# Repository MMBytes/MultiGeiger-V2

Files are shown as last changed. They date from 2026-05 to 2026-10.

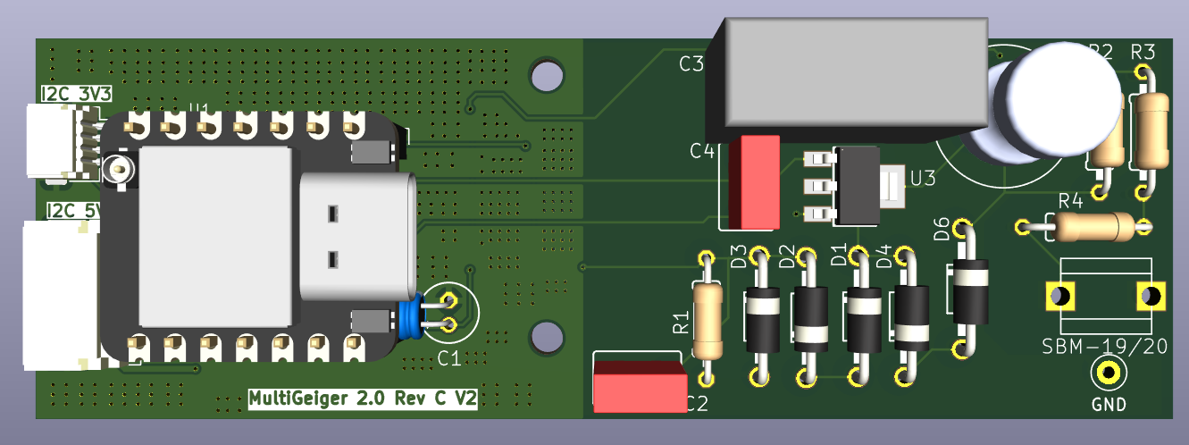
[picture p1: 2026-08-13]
Hardware/Revision_C/Deliverables/Renderings/3D TOP View.png

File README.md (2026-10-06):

# MultiGeiger V2 (ESP-IDF native)

A ground-up C rewrite of the [MultiGeiger](https://github.com/ecocurious2/MultiGeiger) radiation sensor firmware, ported from Arduino / PlatformIO to **native ESP-IDF 6.0**. Runs on **eleven** ESP32 / ESP32-S3 / ESP32-C5 board variants with a wide selection of optional environmental, particulate, noise, and ambient-light sensors. Uploads to **nine** public back-ends and publishes to MQTT (with Home Assistant Discovery) and remote syslog.

See the [releases page](https://github.com/MMBytes/MultiGeiger-V2/releases) for the latest build and per-release notes.

## What it does

- Counts Geiger pulses and computes CPM and µSv/h with a **runtime-selectable tube type** (Si22G / SBM-20 / SBM-19 / Unknown) configured on `/config` — no rebuild required.
- Drives the HV flyback boost converter from on-chip GPIO timing (no Arduino dependency).
- Optional **environmental sensing**: temperature, humidity, pressure, sea-level-adjusted pressure.
- Optional **PM (particulate matter)**: PM1 / PM2.5 / PM4 / PM10 plus number concentrations and typical particle size.
- Optional **noise**: LAeq / LAmin / LAmax dB(A).
- Optional **ambient light**: lux (two sensor families supported).
- Optional **air-quality index**: NOx index from a Sensirion SGP41 (log, `/status` and MQTT/Home Assistant only — no upload target carries it).
- Optional **standalone CSV logging** to a microSD card: one row of every attached sensor's readings per cycle, timestamped from the GNSS clock, for nodes deployed without a network.
- **Battery telemetry** (voltage, state of charge) on boards with an onboard MAX17048 fuel gauge.
- Optional **GNSS position display** — auto-detected PA1010D or MAX-M10S receiver shows fix, satellites, HDOP, lat/lon (OpenStreetMap link), and altitude on `/status`; display-only (NTP is the sole time source).
- Per-cycle upload (default 150 s, configurable 10 s – 1 h) to any subset of **nine** public back-ends.
- **MQTT publish** with 24 Home Assistant Discovery entities, three TLS modes including custom CA.
- **Remote syslog** (UDP 514, RFC 5424) for centralised log aggregation.
- **Hourly FTP/FTPS** upload of the on-device log ring buffer.
- **CPM history graph** on `/status` — 60-minute and 24-hour inline SVG with gridlines and a `HH:MM` time axis; rolling **cpm5 / cpm15** 5- and 15-minute averages fed to GMCMap and ThingSpeak.
- **Web UI** at `http://<device>/` — `/config` (settings), `/status` (live metrics + per-target TX stats + per-sensor presence + CPM graph), `/update` (OTA), `/log` (in-memory log ring). On PSRAM boards, ticking **Serve the web UI over HTTPS** on `/config` (off by default; applies after "Save and restart") moves the UI to `https://<device>/` with a per-device self-signed certificate (`/cert.pem` to import, SHA-256 fingerprint on `/`); port 80 then keeps `/log`, `/api/env` and `/cert.pem` plain and redirects everything else.
- **Crash recovery**: ESP-IDF panic handler writes a coredump to a dedicated flash partition; downloadable post-reboot via `GET /coredump.elf` (no USB required).
- **OLED status display** (SSD1306 128×64, also supports SparkFun SerLCD I²C and NeoPixel tick on supported boards).
- **NTP** with up to three configurable servers and POSIX TZ string.

## Supported hardware

### Boards (eleven build targets)

| Build target | MCU / module | Flash | Notes |
|---|---|---|---|
| `heltec_v2` | Heltec WiFi Kit 32 V2 (ESP32-D0WDQ6) | 8 MB | Onboard SSD1306 OLED. The original target — most production deployments. |
| `heltec_v2_4mb` | Heltec WiFi Kit 32 V2 clone | 4 MB | Same module silicon, smaller flash. Tight on heap during OTA — see V2.4.13 teardown logic in `main.c`. |
| `feathers3_d` | Unexpected Maker FeatherS3 with display (ESP32-S3) | 8 MB | Two STEMMA QT connectors (STEMMA1 on IO8/IO9, STEMMA2 LDO-gated on IO15/IO16). External I²C OLED via STEMMA. PSRAM — WiFi/lwIP/mbedTLS offloaded to PSRAM for sustained heap headroom. |
| `adafruit_qtpy_esp32_pico` | Adafruit QT Py ESP32-PICO | 8 MB | Compact form factor. Optional NeoPixel tick on pulse. PSRAM. |
| `seeed_xiao_esp32s3` | Seeed Studio XIAO ESP32-S3 | 8 MB | Tiny 21×17.5 mm — shares QT Py form factor + Geiger pin map (A0 / A1 / SCK), so one PCB design works for both. Onboard user LED blinks per pulse. PSRAM. |
| `heltec_wifi_lora32_v4_r2` | Heltec WiFi LoRa 32 V4 — base/R2 variant (ESP32-S3R2) | 16 MB | Third-party PCB: the standard Multigeiger V2 mainboard populated with this module instead of the Heltec V2. Onboard SSD1315 OLED on a dedicated, always-on I²C bus separate from the env-sensor bus. 2 MB in-package PSRAM. **LoRaWAN uplink** (V2.6.23+) via an onboard SX1262 (RadioLib 7.2.1, OTAA/Class A) — see the LoRaWAN section below. |
| `sparkfun_thing_plus_esp32s3` | SparkFun Thing Plus ESP32-S3, WRL-24408 (ESP32-S3-MINI-1) | 4 MB | Second-source MCU for the FeatherS3-D-format carrier PCB — same Feather footprint, drop-in alternative to `feathers3_d` on the same board. External I²C OLED via Qwiic, onboard MAX17048 fuel gauge, onboard WS2812 NeoPixel (always-on rail, no power-gate GPIO). 2 MB in-package PSRAM. |
| `sparkfun_thing_plus_esp32c5` | SparkFun Thing Plus ESP32-C5, WRL-30678 (ESP32-C5-WROOM-1) | 8 MB | First single-core/RISC-V target. Its own Thing Plus carrier (not a drop-in for the FeatherS3-D board). External I2C OLED via Qwiic, onboard MAX17048 fuel gauge, onboard WS2812 NeoPixel (always-on rail via pull-up, no power-gate GPIO). 8 MB in-package PSRAM. |
| `adafruit_esp32s3_tft_feather` | Adafruit ESP32-S3 TFT Feather, #5483 (ESP32-S3) | 4 MB | Shares the FeatherS3-D-format carrier PCB. Onboard 240×135 ST7789 color SPI TFT (esp_lcd, 5-page rotation only — no radiation single-page layout) instead of an external I²C OLED; shared TFT/STEMMA-QT power gate on GPIO21. Onboard WS2812 NeoPixel. 2 MB external QSPI PSRAM (feathers3_d-class, not in-package). |
| `adafruit_esp32_feather_v2` | Adafruit ESP32 Feather V2, #5400/#5900 (ESP32-PICO-MINI-02) | 8 MB | Second-source MCU (original ESP32 LX6, not S3) for the Feathers3d_new_pcb shared carrier. External I²C OLED wired to the header SDA/SCL pins, NOT the board's onboard STEMMA QT connector — NEOPIXEL_I2C_POWER only gates that connector's own regulator, and it isn't driven until neopixel_init() runs after sensor/display probing, so a display wired to the connector would never be found. Onboard WS2812 NeoPixel. No fuel gauge, so no battery telemetry (the board's GPIO35 battery divider is not read). 2 MB in-package PSRAM. |
| `adafruit_esp32s3_feather_4mb_2mbpsram` | Adafruit ESP32-S3 Feather, 4MB/2MB PSRAM, STEMMA QT, #5477 (ESP32-S3) | 4 MB | Shares the Feathers3d_new_pcb carrier PCB. No onboard display — external I²C OLED via STEMMA QT, probe-detected. Onboard MAX17048 fuel gauge, onboard WS2812 NeoPixel. Single STEMMA QT I²C bus power-gated on GPIO7 (no always-on bus) — same pattern as `adafruit_esp32s3_tft_feather`'s gate, different GPIO. Onboard red "#13" LED (not the NeoPixel) flashes on each Geiger pulse. 2 MB external QSPI PSRAM (feathers3_d-class, not in-package). |

Every build takes a `-DBOARD=<target>` argument — see [Build from source](#build-from-source). All boards share the same `main/` source tree; differences are isolated in per-board `sdkconfig.defaults.<board>` and HAL pin map. PSRAM boards additionally include `sdkconfig.defaults.psram` (WiFi roaming app + PSRAM offload knobs).

### LoRaWAN uplink (heltec_wifi_lora32_v4_r2 only)

OTAA/Class A uplink over an onboard SX1262 (RadioLib 7.2.1), configured in a dedicated **`/config` LoRaWAN section** (all-region frequency-plan dropdown, DevEUI/JoinEUI/AppKey entry, join status; session keys persist in NVS across reboots). Ports 1 and 2 are byte-identical to the Multigeiger V1.9 Arduino firmware's TTN uplinks — paste `docs/ttn_payload_formatter.js` into TTN Console as a Custom Javascript payload formatter to decode them. Respect the LoRaWAN Fair Use Policy: keep the transmission interval at **5 minutes or longer** when LoRaWAN is enabled.

### Geiger tube

The tube type is a runtime **`/config` dropdown** — no rebuild required to switch tubes:

| Option | cps → µSv/h | Notes |
|---|---|---|
| **Unknown** | — (dose suppressed) | CPM reported; µSv/h field omitted from all uploads |
| **SBM-20** | 1 / 2.47 | Energy-compensated cylindrical tube |
| **SBM-19** | 1 / 9.81888 | Large pancake, lower background |
| **Si22G** | 1 / 12.2792 | **Default** — empirical vs. odlinfo.bfs.de reference |

Calibration factors from the upstream MultiGeiger (`ecocurious2 / t-pi tube.cpp`). The selected tube is shown on the `/status` Radiation card and in the boot config dump. Changing it in `/config` applies live (no reboot). CPM counting, HV timing, and dead-time gating are all tube-agnostic.

### Environmental sensors (auto-detected on I²C)

| Sensor | Address | Provides | Notes |
|---|---|---|---|
| **SHT45** | 0x44 | Temperature, humidity | Sensirion successor to SHT3x. PTFE filter variant supported. |
| **BME280** | 0x76 / 0x77 | Temperature, humidity, pressure | Bosch — original upstream sensor. |
| **BME688** | 0x76 / 0x77 | Temperature, humidity, pressure | Bosch — gas channel currently unused. |
| **BMP390** | 0x76 / 0x77 | Temperature, pressure | Bosch — high-accuracy barometric. |
| **BMP581** | 0x46 / 0x47 | Temperature, pressure | Bosch latest-gen — sub-Pa noise floor. |

The driver mix lets a node combine, e.g., SHT45 (best RH) + BMP581 (best pressure) on the same bus. The firmware picks the right reading per measurand from whichever sensors responded at boot.

### Specialty sensors (auto-detected on I²C)

| Sensor | Address | Provides | Notes |
|---|---|---|---|
| **Sensirion SPS30** | 0x69 | PM1 / PM2.5 / PM4 / PM10 mass, N05–N10 number concentrations, typical particle size | Adds the SPS30_* field group to all upload targets. |
| **hbitter DNMS** | 0x55 | LAeq / LAmin / LAmax dB(A) | Nettigo NAM-style Teensy-based noise module. Adds DNMS_noise_* fields. |
| **ALS-PT19** | (analog) | Ambient light (lux) | Onboard FeatherS3-D photodiode on ADC1_CH3. |
| **VEML7700** | 0x10 | Ambient light (lux) | Vishay I²C, alternative to ALS-PT19. |
| **PA1010D** | 0x10 | GNSS position + time (display-only) | Adafruit 4415 (MediaTek MT3333). Detected by live NMEA sniff — disambiguates from a VEML7700 at the same address. |
| **MAX-M10S** | 0x42 | GNSS position + time (display-only) | SparkFun Qwiic (u-blox DDC). Factory chip serial queried via UBX-SEC-UNIQID and shown on `/status`. |
| **Sensirion SGP41** | 0x59 | NOx index | VOC + NOx gas sensor; only the NOx index is surfaced (log / `/status` / MQTT). Runs its own sampling task — it needs a 1 Hz conditioning cadence. |
| **MAX17048** | 0x36 | Battery voltage, state of charge | Onboard fuel gauge on the FeatherS3-D, SparkFun Thing Plus and Adafruit Feather boards that carry one. |

A microSD socket (SDMMC 4-bit on ESP32-S3 boards, SPI where the chip has no SDMMC host) enables the standalone CSV logger when present; see `main/sd_logger.h` for the file layout.

### Displays

- **SSD1306 OLED** 128×64, I²C 0x3C or 0x3D — auto-probe both addresses (V2.4.19).
- **SparkFun SerLCD** (I²C variant) — alternative line-based display.
- **NeoPixel** tick-per-pulse on supported boards (configurable colour / brightness via `display_mode`).
- Built-in **speaker** click on pulse (configurable, off by default for sealed-tube installs).

## Upload targets

All **nine** targets are fully optional and independently configurable. Each has per-target circuit-breaker logic (V2.3.x) — 3 consecutive all-retry failures suspend that target for 20 cycles to prevent failed TLS handshakes from fragmenting heap.

| Target | Endpoint | Auth | Fields posted |
|---|---|---|---|
| **Madavi** | `api-rrd.madavi.de/data.php` (HTTP / HTTPS) | none | T/H/P; PM and noise are POSTed but the legacy server only graphs T/H/P |
| **sensor.community** | `api.sensor.community/v1/push-sensor-data/` (HTTP / HTTPS) | X-Sensor = chip ID | Radiation (X-PIN 19), T/H/P (11), PM (1), noise (15) — split bodies per pin |
| **Radmon** | `radmon.org/radmon.php?function=submit` (HTTP / HTTPS) | basic auth user/pw | Radiation CPM only |
| **openSenseMap** | `ingress.opensensemap.org/boxes/<BOX_ID>/data?luftdaten=1` (HTTPS) | Box ID in URL + optional raw access token (no `Bearer ` prefix) | Combined Luftdaten body |
| **aqi.eco** | `api.aqi.eco/update/<TOKEN>` (HTTPS) | token in URL | Combined Luftdaten body with `esp8266id` field |
| **GMCMap** | `gmcmap.com/log2.asp` (HTTP only) | Account ID + Geiger counter ID in URL | Radiation CPM + ACPM (5-min rolling average). Skipped when tube disabled. |
| **ThingSpeak** | `api.thingspeak.com/update` (HTTP / HTTPS) | Write API key | field1=CPM, field2=µSv/h, field3=cpm5, field4=cpm15, field5–7=T/H/P. Skipped when tube disabled. |
| **ThingSpeak PM** | `api.thingspeak.com/update` (HTTP / HTTPS) | Separate write API key | field1–4=PM1/PM2.5/PM4/PM10, field5–7=T/H/P, field8=typical particle size. Skipped when no PM sensor. |
| **openSenseMap STAGING** | `upload.staging.opensensemap.org/boxes/<BOX_ID>/data?luftdaten=1` (HTTPS only) | Independent Box ID + access token | Same Luftdaten body as production OSM — lets a node mirror to prod + staging simultaneously. |

Each target shows live per-target stats on `/status` — attempted / succeeded counters, last HTTP status, last attempt time, current breaker state.

Cert verification uses the Mozilla CA bundle baked into flash. Per-target "insecure mode" available for self-hosted instances. TLS 1.2 and TLS 1.3 both supported.

## Observability

### MQTT (V2.4.2–V2.4.6)

Publish-only MQTT 3.1.1 client with three TLS modes:

- **Mode 0** — plain TCP (broker on LAN)
- **Mode 1** — TLS via Mozilla CA bundle (public broker)
- **Mode 2** — TLS via user-supplied custom CA PEM (self-signed broker, e.g. a Pi running Mosquitto on the LAN)

When `mqtt_ha_discovery` is enabled (default), the firmware publishes 24 Home Assistant Discovery entities at boot — radiation, all detected sensors, WiFi RSSI, per-target TX stats, etc. — auto-gated on driver presence. HA picks them up without manual configuration.

Topic layout: `<prefix>/<chip-id>/state` (full state JSON every cycle) plus `<prefix>/<chip-id>/availability` for the LWT.

### Syslog (V2.4.15)

UDP syslog client (port 514, configurable). **RFC 5424** framing with `local0` facility. Every applog line mirrors to syslog when enabled. Before the wall clock is valid (pre-NTP sync), the timestamp is the NILVALUE `-` — a stock rsyslog collector falls back to its own receive time, correctly dating boot-banner and config-dump lines. Once NTP has synced, the timestamp is local RFC 3339 with a numeric UTC offset (e.g. `2026-06-13T20:45:50+10:00`), matching the in-message device time shown on `/status`. The per-cycle log line reports `syslog udp: tx=N drops=M` so device-side UDP packet loss is visible (V2.5.29).

### FTP / FTPS log upload (V2.0.x +)

Configurable interval (1 min – 10 090 min, ~7 days; default hourly) upload of the on-device log ring buffer to an FTP server. TLS supported (FTPS explicit-mode, AUTH TLS, TLS 1.2 and 1.3 both work). Cleared after successful upload; carried over across reboot via NVS.

### CPM history graph (V2.5.6)

Two-tier in-RAM ring: 60 one-minute samples + 24 one-hour samples (~250 bytes, all boards). Sampled from a monotonic pulse counter independent of the destructive per-cycle `tube_read()`, so the TX interval has no effect on graph resolution. Displayed as an **inline SVG** on `/status` with horizontal CPM gridlines and a `HH:MM` time axis. Also drives the **cpm5 / cpm15** rolling averages (means of the last 5 / 15 minute samples), fed to GMCMap as ACPM and to ThingSpeak as field3 / field4.

### Coredump on panic (V2.4.18)

64 KB dedicated coredump partition. The ESP-IDF panic handler writes the panicking task's register state + stack snapshot before reset. Recoverable post-reboot via `GET /coredump.elf` (basic auth gated) — no USB needed once flashed. Decode with `espcoredump.py`.

## Security

V2.3.33 web security audit + V2.4.x follow-ups (see CHANGELOG):

- **Basic auth** on `/config`, `/update`, `/reboot`, `/coredump.elf` (user `admin`, password = configured AP password).
- **Constant-time password comparison** to defeat timing oracles.
- **CSRF protection**: POSTs to `/config` / `/update` / `/reboot` require an `Origin` header matching the device's URL — protects against drive-by browser POSTs. **Note for curl users**: add `-H "Origin: http://device:port"` or you'll get a 403.
- **OTA size clamp**: rejects an image larger than the target OTA slot before writing (2 MB on 8 MB-flash boards, 1.875 MB on 4 MB-flash boards).
- **X-Frame-Options: DENY** on all responses.
- **TX is paused during OTA** (V2.4.24): scheduled cycles skip while an OTA upload is in progress, giving the OTA the full WiFi airtime.

- **HTTPS for the device UI** (V2.8.0, PSRAM boards): optional, per-device self-signed certificate, see "What it does" above.

Deferred for future work: signed OTA images, NVS encryption, rate limiting. The device is designed for a trusted LAN; do not expose it to the internet.

## Installation

### Flashing a prebuilt release (no build environment needed)

Every [release](https://github.com/MMBytes/MultiGeiger-V2/releases) attaches per-board artefacts. Pick the bundle that matches your board — see the release notes for the file naming.

**Browser-based first flash (no tools needed):** The [MultiGeiger-V2 web flasher](https://mmbytes.github.io/MultiGeiger-V2/) supports Chrome / Edge via the WebSerial API — connect the board over USB, select your board, and flash the latest release directly from the browser.

**`esptool` first flash:** Install [`esptool`](https://github.com/espressif/esptool) (`pip install esptool`); replace `COM3` with your actual serial port.

**First flash of a blank / fresh / bricked device — use `geiger_v2_merged_<board>.bin`:**

```
esptool --chip esp32 --port COM3 write-flash 0x0 geiger_v2_merged_heltec_v2.bin
```

Use `--chip esp32s3` for the ESP32-S3 boards and `--chip esp32c5` for the SparkFun Thing Plus ESP32-C5. FeatherS3-D additionally needs `--before no-reset --after no-reset` and the BOOT+RST button dance.

The merged image bundles the bootloader, partition table, OTA slot pointer, and the app at their correct flash offsets — a single-file factory flash. Each release also attaches the separate parts (`bootloader_<board>.bin`, `partition-table_<board>.bin`, `ota_data_initial_<board>.bin`), the matching debug symbols (`elf_<board>.zip`, for decoding a coredump) and a `SHA256SUMS` file.

**Upgrading a device already running this firmware:**

- **OTA (recommended)** — browse to `http://<device-ip>/update`, log in (`admin` / your configured AP password), pick the `geiger_v2_<board>.bin` artefact for your board. No cable, keeps your NVS (WiFi credentials, MQTT broker, etc.) intact.
- **Board revision matters**: the firmware has no runtime board-revision detection. Before flashing an older carrier or mainboard, read the compatibility table in [`Hardware/README.md`](Hardware/README.md).

### First boot

The device comes up as a WPA2-protected WiFi access point named after its chip ID (`esp32-<number>`, e.g. `esp32-1234567`). The AP password is the configured AP password — `ESP32Geiger` on a fresh device. Join it, browse to `http://192.168.4.1/config`, and set WiFi credentials, the AP/admin password and your back-end choices. The AP stays up for about two minutes after boot; after that window, or a manual reboot, the device joins your network in STA mode.

Default credentials (change these on first login — the same password protects the web UI and the setup AP):

| Field | Default |
|---|---|
| Username | `admin` |
| Password | `ESP32Geiger` |

## Build from source

Needed only if you want to modify the firmware.

### Requirements

- [ESP-IDF v6.0.3](https://docs.espressif.com/projects/esp-idf/en/stable/esp32/get-started/index.html) — pure IDF, not arduino-esp32, not PlatformIO. Releases are built with exactly v6.0.3; CMake warns if a different IDF is in use.
- A Windows / Linux / macOS host with the IDF tools installed
- USB cable with data lines

### Commands

With the IDF environment sourced (`export.ps1` on Windows, `export.sh` on Linux/macOS):

```
idf.py -B build_heltec_v2 -DBOARD=heltec_v2 build
idf.py -B build_heltec_v2 -DBOARD=heltec_v2 -p <PORT> flash monitor
idf.py -B build_heltec_v2 -DBOARD=heltec_v2 merge-bin -o geiger_v2_merged_heltec_v2.bin   # single-file factory image
```

`-DBOARD=` selects the chip target, the board macros and the per-board `sdkconfig.defaults.<board>` overlay in one go — do not pass `SDKCONFIG_DEFAULTS` yourself. Substitute `heltec_v2_4mb`, `feathers3_d`, `adafruit_qtpy_esp32_pico`, `seeed_xiao_esp32s3`, `heltec_wifi_lora32_v4_r2`, `sparkfun_thing_plus_esp32s3`, `sparkfun_thing_plus_esp32c5`, `adafruit_esp32s3_tft_feather`, `adafruit_esp32_feather_v2`, or `adafruit_esp32s3_feather_4mb_2mbpsram` for other boards, and use a matching `-B build_<board>` directory: the generated `sdkconfig.<board>` cache is per board, so boards never pollute each other.

Host-side unit tests for the pure helpers need only a C compiler:

```
gcc -I main -Wall -Wextra -Werror -std=c11 -o test/run test/test_main.c && ./test/run
```

(`_test.cmd` wraps the same on Windows.) Static analysis runs in CI with cppcheck 2.22.0, one leg per board.

Optional: `git config core.hooksPath .githooks` enables a pre-commit scan that refuses to commit private-network data (LAN/MAC/hostname shapes) — the same check CI runs on every push.

### Release workflow

`git tag -a V2.X.Y && git push --tags` is the release ceremony. GitHub Actions `release.yml` first runs the cheap gates (host tests, cppcheck on every board, a `## V2.X.Y` section present in `CHANGELOG.md`), then builds all eleven boards (each build also verifies that `VERSION_STR` equals the tag and that the image fits its OTA slot), creates the GitHub Release with the artefacts, `SHA256SUMS` and the CHANGELOG section as body, and finally publishes the web flasher — only if the tag is the newest release, so re-running an old tag never rolls the flasher back.

## Repository layout

```
main/                       firmware C sources
  main.c                    entry point, WiFi state machine, cycle loop
  tube.c                    pulse ISR + HV driver timing
  tube_types.c / .h         tube characteristics table (cps→µSv/h factors per tube type)
  tube_pcnt.c / .h          optional PCNT width-filter for narrow-pulse characterisation
  tube_logic.h              pure inline helpers: clamp_u32, gmc_classify, guard policy
  config.c / config_fields.def
                            NVS-backed config, X-macro schema
  http_server.c             web UI (/, /config, /status, /update, /log, /coredump.elf)
  transmission.c            upload pipeline: Madavi / SC / Radmon / OSM / aqi / GMC / ThingSpeak
  mqtt.c / mqtt_discovery.c MQTT 3.1.1 publish + HA Discovery
  syslog.c                  RFC 5424 UDP syslog client
  log_ftp.c                 FTP/FTPS log upload
  net_arp.c                 gratuitous ARP (mesh-AP blackhole prevention)
  periodic.c                housekeeping (PSA refresh + ARP safety-net)
  coredump.c                /coredump.elf streaming from partition
  ntp.c                     SNTP with configurable POSIX TZ string
  history.c / .h            in-RAM CPM history ring + cpm5/cpm15 rolling averages
  gnss.c / .h               GNSS driver: PA1010D + MAX-M10S auto-detected, display-only
  env_sensor.c              umbrella for T/H/P drivers
  sht45.c bmp581.c bmp390.c bme688.c bme280.c
                            individual T/H/P drivers
  pm_sensor.c sps30.c       particulate matter
  noise_sensor.c dnms.c     noise (DNMS / NAM)
  als.c veml7700.c          ambient light
  sgp41.c                   SGP41 NOx index (+ sensirion_crc.h, sensirion_gas_index_algorithm.c)
  fuel_gauge.c              MAX17048 battery fuel gauge
  sd_card.c sd_logger.c     microSD mount + standalone CSV logger
  lorawan.cpp lorawan_codec.h
                            LoRaWAN uplink (heltec_wifi_lora32_v4_r2 only)
  telemetry.c / .h          sensor-reading registry shared by SD logger and status
  env_api.h                 /api/env JSON contract (served by http_server.c)
  tls_cert.c / tls_logic.h  per-device HTTPS certificate (generation, NVS storage)
  display.c display_tft.c display_serlcd.c neopixel.c led.c
                            display drivers (OLED / ST7789 TFT / SerLCD) + LED pulse-tick
  speaker.c / speaker_logic.h
                            pulse tick (boards with speaker)
  i2c_bus.c                 shared I²C bus handle + mutex
  applog.c                  in-memory log ring buffer
  diag.c / .h               I²C error counter + per-cycle heap split logging
  util.h                    clamped string helpers, URL encoding
  hal.h                     per-board pin map + capability flags
  sysinfo.h                 chip model string, reset-reason string
  main_status.h             request-restart IPC (main loop ← HTTP/TX workers)
partitions.csv              factory + dual-OTA (2 MB each) + coredump (64 KB) on 8 MB flash
partitions_4mb.csv          dual-OTA (1.875 MB each) + coredump for the four 4 MB-flash boards
                            (heltec_v2_4mb, sparkfun_thing_plus_esp32s3,
                            adafruit_esp32s3_tft_feather, adafruit_esp32s3_feather_4mb_2mbpsram)
sdkconfig.defaults.<board>  per-board IDF configuration
sdkconfig.defaults.psram    shared WiFi-roaming app + PSRAM-offload knobs (PSRAM boards)
CHANGELOG.md                per-release WHAT/WHY notes
docs/                       web flasher (index.html + manifests/ + vendored esp-web-tools),
                            TTN payload formatter
.github/workflows/          build.yml, release.yml, repo-checks.yml + the reusable
                            _host-test / _cppcheck / _build-boards gates
.github/scripts/            board-list consistency check, private-data scan,
                            CHANGELOG section extractor

Hardware/                   PCB design files — see Hardware/README.md for the
                            revision → board → minimum-firmware map
  Revision_A/               MultiGeiger V1.10 mainboard for the Heltec WiFi LoRa 32 V4 (Eagle)
  Revision_B/               FeatherS3-D-format carrier PCB (KiCad 8)
    geiger.kicad_pro / .kicad_pcb / .kicad_sch
                            KiCad 8 project sources
    0_Custom_Library.pretty / geiger.pretty
                            custom symbol + footprint libraries
    3d-Files/               3D STEP models for non-trivial parts
    Deliverables/
      Gerber Files/         fab-ready Gerbers
      Pick And Place Files/ assembly CSVs
      BOM/                  bill of materials
      Schematic/            schematic PDF
      Renderings/           3D rendered previews
      Supporting Files/     STEP export
  Revision_C/               shared-footprint PCB: QT Py ESP32-PICO or XIAO ESP32-S3
    (same sub-structure as Revision_B)
```

## PCB design files

Three PCB revisions are included in the `Hardware/` directory. [`Hardware/README.md`](Hardware/README.md) maps each revision to the modules it carries and the **minimum firmware** it needs — read it before flashing an older board.

### Revision A — MultiGeiger V1.10 mainboard

[`Hardware/Revision_A/`](Hardware/Revision_A/) is the Eagle project for the V1.10 iteration of the upstream MultiGeiger mainboard, re-laid for the Heltec WiFi LoRa 32 V4 (R2) module (`heltec_wifi_lora32_v4_r2` firmware, V2.7.1 or later), with Gerbers, pick-and-place CSV, BOM, schematic PDF and renderings.

- **Browse the schematic**: [`Hardware/Revision_A/Deliverables/Schematic/geiger-v2.pdf`](Hardware/Revision_A/Deliverables/Schematic/geiger-v2.pdf)

### Revision B — FeatherS3-D-format carrier

[`Hardware/Revision_B/`](Hardware/Revision_B/) is the full KiCad 8 project for the Feather-format carrier PCB (FeatherS3-D, SparkFun Thing Plus ESP32-S3 and the three Adafruit Feather targets share it), plus fabrication-ready Gerbers, pick-and-place CSVs, schematic PDF, BOM, and 3D STEP exports. Si22G tube; full BOM uses metal-film resistors and polypropylene HV capacitors throughout.

- **Browse the schematic**: [`Hardware/Revision_B/Deliverables/Schematic/geiger.pdf`](Hardware/Revision_B/Deliverables/Schematic/geiger.pdf)
- **3D renderings**: [`Hardware/Revision_B/Deliverables/Renderings/`](Hardware/Revision_B/Deliverables/Renderings/)
- **Re-fabricate at JLCPCB or similar**: upload the Gerbers + PnP CSV from `Deliverables/` directly, or open the `.kicad_pro` to regenerate

### Revision C — shared QT Py / XIAO footprint

[`Hardware/Revision_C/`](Hardware/Revision_C/) is a shared-footprint PCB that accepts either the Adafruit QT Py ESP32-PICO or the Seeed XIAO ESP32-S3 in the same U1 socket — both use the same Geiger pin map (HV_FET / GMC / interrupt on A0 / A1 / SCK), so one board runs both `adafruit_qtpy_esp32_pico` and `seeed_xiao_esp32s3` firmware builds. Same HV circuit as Revision B; no piezo (sealed-tube form factor). On-board Qwiic / STEMMA QT connector with on-board pull-ups.

- **Browse the schematic**: [`Hardware/Revision_C/Deliverables/Schematic/geiger.pdf`](Hardware/Revision_C/Deliverables/Schematic/geiger.pdf)
- **3D renderings**: [`Hardware/Revision_C/Deliverables/Renderings/`](Hardware/Revision_C/Deliverables/Renderings/)
- **Re-fabricate**: upload Gerbers + PnP CSV from `Revision_C/Deliverables/`

**License** for all three revisions: same GPL-3.0-or-later as the firmware.

## Documentation

- **Per-release notes**: [`CHANGELOG.md`](CHANGELOG.md) — full WHAT/WHY for every release since V2.3.23, headlines for older. GitHub release pages have the rest.
- **In-firmware**: `/status` shows live state including which drivers responded at boot, per-target TX stats, FTP / MQTT / syslog status, CPM history graph, and GNSS position if a receiver is detected.

## Attribution

This firmware is an **independent rewrite** of [MultiGeiger](https://github.com/ecocurious2/MultiGeiger) by the ecocurious2 project. Hardware design, sensor-community protocol compatibility, the Si22G calibration constant, and the upload-target conventions come from upstream; the C source in this repository shares no commits with it.

The MQTT / HA Discovery, MQTT TLS modes, openSenseMap support, aqi.eco support, GMCMap support, ThingSpeak support, syslog (RFC 5424), coredump-to-flash, multi-board build (FeatherS3 / QT Py / XIAO), runtime-selectable tube type, PCNT width filter, dead-time guard, CPM history graph and rolling averages, GNSS display, and most of the additional sensor drivers (SHT45, BMP581, BMP390, BME688, SPS30, DNMS, ALS-PT19, VEML7700, PA1010D, MAX-M10S) are net-new in V2.

## License

**GPL-3.0-or-later** — same as upstream MultiGeiger. See [LICENSE](LICENSE).

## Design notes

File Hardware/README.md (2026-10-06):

# Hardware

PCB designs that the MultiGeiger V2 firmware runs on. Three revisions are
tracked. Each is a complete design with fabrication outputs under its
`Deliverables/` folder: Gerbers (plus an order-ready zip), pick-and-place
CSV, BOM, schematic PDF and 3D renderings.

## Revision → board → firmware

| Directory | Board | Module it carries | Firmware target(s) | Minimum firmware | Tool |
|---|---|---|---|---|---|
| `Revision_A/` | MultiGeiger mainboard **V1.10** | Heltec WiFi LoRa 32 V4, base/R2 variant | `heltec_wifi_lora32_v4_r2` | **V2.7.1** | Eagle (`geiger-v2.sch` / `.brd`) |
| `Revision_B/` | FeatherS3-D-format carrier, **V2 layout** | Unexpected Maker FeatherS3-D, SparkFun Thing Plus ESP32-S3, Adafruit ESP32-S3 TFT Feather, Adafruit ESP32 Feather V2, Adafruit ESP32-S3 Feather #5477 | `feathers3_d`, `sparkfun_thing_plus_esp32s3`, `adafruit_esp32s3_tft_feather`, `adafruit_esp32_feather_v2`, `adafruit_esp32s3_feather_4mb_2mbpsram` | **V2.6.34** | KiCad 8 |
| `Revision_C/` | Shared-footprint carrier, **V2 layout** | Adafruit QT Py ESP32-PICO **or** Seeed XIAO ESP32-S3 in the same U1 socket | `adafruit_qtpy_esp32_pico`, `seeed_xiao_esp32s3` | **V2.6.34** | KiCad 8 |

Not in this directory:

- The Heltec WiFi Kit 32 V2 targets (`heltec_v2`, `heltec_v2_4mb`) run on the
  upstream [ecocurious2 MultiGeiger](https://github.com/ecocurious2/MultiGeiger)
  mainboard (V1.4, Eagle files in that repository's `docs/hardware/`).
- The SparkFun Thing Plus ESP32-C5 target has its own carrier; that design is
  not published here.

## Firmware compatibility — read before flashing

There is no runtime board-revision detection: **the firmware version is the
cutover line.** The pin maps live in `main/hal.h`, whose header comment is
the authoritative statement of this rule.

- **Rev B V2 and Rev C V2 layouts (the files tracked here)** need firmware
  **≥ V2.6.34**. That release moved the Geiger count and HV-FET signals to
  different socket pads to remove HV-to-counter crosstalk.
- **The original (pre-V2) Rev B / Rev C layouts** must stay on firmware
  **≤ V2.6.33**. Flashing a newer build onto an original carrier drives the
  HV FET PWM into the tube pickup and reads "counts" off the FET gate trace.
  Those layouts are superseded and not tracked.
- **V1.10 mainboard (Revision A)** needs firmware **≥ V2.7.1**. V2.6.34 was
  written against a pre-fabrication pad assignment that was never
  manufactured, so for this target V2.6.34 matches no physical board.
- **V1.9 mainboard** (an earlier third-party respin for the same module, not
  tracked) stays on **≤ V2.6.33**.

The browser flasher always installs the latest release, so it is only
suitable for boards in the first and third groups.

## Provenance

- **Revision A** is the V1.10 iteration of the upstream MultiGeiger mainboard
  lineage (ecocurious2 V1.4 → a third-party V1.9 respin for the Heltec WiFi
  LoRa 32 V4 module → this V1.10 rework: HV_CAP_FULL moved from GPIO2 to
  GPIO3 and GMC_COUNT to GPIO6 — the V2.6.34 design had those two the other
  way round and was never built — piezo on GPIO4/5). Kept in Eagle like its
  ancestors.
- **Revision B** and **Revision C** are this project's own KiCad 8 designs.
  They keep the upstream HV topology (flyback boost, zener-regulated rail,
  Si22G tube) and add module sockets, a Qwiic / STEMMA QT connector and
  (Rev C) a sealed, speaker-less form factor. The "V2 layout" of each is the
  current file; the first layout was replaced after the crosstalk
  investigation described in `main/hal.h`.

BOM part numbers are maintained at the source — the Revision A BOM is
generated, the Revision B / C part numbers live in a schematic field pushed
to the footprints — so edit there, not in the exported CSVs.

## Licence

All three designs: **GPL-3.0-or-later**, the same licence as the firmware
and as the upstream MultiGeiger project they descend from. See the
repository [LICENSE](../LICENSE). Upstream attribution: ecocurious2 /
MultiGeiger.

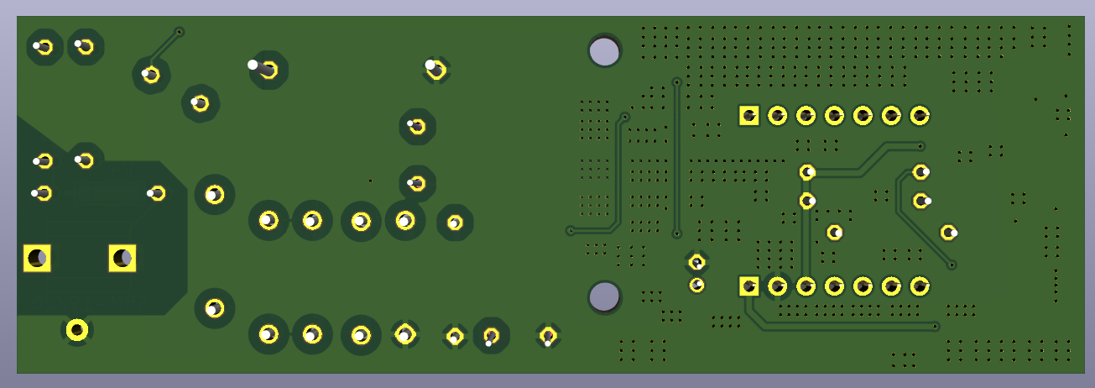
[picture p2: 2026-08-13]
Hardware/Revision_C/Deliverables/Renderings/3D BOTTOM View.png

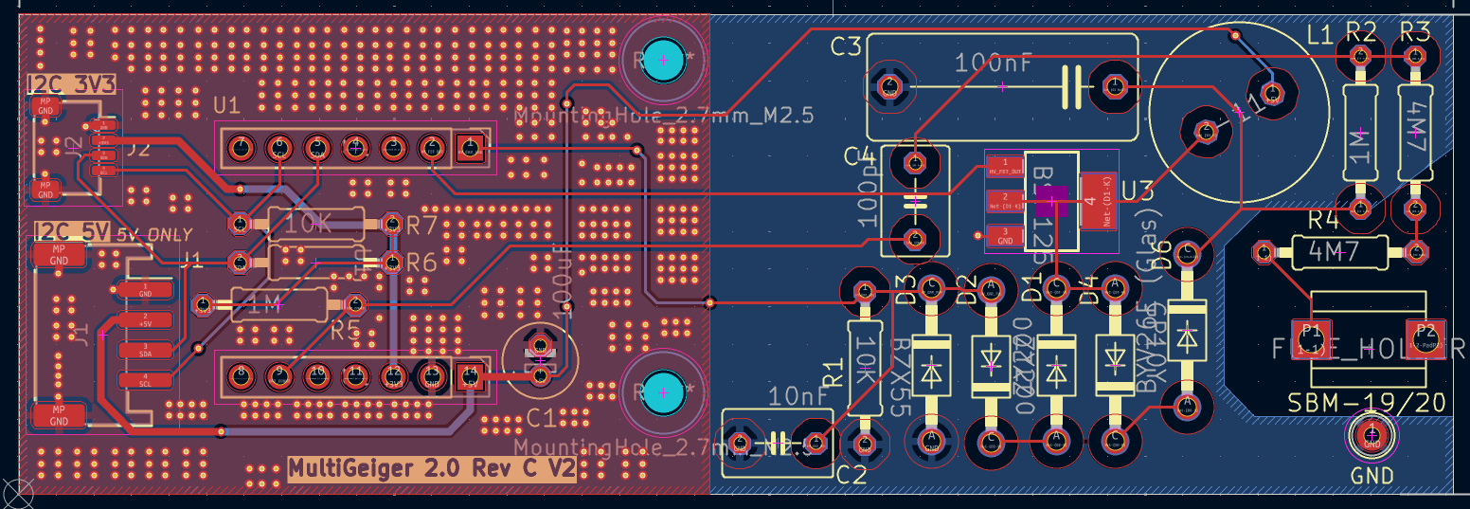
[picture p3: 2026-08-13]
Hardware/Revision_C/Deliverables/Renderings/PCB_VIEW.png

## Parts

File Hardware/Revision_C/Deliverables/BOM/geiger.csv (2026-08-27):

Reference | Qty | Value | Package | Part Number
C1 | 1 | 100uF/16V | Through Hole,D6.3xL9mm,P=2.5mm on 2.03mm land | 16SEPC100MW
C2 | 1 | 10nF/100V | Through Hole,P=5mm | MKP2D021001B00KSSD
C3 | 1 | 100nF/630V | Through Hole,P=15mm | R76PI31005050J
C4 | 1 | 100pF/1000V | Through Hole,P=5mm | FKP2O101001D00JSSD
D1,D2 | 2 | ZY200 | DO-41 | ZY200
D3 | 1 | BZX79-B3V3 (board value: BZX55) | DO-35 body in DO-41 land | BZX79-B3V3,133
D4 | 1 | BYV26E (Glas) | DO-41 | BYV26E
D6 | 1 | GP10Y | DO-41 | GP10Y
J1 | 1 | I2C 5V | Connector_JST:JST_PH_S4B-PH-SM4-TB_1x04-1MP_P2.00mm_Horizontal | PH-4P
J2 | 1 | I2C 3V3 | Connector_JST:JST_SH_SM04B-SRSS-TB_1x04-1MP_P1.00mm_Horizontal | SM04B-SRSS-TB(LF)(SN)
J3 | 1 | GND wire loop (tube cathode return) | Test point loop,D1.8mm,Drill1.0mm
L1 | 1 | 150mH | Through Hole,P=5mm | 11P-154J-50
R1 | 1 | 10k (pulse - keep UXB) | Axial 0207,P=10.16mm | UXB02070F1002AR100
R6,R7 | 2 | 10k I2C pull-ups (any 2k2-10k) | Axial 0207,P=10.16mm | UXB02070F1002AR100
R2,R5 | 2 | 1M | Axial 0207,P=10.16mm | RNV14FAL1M00
R3,R4 | 2 | 4M7 (Si22G; 2M7 for SBM-19/20) | Axial 0207,P=10.16mm | RNV14FAL4M70
SBM-19/20 | 2 | Tube holder clip (1 on PCB + 1 flying to J3) | Fuse clip 6.3x32,THT,P=7.62mm | 8040.0003
U1 | 1 | XIAO ESP32-S3 / Adafruit 5395 socket | 2x THT female header,P=2.54mm
U3 | 1 | BSP125H6327 | SOT223 | BSP125H6327

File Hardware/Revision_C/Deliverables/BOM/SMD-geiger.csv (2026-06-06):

Designator | Qty | Value | Package | Part Number
J1 | 1 | I2C 5V | Connector_JST:JST_PH_S4B-PH-SM4-TB_1x04-1MP_P2.00mm_Horizontal | C50137
J2 | 1 | I2C 3V3 | Connector_JST:JST_SH_SM04B-SRSS-TB_1x04-1MP_P1.00mm_Horizontal | C160404
U3 | 1 | BSP125H6327 | SOT223 | C123756

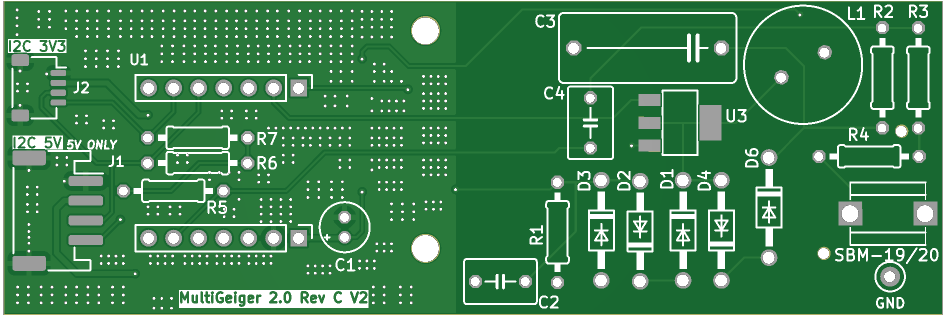
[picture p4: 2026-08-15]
Hardware/Revision_C/Deliverables/Renderings/3D_TOP_VIEW_NO_PARTS.png

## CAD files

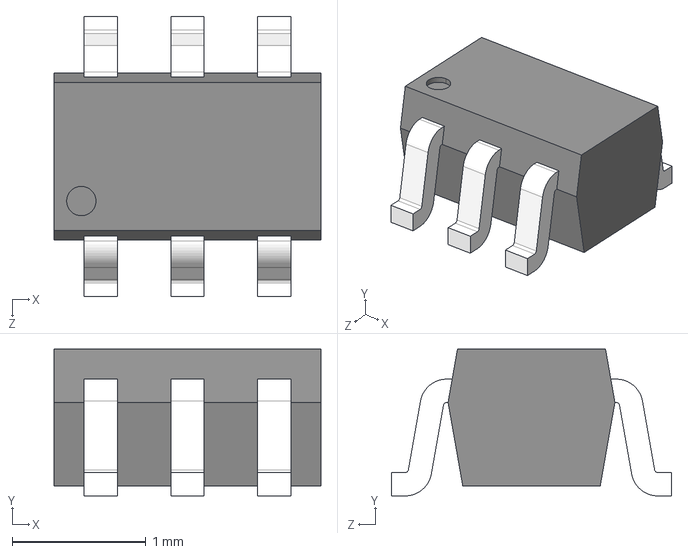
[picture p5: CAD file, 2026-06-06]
Hardware/Revision_C/3d-Files/BSS138PS/BSS138PS.step
2.00 x 1.10 x 2.10 mm

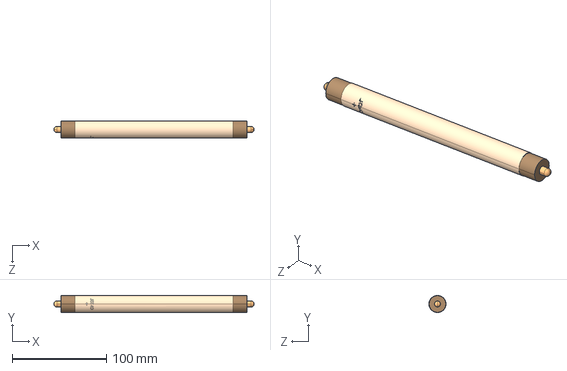
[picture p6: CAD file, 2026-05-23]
Hardware/Revision_C/3d-Files/User Library-SI-22G/User Library-SI-22G.STEP
212.6 x 18.2 x 18.2 mm

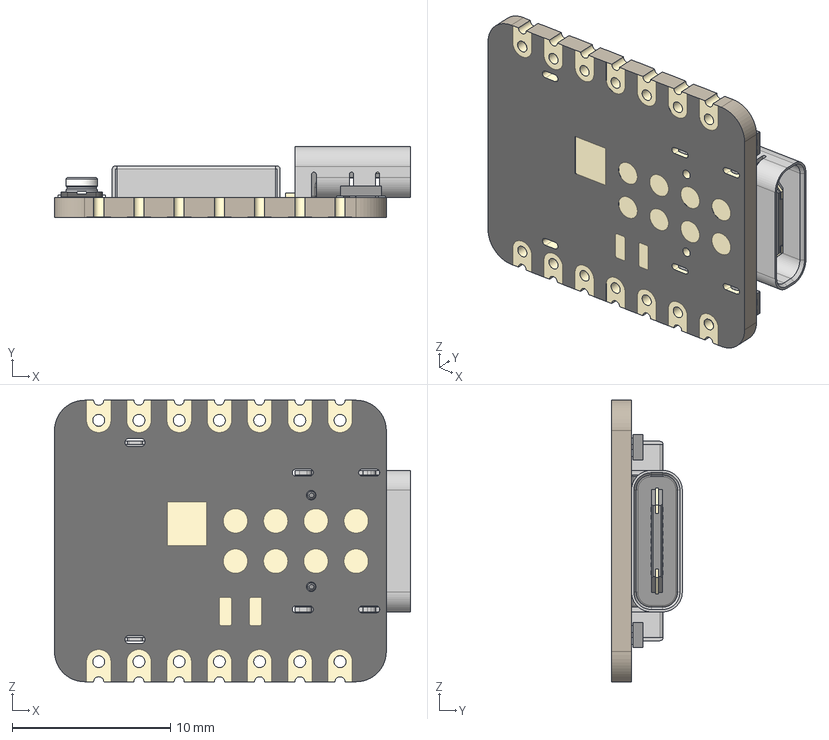
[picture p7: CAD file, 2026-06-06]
Hardware/Revision_C/3d-Files/XIAO-ESP32S3 v2.step
22.5 x 4.46 x 17.8 mm
BOSS-EXTRUDE14_8_
BOSS-EXTRUDE7_4_
BOSS-EXTRUDE7_3_
BOSS-EXTRUDE14_4_
BOSS-EXTRUDE14_2_
BOSS-EXTRUDE14_11_
BOSS-EXTRUDE7_7_
BOSS-EXTRUDE14_9_
BOSS-EXTRUDE14_3_
BOSS-EXTRUDE14_7_
MIRROR2
BOSS-EXTRUDE14_5_
BOSS-EXTRUDE14_12_
BOSS-EXTRUDE7_8_
BOSS-EXTRUDE7_1_
BOSS-EXTRUDE14_10_
BOSS-EXTRUDE7_9_
BOSS-EXTRUDE14_6_
BOSS-EXTRUDE14_1_
BOSS-EXTRUDE7_6_
BOSS-EXTRUDE7_2_
CUT-EXTRUDE5
BOSS-EXTRUDE7_5_
Shield
Pins x 2
U.FL-R-SMT-1_10_ v1

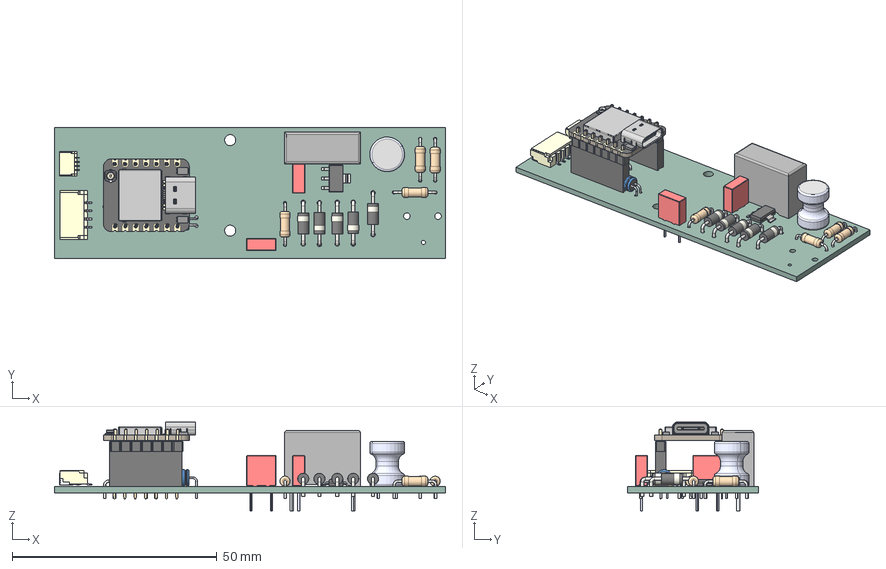
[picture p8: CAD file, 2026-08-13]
Hardware/Revision_C/Deliverables/Supporting Files/geiger.step
95.5 x 31.9 x 21.7 mm
bobina_100uH
R_Axial_DIN0207_L63mm_D25mm_P1016mm_Horizontal x 7
MKP2C021001B00JA00 x 2
D_DO-41_SOD81_P10.16mm_Horizontal x 5
SOT-223
BOSS-EXTRUDE14_8_
BOSS-EXTRUDE7_4_
BOSS-EXTRUDE7_3_
BOSS-EXTRUDE14_4_
BOSS-EXTRUDE14_2_
BOSS-EXTRUDE14_11_
BOSS-EXTRUDE7_7_
BOSS-EXTRUDE14_9_
BOSS-EXTRUDE14_3_
BOSS-EXTRUDE14_7_
MIRROR2
BOSS-EXTRUDE14_5_
BOSS-EXTRUDE14_12_
BOSS-EXTRUDE7_8_
BOSS-EXTRUDE7_1_
BOSS-EXTRUDE14_10_
BOSS-EXTRUDE7_9_
BOSS-EXTRUDE14_6_
BOSS-EXTRUDE14_1_
BOSS-EXTRUDE7_6_
BOSS-EXTRUDE7_2_
CUT-EXTRUDE5
BOSS-EXTRUDE7_5_
Shield
Pins x 2
U.FL-R-SMT-1_10_ v1
PinHeader_1x07_P254mm_Vertical x 2
PinSocket_1x07_P2.54mm_Vertical x 2
SM04B-SRSS-TB(LF)(SN) x 2
El Cap L/A
CFR_RB2_18X13.5X7.5_L18.5H13.6T7.7S15LL6F0.85
gei2028_PCB

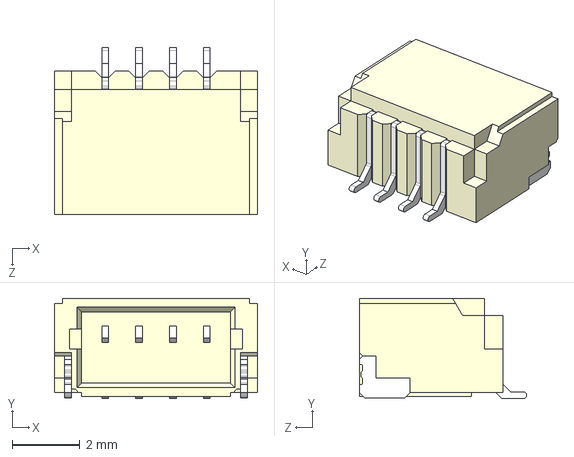
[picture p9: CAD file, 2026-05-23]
Hardware/Revision_C/3d-Files/SM04B-SRSS-TB--3DModel-STEP-269445.STEP
6.00 x 2.96 x 4.95 mm

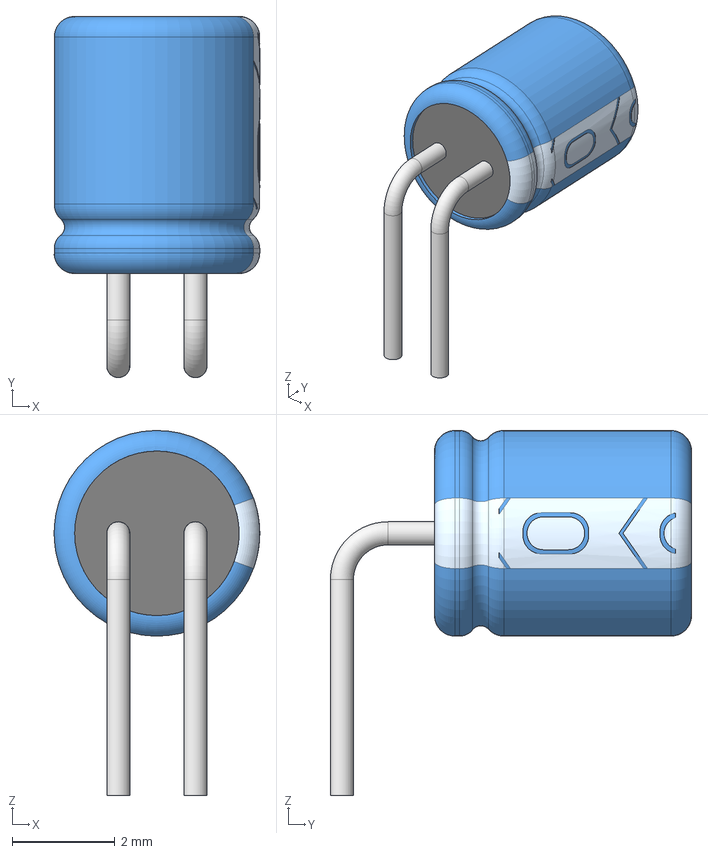
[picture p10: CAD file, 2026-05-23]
Hardware/Revision_C/3d-Files/ElCapLA-1.5-4x5.step
4.00 x 7.03 x 7.10 mm

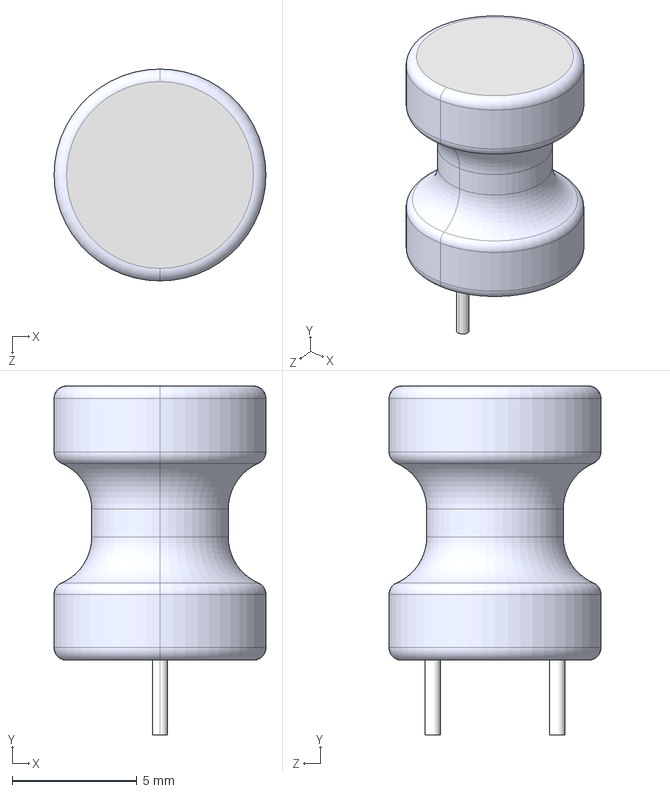
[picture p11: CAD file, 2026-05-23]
Hardware/Revision_C/3d-Files/bobina_100uH.STEP
8.50 x 14.0 x 8.50 mm

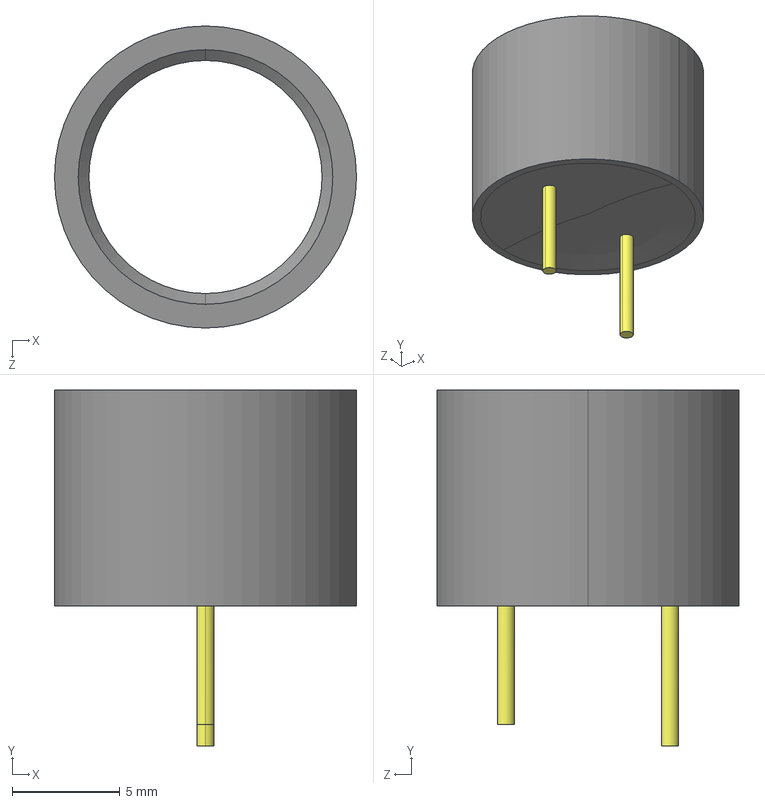
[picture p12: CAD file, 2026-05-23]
Hardware/Revision_C/3d-Files/CPT-1495CI-300--3DModel-STEP-1.STEP
14.0 x 16.5 x 14.0 mm

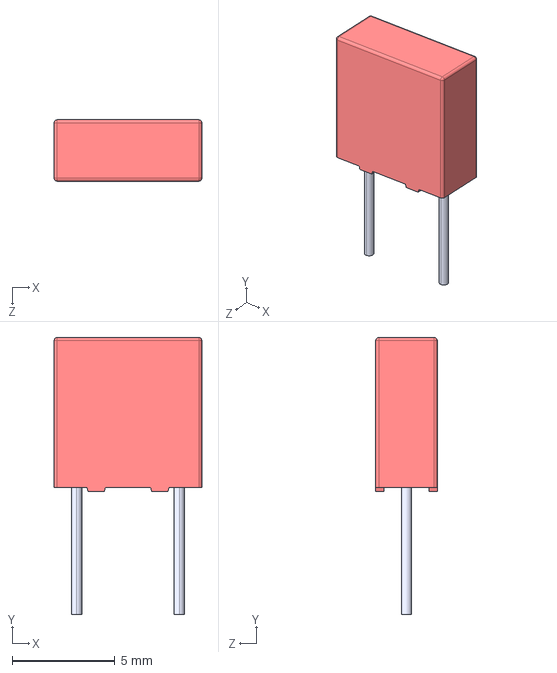
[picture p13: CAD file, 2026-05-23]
Hardware/Revision_C/3d-Files/MKP2D021001B00KSSD.STEP
7.20 x 13.5 x 3.00 mm

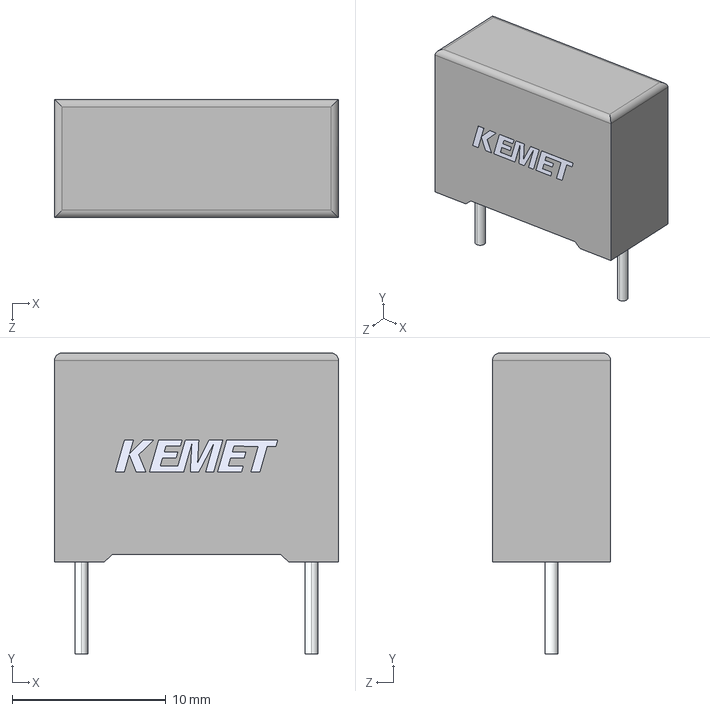
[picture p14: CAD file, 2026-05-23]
Hardware/Revision_C/3d-Files/R75PI3100AA30J.step
18.5 x 19.6 x 7.71 mm

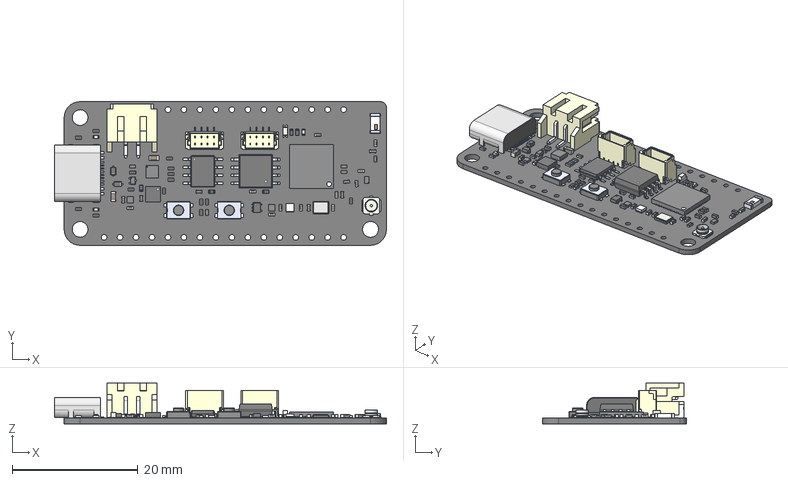
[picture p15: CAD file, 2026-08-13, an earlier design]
Hardware/Revision_B/3d-Files/FeatherS3D.STEP
52.8 x 22.9 x 6.50 mm
R_0402_1005Metric x 20
2450AT18B100E--3DModel-STEP-269445
D_SOD-523 x 2
LED_0402_1005Metric x 3
C_0402_1005Metric x 20
SOT-723
KMR221GLFS--3DModel-STEP-56544 v3 x 2
HIRO-USB-C Fixed Position
LED_0805_2012Metric_Castellated
ESP32_S2--3DModel-STEP-1
L_0402_1005Metric x 3
SSOP-8_3.9x5.05mm_P1.27mm
C_0603_1608Metric x 2
U.FL_Hirose_U.FL-R-SMT-1_Vertical
SOIC-8_5.3x5.3mm_P1.27mm
MAX17048G-T10
BGS12WN6E6327XTSA1
TDFN-6-1EP_2.5x2.5mm_P0.65mm_EP1.3x2mm
NCP170AMX170TCG x 2
JST_SH_4pin_Vert x 2
JST_PH_2pion_Horiz
Crystal_SMD_3225-4Pin_3.2x2.5mm_HandSoldering
SOT-553
FeatherS3D_P1_PCB

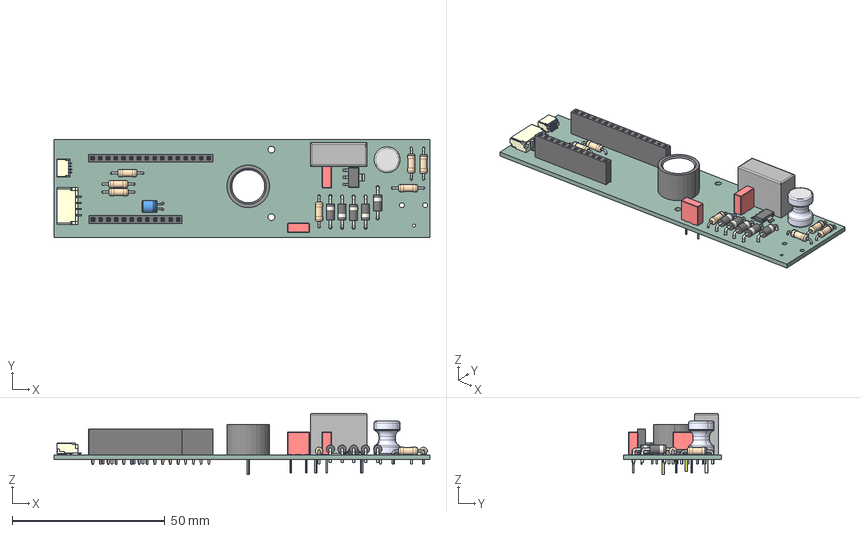
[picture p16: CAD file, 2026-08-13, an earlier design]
Hardware/Revision_B/Deliverables/Supporting Files/geiger.step
123.1 x 31.9 x 20.1 mm
bobina_100uH
R_Axial_DIN0207_L63mm_D25mm_P1016mm_Horizontal x 7
PinSocket_1x12_P2.54mm_Vertical
PinSocket_1x16_P2.54mm_Vertical
MKP2C021001B00JA00 x 2
D_DO-41_SOD81_P10.16mm_Horizontal x 5
SOT-223
SM04B-SRSS-TB(LF)(SN) x 2
CUI_DEVICES_CPT-1495CI-300
El Cap L/A
CFR_RB2_18X13.5X7.5_L18.5H13.6T7.7S15LL6F0.85
geiger_PCB

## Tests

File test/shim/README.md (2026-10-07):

# Host-test shim headers

Minimal stand-ins for the ESP-IDF / FreeRTOS headers that firmware `.c` files
in `main/` include, so those files can be compiled into the host test binary
(`test/test_main.c`) unchanged. Added in V2.8.8 (codebase review 2.1 B).

Only what the compiled units actually use is declared. A shim provides
declarations, types and inert behaviour — never firmware logic — so a test
exercises the real `main/*.c` code, not a copy of it.

| Header | Provides | Used by |
|---|---|---|
| `freertos/FreeRTOS.h` | `TickType_t`, `BaseType_t`, `pdTRUE`/`pdFALSE`, `portMAX_DELAY` | `history.c` |
| `freertos/semphr.h` | `SemaphoreHandle_t`, mutex create/take/give (single-threaded no-ops; create can be made to fail) | `history.c` |
| `esp_log.h` | `ESP_LOGx` macros that format-check their arguments but print nothing | `history.c` |
| `esp_err.h` | `esp_err_t`, common `ESP_*` codes, `esp_err_to_name()` | `config.h`, `transmission.h` (planned) |
| `driver/i2c_master.h` | opaque I2C bus / device handle types | `pm_sensor.h` via `transmission.h` (planned) |

Include order matters: the build passes `-I test/shim -I main`. A quoted
`#include "x.h"` is resolved from the including file's own directory first, so
for a firmware file in `main/` its `main/` headers (e.g. `tube.h`, `hal.h`) are
always the real ones. `test/test_main.c` lives in `test/`, though, so for it
`test/shim` is searched BEFORE `main/`: **never give a shim the file name of a
header in `main/`**, or the tests would silently compile against the stand-in.
`hal.h` needs a board, so the host build defines `-DBOARD_HELTEC_V2=1`; it only
selects pin and capability macros, none of which the tested code depends on.

Known limits:
- `esp_err.h` and `driver/i2c_master.h` are not used yet; they are there for
  the planned payload / config tests. `esp_err_to_name()` returns only
  `"ESP_OK"` or `"ESP_ERR"`, so no test should compare its text.
- `esp_log.h` uses the GNU `##__VA_ARGS__` form, as ESP-IDF's own header and
  zero-argument calls such as `ESP_LOGE(TAG, "text")` in firmware code need.
  The host build therefore cannot add `-Wpedantic`.

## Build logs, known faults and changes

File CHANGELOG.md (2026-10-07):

# MultiGeiger-V2 — Changelog

Per-release WHAT/WHY notes. Extracted from `main/version.h` in **V2.4.1** so the release archaeology doesn't bloat every build's parse cycle.

- **V2.4.1 down to V2.3.23**: full notes preserved from the pre-V2.4.1 `version.h` header.
- **V2.3.22 down to V2.1.11**: one-line headlines only — full bodies live in the GitHub release for each tag at <https://github.com/MMBytes/MultiGeiger-V2/releases>.

For build / flash / release workflow see `README.md` and the `_build.cmd` / `_merge.cmd` / `_flash.cmd` helpers at the repo root.

---

## V2.8.8 — Host tests: history maths, HTML escaping, sanitizer and 32-bit runs

A test-only release: the firmware behaves exactly as V2.8.7. The host tests
(the `test/` suite CI runs before every build and release) now cover the CPM
history code and the HTML-escaping contract, and run four ways instead of two.

1. **CPM history (`history.c`) is now tested** — the code behind the
   `/status` graph, the 5- and 15-minute averages sent to GMCMap and
   ThingSpeak, and the live CPM on the display. This code has changed in five
   earlier releases, two of them bug fixes. The tests compile the unchanged
   firmware file and check: the first sample after boot, the 60 s sampling,
   the 5/15-minute averages, the hourly roll-up, the ring of the last 60
   minutes, a falling filtered total reading as 0 instead of 65534, a
   count-source switch, the 49.7-day millisecond-counter wrap, and the live
   display window (10 s minimum, 60 s span at the fastest sampling rate, long
   main-task pauses, restarts, and a very high count rate that needs 64-bit
   arithmetic).
2. **HTML escaping contract.** Every escape buffer that holds a text setting
   is sized with `ESC_WORST()`. New tests check that a value made only of
   quotes fits that size exactly, that one byte less drops only the last
   character, and, over 20,000 random inputs, that escaping never writes past
   the buffer, always terminates the string, never leaves a raw `<`, `>`, `"`
   or half an `&…;` entity, and never cuts a value short when the buffer is
   sized correctly. `ESC_WORST()` moves from `http_server.c` to `util.h`, next
   to `html_esc()`, unchanged. An audit found every one of the 33 text
   settings escaped before it reaches a web page.
3. **Two more CI runs of the same tests:** with AddressSanitizer and
   UndefinedBehaviorSanitizer (out-of-bounds access, invalid shifts, signed
   overflow, converting a NaN or out-of-range number to an integer, and
   similar bugs that valgrind cannot see), and built as 32-bit
   code like the ESP32 chips themselves (the normal CI computer is 64-bit,
   where `long` is twice as wide). Each was checked to fail on a bug planted
   for it.
4. **Clearer test failures and a test filter.** A failing check now names
   the source line and the expression that failed. `_test.cmd history_` (or
   `test/run history_`) runs only the tests whose name contains the given
   text, and a filter that matches no test fails instead of passing.
5. The 32-bit run immediately exposed three tests whose expected value
   wrapped where `long` is 32 bits; they now compare correctly.

---

## V2.8.7 — Boot detail lines also logged without syslog

The `boot: …` lines (Firmware, Build, SoC, Display, Flash, PSRAM, Sensors,
TLS) were logged only when the node started its syslog connection, so a node
with syslog switched off never logged them at all, not even into the log
shown on its `/log` page. They are now logged on every node, whether or not
it sends syslog.

1. **Syslog on:** unchanged. The lines are logged when the syslog connection
   starts, ahead of `syslog: started`, and sent to the server.
2. **Syslog off:** the lines are logged once, when the node first gets an
   address on the network.
3. **No network, or a syslog host name that cannot be resolved:** the lines
   are logged 3 minutes after boot, so they are in `/log` and on the serial
   console even for a node in setup mode. If syslog starts later, the lines
   are sent to the server at that point as well, so `/log` then holds them
   twice. (A syslog server that is merely down counts as syslog on: the
   lines are logged when the connection starts, as in item 1.)
4. Without syslog, the lines are written back to back; the 10 ms gap between
   them is only needed while they are being sent over the network.

---

## V2.8.6 — HV charge pulses end on time during flash writes; more boot detail in syslog

The HV charge pulse is switched off by a timer interrupt 1.5 ms after it
starts. Until now that interrupt could not run while the flash was being
erased or written (OTA updates, settings saves), so a pulse that began just
before an erase stayed on for the whole erase — tens to hundreds of
milliseconds. It now runs through flash operations on every board, and two
new log lines measure the HV pulses across an OTA update to confirm it.
The boot lines sent to syslog also gain the build, chip, flash, PSRAM and
sensor details that were previously visible only on the serial console.
Counting, dose calculation and uploads are unchanged.

1. **The HV timer interrupt keeps running during flash writes**
   (`CONFIG_GPTIMER_ISR_CACHE_SAFE`, all boards). Its code and data were
   already in internal RAM; the one remaining flash-resident call, the FET
   pin write, is now an inline register write. No measurable RAM cost.
   Flash "auto-suspend", the other way to keep interrupts running during
   an erase, was not used: it is not supported by the flash chips on the
   FeatherS3-D and Heltec V4 boards, and enabling it there stops the node
   from booting.
2. **`HVON-OTA: window=pre long=N max_us=M`** when an authenticated upload
   starts: the HV pulses since the last cycle, so that the next line covers
   the upload and nothing else.
3. **`HVON-OTA: window=ota ok=K long=N max_us=M dur_ms=D`** when the upload
   ends, whether it succeeded or failed: the HV pulses during receive,
   flash erase and write, verify and commit, and how long that took.
   `ok=1` means the new firmware was committed, `ok=0` that the upload
   failed or was refused. With item 1 in place, `long=0` is expected.
   V2.8.5's per-cycle `HVON:` line could not show this, because the node
   restarts before the next cycle is logged.
4. Both lines use their own `HVON-OTA:` prefix, so scripts that read one
   `HVON:` line per cycle are not affected. After a failed update, the next
   cycle's `HVON:` line covers only the time since the update ended. Nodes
   with the tube disabled write neither line.
5. **More hardware and build detail in the boot lines sent to syslog.**
   Most of this was until now shown only on the serial console or kept in
   the device's RAM log. The existing `boot: Firmware …` line is unchanged;
   each addition is its own line:
   - `Build:` the first 9 digits of the firmware's ELF SHA-256, the same
     prefix a crash report prints (it separates two builds with the same
     version number and matches a coredump to its ELF), the build time,
     the bootloader's IDF version (OTA updates never replace the
     bootloader), and whether secure boot and flash encryption are on.
   - `SoC:` chip package version, radio features, CPU and crystal clock,
     and what is inside the chip package: flash/PSRAM flags on the
     ESP32, the flash and PSRAM capacity codes on the ESP32-S3 and C5.
   - `Flash:` the exact flash part (JEDEC ID and IDF driver), physical and
     configured size (`?` if the size cannot be decoded), and the flash
     mode and clock set in the build configuration.
   - `PSRAM:` size, mode and clock, or `none`.
   - `Sensors:` what the boot probe found: tube on/off and the
     environment, PM, noise, VOC, light, GNSS and fuel-gauge sensors, each
     by name or `none`. A fitted fuel gauge with "Battery attached" off
     shows as `MAX17048 (no battery set)`.
   The lines are sent about 10 ms apart, as the settings summary already
   is, so a slow network cannot drop them.

---

## V2.8.5 — Safer MQTT TLS, OTA and settings handling; HV on-time telemetry

A maintenance release from a whole-codebase review. It fixes a set of small
but real bugs and race windows, refuses one insecure MQTT setting that used to
degrade silently, and adds a per-cycle log line that measures the HV
charge-pulse on-time. Counting, dose calculation and upload contents are
unchanged except where an item below says otherwise.

1. **MQTT TLS Mode B (custom CA) with no CA certificate no longer connects.**
   This combination used to fall back, without saying so, to a TLS connection
   that does not verify the broker — handing the MQTT username and password
   to whoever answers on the broker's address. The node now logs an error and
   does not start MQTT; the status page shows "not started — TLS Mode B is
   selected but no CA certificate is configured — not connecting"; and /config refuses to save
   the combination (previous TLS settings kept, field listed as not saved).
   Mode D remains the explicit way to connect without verification.
   **If a node uses Mode B, check that its CA field is filled before
   updating** — a node that relied on the fallback stops publishing until a
   CA is pasted or Mode D is chosen.
2. **A failed OTA now says what it left switched off.** Before writing, the
   upload stops MQTT, the FTP log upload and, where present, the pulse tick
   and the PCNT width filter, and none of them restart if the upload fails. The error text now
   says so: they stay off until a successful retry or a reboot. The "keep
   services suspended" flag is also set before MQTT is stopped, so the main
   loop can no longer restart MQTT (and its ~50 KB TLS session) part-way
   through the upload — the out-of-memory case this teardown exists to
   prevent on 4 MB Heltec boards.
3. **Numeric /config fields reject text.** A value that is not entirely a
   number ("abc", "12abc", empty) used to be stored as its leading number or
   as 0 — an invalid tube type became "Unknown" and zeroed the uploaded dose,
   an invalid OLED brightness switched the panel off. Such values are now
   reported as not saved, previous value kept, like out-of-range ones.
4. **GMCMap IDs and ThingSpeak write keys are URL-encoded** (radiation and PM
   channels), as Radmon credentials have been since V2.5.20. A value
   containing `&`, `+`, `%` or a space no longer breaks the request.
   Alphanumeric keys and IDs are sent exactly as before.
5. **Status and config pages.** The MQTT broker name and topic prefix are
   HTML-escaped on the status page (a `<` or `"` in either broke the page).
   /config is sent with `Cache-Control: no-store`, so browsers do not cache
   the page that carries the stored passwords.
6. **Sensor timing.** The BME280 soft-reset wait and the DNMS command-to-read
   gaps were meant to be 2–5 ms but were 0 ms at the firmware's 100 Hz
   scheduler tick. They are now precise busy-waits, the same fix V2.3.31
   applied to the other drivers. This removes one cause of intermittent
   BME280 calibration and DNMS read failures.
7. **PM number-concentration display.** Values from 9950 to 9999 showed as
   "10.0k" — five characters in a four-character cell, pushing the row off
   the OLED. They now show "10k".
8. **Scheduler and race fixes**, with no visible change in normal operation:
   the upload-cycle timer is safe across the 32-bit tick-counter wrap (after
   ~497 days of uptime it would have fired back to back for one interval);
   the upload worker marks itself busy before taking a job off its queue,
   closing a window in which the daily crypto refresh or OTA preparation
   could see it as idle; neither crypto reset runs during an OTA upload; the
   PCNT width filter is marked inactive before it is torn down for an OTA;
   and syslog and the SD logger no longer share one timestamp buffer.
9. **New log line `HVON: long=N max_us=M`**, after each `DIAG` line when the
   tube is enabled. It counts the HV charge pulses in the cycle whose FET
   on-time exceeded 2 ms and gives the longest on-time. Nominal is about
   1.5 ms. The turn-off is a timer interrupt that cannot run while flash is
   being erased, so longer pulses are expected around OTA updates and
   settings saves. Measurement only — HV control is unchanged — to decide
   whether HV should be paused during an OTA. The `DIAG` line itself is
   unchanged, so existing log parsers keep working.
10. Code comments corrected: the task watchdog currently watches no task (an
    earlier comment said otherwise), and the MQTT publish call can block for
    up to the network timeout.

---

## V2.8.4 — Live display CPM runs only while it can be shown

V2.8.3's once-a-second display code ran on every node using the radiation
layout — including nodes with the display switched off and boards with no
panel at all, where it sampled the tube counter every second for a value
nobody could see. It now does nothing unless a display was found at boot,
the radiation layout is active and the display is switched on. Nothing
changes while the display is on, and uploaded values are unaffected as
before.

1. **No panel, the rotation layout, or a SerLCD** (which has no radiation
   screen even when that layout is forced): the 1 Hz display code does not
   run at all.
2. **Display switched off, or the tube disabled:** no counter sampling. The
   display code still runs once a second only to keep the panel blank (or,
   with the tube disabled, to draw the zero placeholder as before).
3. **Switching the display back on** from the web page starts a fresh 60 s
   window: on the OLED, live values appear about 10 s later, rather than
   first showing an average over the whole time the display was off. (The
   TFT's backlight still only turns on after a reboot, as before.)
4. The live window's sample ring (~590 bytes of RAM) is still reserved on
   every board; only the work is gated.

---

## V2.8.3 — Radiation display updates every second

The single-page radiation display (the small OLED on the Heltec boards, or a
TFT with the layout forced to radiation) used to be redrawn only once per
upload cycle — every 150 s by default the CPM and dose jumped to a new value and
then sat still. It now redraws about once a second with a live CPM.
**Uploaded values do not change**: every upload target, MQTT, the status page
and the rolling 5/15-minute averages are computed exactly as before.

1. **The displayed CPM is a 60-second sliding window, updated every second.**
   It is computed from the tube's since-boot pulse total — the same counter
   the 5/15-minute averages already sample — with its own sample ring, so it
   cannot move the per-cycle upload count or the averages. It is therefore
   *not* the uploaded number: the upload covers the whole cycle (default
   150 s), the display the last 60 s, so the two normally differ by a few
   CPM. nSv/h on the display is derived from the same 60 s value. The
   rotation layouts (Radiation page on the big panels) are unchanged.
2. **Boot:** the running screen appears about 10 s after boot, once its
   window holds 10 s of data (the splash stays for at least 7 s) — instead
   of after the first upload cycle. The HV indicator shows `H` from the
   start instead of `.` until the first cycle.
3. **Pauses, by design.** The redraw runs on the main task, so the display
   can hold its last frame for a few seconds while that task is busy (sensor
   reads at the start of each cycle, the daily FTPS log upload). The uploads
   themselves run on their own task and do not pause it. After a long pause
   the CPM is taken over the whole gap, so it stays correct.
4. **No flicker.** The OLED is cleared once and its fixed-width fields are
   then overwritten in place; clearing it every second blinked visibly.
5. **The status line (W/s/m/r/H) is now drawn only by the display redraw.**
   Upload state changes used to draw it straight from the upload task, which
   could interleave with the main task's drawing and garble glyphs once the
   display redraws every second. Changes now appear within about a second
   (up to ~10 s while the display holds its last frame, see items 2 and 7).
   The OLED brightness command is likewise sent as one I²C transaction, so a
   brightness change saved from the web page cannot be split by a redraw.
6. **A failing display bus cannot stall the node.** If an OLED write fails,
   the rest of that frame is skipped and redraws pause for about 30 s
   (one `OLED write failed` warning, one `OLED writes recovered` line) —
   otherwise a stuck bus would block the main task for ~28 s per frame,
   every second.
7. Only with the PCNT width filter *and* HV blanking both enabled: once per
   cycle the phantom subtraction lowers the count total in one step. The
   display notices each subtraction, restarts its window and holds the
   previous value for ~10 s — otherwise it would read low (or 0 on a slow
   node) for up to a minute every cycle. Stock configurations (both off)
   are unaffected.

---

## V2.8.2 — TCP keepalive on web sessions; two status/log corrections

Follow-ups from a memory review of the HTTPS change on the six deployed
nodes (V2.7.7 baseline vs V2.8.1, 39 h) and a stress test on two 2 MB-PSRAM
boards. The review's headline first, because it is what the release is
about: **HTTPS costs ~13.5 KB of internal RAM standing and 28.5 KB per open
session (mbedTLS buffers, in PSRAM), and every session gives it all back on
close** — dozens of sessions over 39 h left two 8 MB nodes exactly on their
baseline. Under stress (60 back-to-back handshakes, 5/10/20-way bursts, six
silent half-open connections, two concurrent 950 KB `/log` downloads over
TLS) neither test node rebooted or leaked a byte; the limit is the single
web task's ~1.1 s of software ECDSA per handshake, not memory.

**In short:**

1. **Sessions whose peer vanished are now closed by TCP keepalive.** Two
   nodes were each holding two idle HTTPS sessions for 26 hours — a browser
   on a VPN that dropped without a FIN. The node only learns a peer is gone
   when it tries to send, and an idle session never sends, so such a ghost
   lived until the LRU purge happened to need its slot (bounded at
   `max_open_sockets` × 28.5 KB ≈ 143 KB, so never dangerous — just untidy
   and it consumed the browser's burst capacity). Every accepted socket now
   carries `SO_KEEPALIVE` (idle 120 s, interval 15 s, 4 probes): an
   unreachable peer is reaped after 180 s; a live idle browser answers the
   probes in its kernel and is never touched. The 180 s deliberately sits
   above the OTA's 150 s weak-WiFi budget — a stalled upload is a silent
   socket too. Both the :443 and the :80 instance get it.
2. **The status page now reports the PSRAM the chip actually found.** The
   Memory line was a literal "8 MB PSRAM" on every PSRAM board and so lied on
   the six 2 MB boards (only FeatherS3-D, XIAO S3 and SparkFun C5 truly have
   8 MB).
3. **The `TLS handshake on fd N did not complete` marker names the second
   code you will meet.** A client that connects to :443 and never speaks
   (a port scan, or the stress test's half-open connections) logs
   `esp_tls_create_server_session failed, 0xffff7ff7` — that is −0x8009,
   `ESP_ERR_ESP_TLS_SERVER_HANDSHAKE_TIMEOUT`, the node's own 9 s handshake
   budget doing its job — and the marker beside it still blamed a browser.
   It now says which is which. The callback itself still cannot tell them
   apart (unchanged); only the text is corrected.
4. **Known and left as is:** a `/log` download over TLS (~27 s for a 1 MB
   ring) stalls every other HTTPS request until it finishes — the single
   web task processes handlers serially, by design (see the V2.4.22
   static-buffer note in `http_server_start`). Read `/log` from :80 in
   scripts, as before.
5. No change to counting, uploads or the web API. Binaries grow by ~2 KB on
   the PSRAM boards (the keepalive setsockopt path in esp_http_server is now
   linked, plus the PSRAM-size call) and ~300 B on the Heltec V2 variants.

---

## V2.8.1 — the TLS state reaches syslog

**In short:**

1. **A third `boot:` banner line, `TLS: …`, now reaches the syslog server.**
   In V2.8.0 none of the certificate work was visible server-side: the load
   or generation and both "listening" lines are logged before the syslog
   client exists (it needs a LAN address, which arrives after the AP window),
   and the reconcile verdict is logged in the same main-loop tick as the
   syslog start, a few lines before the socket opens. On the node itself the
   first HTTPS boot takes its log ring with it when it reboots to load the
   re-issued certificate. The new line summarises the whole boot from saved
   state once the socket is live, for example:
   `boot: TLS: HTTPS :443 + :80 plain/redirect — loaded from NVS; SHA-256
   AA:BB:CC:DD:EE:FF:00:11; names the current address, 798 days left`
   or, on a first enable, `… generated in N ms (valid 20260913..20281121, AP
   addr only); SHA-256 …; re-issued in N ms (…, STA addr); new SHA-256 …
   after reboot`. Nodes with HTTPS off report `HTTP :80 (HTTPS off in
   config) — nothing provisioned`; boards without HTTPS report `HTTP :80 —
   n/a`. This also captures the key-generation time V2.8.0 could not.
2. **The `esp-tls-mbedtls: read error :-0x0050` lines now come with an
   explanation.** On every HTTPS node, each browser page load logged two to
   five of them at ERROR level. They are not a fault. A browser opens several
   connections to a new host at once; each TLS handshake costs about a second
   of software ECDSA on the node's single web-server task (the ESP32-S3 has no
   elliptic-curve accelerator), so the spare connections wait their turn,
   complete the handshake, and are then closed by the browser before it sends
   a request. The first read on each of those finds the peer gone. Nothing
   is lost and the page always loads, and it happens whether or not the
   certificate is trusted — it is the browser's speculative pre-connection,
   not a certificate retry. The esp-tls line stays at ERROR — the same tag
   reports genuine TLS failures — but every such session now also logs
   `TLS session on fd N closed before any request (a browser's abandoned
   parallel connection — harmless)` at INFO. A `read error` WITHOUT that
   companion line is a real mid-request reset worth looking at. A handshake
   that never completes (about once per cold page load the browser hangs up
   mid-handshake, `mbedtls_ssl_handshake returned -0x7280`) logs `TLS
   handshake on fd N did not complete — see the esp-tls line above`; that
   line is a marker, not a verdict — the mbedTLS code next to it says
   whether it was a browser (`-0x7280`), a port scan or a real fault.
3. **Tried and rejected: mbedTLS's fixed-point ECC optimisation.** Measured
   on the bench node with a single-connection client, TLS setup took the same
   1.1 s with and without `CONFIG_MBEDTLS_ECP_FIXED_POINT_OPTIM`, so the
   23 KB of flash it costs buys nothing here; left off.
4. **Status page:** the certificate line moved from the Device card to the
   bottom of the Network card, next to the address it certifies, and the
   fingerprint now wraps inside the card instead of running past its edge.
5. No change to counting, uploads or the web API. Binaries grow by a few
   hundred bytes.

---

## V2.8.0 — HTTPS for the node web UI (opt-in, PSRAM boards)

**In short:**

1. **The web UI can now be served over TLS on port 443** on every PSRAM board
   (all boards except the two Heltec V2 variants). It is **off by default**:
   nothing changes after this update until you tick *Serve the web UI over
   HTTPS* on `/config` and use *Save and restart*. Nodes that never leave
   their own access point, or that run LoRaWAN only, are best left off.
2. **What enabling does.** On the next boot the node generates its own ECDSA
   P-256 key and a self-signed CA certificate (only after the radio is up, so
   the key has real entropy), starts serving on 443, and — once it has its
   LAN address and the time — re-issues the certificate to include that
   address and **reboots once more**. After that the certificate is kept in
   NVS and survives reboots and OTAs; it is renewed automatically within its
   last 30 days (800-day life) — on a node that has a valid clock; one that
   never reaches NTP keeps a fixed window ending 2028-03-11 and will show an
   expired-certificate warning after that. Give the node a DHCP reservation:
   an address change means one more re-issue and reboot.
3. **The browser warns once per device.** Compare the SHA-256 fingerprint on
   `/` with the one in the warning, then either accept it or import
   `/cert.pem` into your OS or browser trust store to end the warning. ⚠️ A
   certificate imported into an OS **Root** store is a certificate
   authority for that browser: whoever holds this device's private key
   (plaintext in NVS, present in `/coredump.elf`) could then sign
   certificates for any site that browser trusts. Prefer per-site or
   per-browser trust where your platform offers it, and never post a
   coredump from an HTTPS-enabled node to a public forum.
4. **Port 80 stays up for machines.** `/log`, `/api/env` and `/cert.pem` are
   still served plain, so scripts and peer nodes keep working unchanged.
   Every other `http://<device>/…` request, any method, answers `301` to
   the same path on `https://`.
5. **Why.** `/config`, `/update` and the other protected routes use HTTP Basic
   auth, which sends `admin:<AP password>` base64-encoded in the clear on every
   request; the AP password is also the WPA2 key of the provisioning AP. After
   your first HTTPS login, **change the AP password** if the node was ever
   used over plain HTTP from that browser: browsers cache Basic credentials and
   send them to port 80 before they see the redirect.
6. **OTA over TLS.** `/update` works over HTTPS and rides through WiFi gaps of
   up to 15 × 10 s per chunk. Scripted uploads with curl must add `-H "Expect:"`
   (the server does not implement `100 Continue`; without it curl stalls).
7. **Also in this release:** two concurrent `/log` readers can no longer
   corrupt each other's output (the second gets `503` with `Retry-After: 2`,
   also protects the FTPS uploader); `/` gains an `httpd stack headroom`
   line on every board; HEAD requests to the redirector get no body; the CSRF
   check on protected POSTs now binds the Origin scheme as well as the host
   (scripts on HTTPS nodes send `-H "Origin: https://<device>"`).
8. **Build:** the HTTPS server, the mbedTLS X.509 writer and
   `CONFIG_LWIP_MAX_SOCKETS=20` are enabled in `sdkconfig.defaults.psram`
   only. New `HAL_HAS_HTTPS` gate in `hal.h`; new config field `https_enable`
   (NVS `https_en`); new modules `tls_cert.c/.h` and header-only
   `tls_logic.h` (host-tested). Heltec V2 builds change only by shared code:
   the `/log` snapshot guard, the new config field, the `httpd stack headroom`
   line, and the boot-order move (the web server, FTPS and MQTT bring-up now
   run after `esp_wifi_start()` on every board).

| Board | V2.8.0 `geiger_v2.bin` | App slot free | vs V2.7.7 |
|---|---|---|---|
| heltec_v2 | 1 322 512 B | 37 % | +800 B |
| heltec_v2_4mb | 1 322 528 B | 33 % | +800 B |
| feathers3_d | 1 378 688 B | 34 % | +23 664 B |
| adafruit_qtpy_esp32_pico | 1 367 536 B | 35 % | +23 456 B |
| seeed_xiao_esp32s3 | 1 360 448 B | 35 % | +23 696 B |
| heltec_wifi_lora32_v4_r2 | 1 449 600 B | 31 % | +23 472 B |
| sparkfun_thing_plus_esp32s3 | 1 451 472 B | 26 % | +23 552 B |
| sparkfun_thing_plus_esp32c5 | 1 656 208 B | 21 % | +27 008 B |
| adafruit_esp32s3_tft_feather | 1 412 512 B | 28 % | +23 584 B |
| adafruit_esp32_feather_v2 | 1 432 960 B | 32 % | +24 528 B |
| adafruit_esp32s3_feather_4mb_2mbpsram | 1 383 728 B | 30 % | +23 696 B |

---

## V2.7.7 — toolchain: ESP-IDF v6.0.3

**In short:**

1. **ESP-IDF v6.0.3** (from v6.0.2). No firmware code changes. Rebuilt on
   the new toolchain, which fixes a Content-Length truncation in the
   on-device HTTP server (a header above 32 bits was cast down, which allowed
   request smuggling on a keep-alive connection; it is now rejected), several
   lwIP fixes (DHCP client and server hardening, DNS multi-record overflow,
   TCP out-of-sequence handling), WiFi fixes for the PSRAM boards, and an
   SD-card re-initialisation fix.
2. **Three defaults the new IDF moved are now pinned** so every board builds
   the same way locally and in CI: the HTTP server's esp_events are off
   (nothing in the firmware listens for them, and each one cost a malloc per
   request); the interrupt watchdog is 800 ms on PSRAM boards (the new IDF
   default for S3/C5, matching the ESP32 boards); cross-signed CA-bundle
   verification stays **off on the Heltec V2** to protect its heap, and is on
   elsewhere as the new default.
3. **Binary sizes** grew by roughly 2–7 KB per board; deployed behaviour is
   unchanged. `/` may report a slightly different "Min free heap" after the
   update: the IDF corrected how that minimum is calculated. It is not a
   regression.

| Board | V2.7.7 `geiger_v2.bin` | App slot free |
|---|---|---|
| heltec_v2 | 1 321 712 B | 37 % |
| heltec_v2_4mb | 1 321 728 B | 33 % |
| feathers3_d | 1 355 024 B | 35 % |
| adafruit_qtpy_esp32_pico | 1 344 080 B | 36 % |
| seeed_xiao_esp32s3 | 1 336 752 B | 36 % |
| heltec_wifi_lora32_v4_r2 | 1 426 128 B | 32 % |
| sparkfun_thing_plus_esp32s3 | 1 427 920 B | 27 % |
| sparkfun_thing_plus_esp32c5 | 1 629 200 B | 22 % |
| adafruit_esp32s3_tft_feather | 1 388 928 B | 29 % |
| adafruit_esp32_feather_v2 | 1 408 432 B | 33 % |
| adafruit_esp32s3_feather_4mb_2mbpsram | 1 360 032 B | 31 % |

---

## V2.7.6 — finer count-path telemetry, and an honest dead-time constant

**In short:**

1. **The `DIAG` log line has changed** — the edge-spacing histogram now has ten
   buckets instead of eight, splitting the old 190–500 µs bucket at 250 µs and
   380 µs. **Log parsers need updating.** Buckets above 500 µs are untouched.
2. **The dead-time constant is now documented honestly.** `GMC_DEAD_TIME_US`
   (190 µs) was described in the code as the Si22G's dead time. It is not — it
   is the SBM-20's figure, inherited from upstream. The Si22G count path
   actually recovers in 261–266 µs. **The value is unchanged and counting is
   unaffected.**
3. **The dead-time guard now states what it costs** — on `/config` and in its
   field documentation. At its default window and typical background rates,
   chance coincidence alone discards roughly 4.5 genuine counts per 1000, and
   the population it was built to remove could not be found on either board
   tested. **Default unchanged; it stays off.**
4. **Two compile-time assertions** so that a future change to the gate value or
   the bucket count fails the build rather than silently mislabelling telemetry.
5. **Nothing about counting, dose, uploads or your saved settings changes.**

The detail, for anyone who wants it:

A Geiger-Müller tube is blind for a short interval after each pulse while the
gas de-ionises, and the firmware has always rejected edges arriving inside
190 µs of the last count. That 190 µs was never measured for the tube this
project defaults to. It came from the SBM-20 — the original default tube — and
stayed put when the default changed to the Si22G.

Measuring it needed a radioactive source rather than patience: genuine close
pairs scale as the square of the count rate while spurious edges scale linearly,
so raising the rate roughly thirty-fold separates two populations that are
hopelessly mixed at background. Logging every edge's spacing individually across
a window straddling the gate then gives the tube's recovery directly, instead of
inferring it. Two boards on different carrier designs, sharing one tube, agreed
to within 5 µs: **detection efficiency is zero below about 253 µs, rises over a
ramp only 25–29 µs wide, and reaches full sensitivity by 280 µs.** A field node
fitted with a Schmitt buffer on its count input, running at ordinary background
levels on a third carrier, independently shows its closest pair in 23 hours at
280 µs — which is what that curve predicts.

So the gate sits about 25 % below the tube's real floor — and that is correct.
The gate is a lower bound, not an estimate: it has to clear electrical ringing
while staying under the recovery floor of *every* tube the firmware supports,
and 190 µs is close to the SBM-20's own figure. Raising it to suit one tube
would start discarding genuine counts from another at high rates. It also would
have bought almost nothing: the afterpulse population measured at 280–360 µs,
above any gate value that could sensibly be proposed.

That measurement is also what motivated the new buckets. Everything interesting
in this histogram happens between 190 µs and 500 µs — the recovery ramp, the
occasional spurious edge that clears the gate, and the afterpulse peak — and all
of it was previously collapsed into a single 310 µs-wide bin, which is why the
question needed a special-purpose firmware build to answer at all. Split at 250
and 380 µs, each band now holds one population — on a board whose count input is
otherwise quiet. Where a board produces many spurious narrow edges the bands
blur, because the histogram measures the gap to the previous *edge* rather than
to the previous *count*, so a genuine pulse arriving shortly after a spurious one
lands lower than it belongs. On a clean board, the question that previously
needed a custom firmware build is now answerable from ordinary logs.

Two smaller corrections ride along. The count input is falling-edge triggered,
not rising, as one comment claimed. And the sub-190 µs population is not
afterpulsing but the count node's own RC recovery ramp re-crossing the input
threshold — which the surrounding comment block already explained correctly a
few paragraphs further down, contradicting itself.

Finally, the dead-time guard. It is an optional, off-by-default filter meant to
collapse re-trigger bursts. It turns out to be far blunter than its description
suggested, for a structural reason: the guard tests the gap to the previous
*edge*, while the counting gate tests the gap to the previous *count*. On a
board with a large spurious-edge population those are very different questions,
and 96 % of what the guard removed was genuine counts whose only fault was
arriving shortly after a spurious edge. Its own target population, meanwhile,
was not detectable on any board tested. Nothing about its behaviour or default
changes here — but the numbers are now written where someone deciding whether to
switch it on will see them.

---

## V2.7.5 — the pulse tick goes quiet for a firmware update

**In short:**

1. **The pulse tick is now silenced when an OTA update starts**, alongside the
   MQTT / FTPS / PCNT teardown that already runs there. Ticking during an
   upload sounded wrong; now there is simply nothing to hear.
2. **The matching per-pulse LED / NeoPixel flash pauses with it** on boards
   that have a piezo fitted, because one piece of code drives both. On boards
   without a piezo the blink is unaffected and continues through the update.
3. Counting is unaffected — the tube keeps counting throughout, and your saved
   settings on `/config` are not changed.

The detail, for anyone who wants it:

The click is not generated in software. A counted pulse hands the LEDC hardware
a 5 kHz tone, and the *only* thing that takes it away again is a 1 ms timer
callback counting down four milliseconds. Writing the new firmware image blocks
that timer for far longer than 4 ms at a stretch, so a click caught by a flash
write holds its tone until the timer next gets a turn — a 4 ms tick stretched
into a ragged beep, repeatedly, for the length of the upload.

Rather than fix the timing, the update path now stops the tick and forces the
output low before the first byte is written, in the same place the firmware
already drains the upload worker, stops MQTT and pauses the FTPS schedule. It is
the same "quiesce the noisy subsystems before flashing" step, applied to the one
subsystem that is audible.

The same code drives the audible click and the per-pulse LED / NeoPixel flash,
so on a board with a piezo the blink stops too. If you are used to watching that
LED to tell the counter is alive, it will look idle for the length of the
update. It is not — the tube keeps counting the whole time. Note that this is
about the *indicator*, not the data: a successful update reboots the device, and
a reboot has always cleared the CPM history and the measurement cycle in
progress. That is unchanged here.

Like the rest of that teardown it is one-way: the device reboots into the new
firmware on success, and after a *failed* update the tick stays off until a
manual reboot — exactly as MQTT and the FTPS schedule already do. Your saved
`/config` settings are untouched either way; this stops the output for the rest
of the boot, it does not change what you configured.

No effect on boards with no piezo fitted — there the pulse LED is driven
elsewhere and keeps blinking — and no effect on the boot melody.

---

## V2.7.4 — the pulse tick stops manufacturing its own phantom counts

**In short:**

1. **Piezo/LED tick delayed by 1 ms** so it no longer disturbs the count input. Cuts phantom edges ~3×. Tick sounds the same; published counts unaffected.
2. **PCNT width-comb telemetry now logged on every tube-enabled node**, not only when a filter is switched on. New `PCNT:` line for log parsers.
3. **PCNT width filter now applies on Save** — no restart. The filter *width* still needs one.
4. **/config wording corrected** for the three count-path settings, with guidance on how to tell whether you need them. **No defaults changed.**

The detail, for anyone who wants it:

Every counted pulse schedules a piezo tick, and the 1 kHz audio timer dispatched
it 0–1000 µs later. For roughly a fifth of counts (190/1000) that put the tick's
switching transient inside the count node's own RC recovery, where the input sits
marginally below its switching point and a small disturbance is enough to
manufacture a spurious edge. Self-inflicted: each count scheduled its own
interference.

Holding the tick one whole audio period moves its start to 1000–2000 µs — clear
of the 190 µs dead-time gate by more than 5×, and about five time constants into
a 190.4 µs recovery, where the margin is no longer marginal.

Measured on the bench board over a **7.1 h** treated arm against an 8.5 h
control: the affected edge population fell from **0.844 % to 0.253 %** of raw
edges. Every hourly bin of the treated arm sits below every hourly bin of the
control — 8 treated bins against 9 control bins, no overlap — so it does not rest on the
two arms being drift-matched, which matters because this node's baseline is
known to wander by up to 2.8× on its own.

The count rate read **92.2 against 90.7 CPM**, a 1.7 % difference against the
**1.4 %** this run could resolve, so it is *not* dismissible as counting noise.
It is also not the fix. The two arms ran at different times of day; the treated
arm falls by a comparable ~2 % from morning to afternoon within itself; and the
change can only affect edges the 190 µs dead-time gate already rejects, which
bounds its possible effect on the published count at ~0.014 % — a hundred times
smaller than the difference observed. The residual is the ordinary diurnal
background cycle, aliased into a sequential comparison.

**No published measurement was ever wrong because of this.** On the default count
path the rejection holds *by construction*: the disturbance can only happen while
the input is recovering — 50–190 µs after a counted pulse on the boards
characterised so far — and that window sits entirely inside the 190 µs dead-time
gate the path already applies, and no configuration alters that path's gate.

On a node running the PCNT width filter instead, the protection is the configured
tooth rather than the gate, and *that* is empirical — the width filter is not a
second layer but a replacement, and the recovery-ramp phantom's width has been
measured sliding with temperature on one carrier. The soak settles it by
measurement rather than by argument: the escape-accounting identity held exactly
in **every cycle of both arms**, meaning no rejected edge was ever wide enough to
reach the width-filtered count, and no sub-microsecond edge was ever counted. See
`config_fields.def` for the width-versus-temperature caveat in full.

This is margin, not a correctness fix. The tick stays audible; after the one
held period, 99.85 % of ticks fire at the first opportunity at ambient rates, for
a mean added delay of 1.5 µs beyond the hold.

The decision logic lives in a new pure header, `main/speaker_logic.h`, following
`tube_logic.h` and `env_api.h`, with 9 host tests. One of them exists because a
prototype seeded its countdown inside the poll rather than at request time, so
the poll that counted down to zero re-seeded it and the tick never fired at all —
a bug invisible downstream, since a silent tick and a working defer produce the
same phantom count.

### The PCNT width comb now runs on every tube-enabled node

The comb — four hardware counters tapping the count pin in parallel with the ISR,
each with a different glitch-filter width — used to come up only if you enabled
the PCNT width filter or HV blanking. That made the only source of pulse-*width*
telemetry reachable solely by switching on a mitigation it exists to justify: a
node on clean defaults could not see its own phantom widths, so the diagnostic
that answers *"do I need the width filter?"* sat behind the width filter.

It is now gated on the tube alone. **This changes no published number.** The
count substitution is still strictly `pcnt_filter`-gated, as are the rolling
averages and the HV-blank subtraction. With the filters off, the only new output
is telemetry.

⚠️ **Log-parser note:** the per-cycle `PCNT:` line now appears on every
tube-enabled node, plus a `comb up` line at boot and a `comb stopped` line on the
OTA teardown path. Same class of change as V2.6.31, which first made that line
appear in blanking-only mode.

Cost was measured rather than assumed — a field board, fresh boot in both arms,
same binary: internal free heap 162227 B with the comb up against 162191 B with
it down. That is a 36-byte delta in the *wrong* direction, i.e. comfortably below
the ~520-byte cycle-to-cycle noise, and the largest free block was byte-identical
at 77824 B, so the comb does not fragment the contiguous-allocation pool that the
OTA teardown and the heap guard both care about.

**The PCNT width filter is now live-applied** — tick it and it takes effect on
Save, no restart. Its reboot-required marker is gone from /config, and so is the
V2.6.31 asymmetry where the same tick applied live on an HV-blanking node but
needed a restart elsewhere. The filter *width* still requires a restart, because
the glitch filter is latched when the counters are created. One corner case
remains: if the comb is down — after a failed OTA, or a boot-time counter
allocation failure — there is nothing to elect, so the tick is inert until the
next restart.

### /config now tells you how to decide, not just what the setting does

The three count-path settings carried explanations that had drifted from what is
now measured. All three defaults are unchanged and remain off.

| Setting | What the page now says |
|---|---|
| PCNT width filter | It **replaces** the always-on 190 µs dead-time gate on the published count rather than adding to it — the gate rejects an edge for arriving too soon, the filter for being too narrow. Watch `removed` on the `FILTER:` line to see whether it is removing anything the gate had not. |
| Dead-time guard | It **cannot reach anything under 190 µs**: its window floor is 200 µs, and edges inside the gate are already rejected before the guard sees them. If you are chasing the 50–190 µs band, this is not the control. |
| HV blanking | Scoped to the carrier revisions that actually have the coupling defect. **Check `hv_coincident` against `hv_pulses` before enabling** — once blanking is on, blanked edges skip the coincidence tally and that counter falls to the same chance-level floor a clean board reads, so an affected node becomes indistinguishable from a clean one. |

That last one is a trap worth stating plainly: enabling the treatment destroys
the diagnostic that would have justified it. Diagnose first.

Two corrections while in there. The archive-step argument for keeping HV blanking
opt-in was overstated — a compile-time default only applies when the NVS key is
missing, and every saved config writes all of them, so changing a default cannot
step an existing node's archive. The reasons that do hold are that it is a no-op
on boards without the defect and that the firmware cannot detect the carrier
revision. And the phantom share should be quoted as a fraction of raw edges,
which reproduces across measurement windows; the blanked-to-pulses ratio does
not, having read anywhere from 0.78 to 0.9998 on one node.

---

## V2.7.3 — `/api/env`, a machine-readable environment endpoint

New on every board: `GET /api/env` returns this node's temperature, humidity
and pressure as JSON, so another node can consume them as a control input.
No new config, no behaviour change elsewhere, and the endpoint is inert until
something asks for it.

```json
{"id":"esp32-1234567","t":21.19,"h":63.55,"p":101325.79,
 "t_ok":true,"h_ok":true,"p_ok":true,
 "age_ms":917,"ts":1787293045}
```

Units are °C, %RH and **Pascals** — the raw sensor units, the same ones the
MQTT `env_p` field and the LoRaWAN port-2 payload already carry. Only the HTML
status page converts to hPa, because that page is for people.

Unauthenticated, matching `/` and `/log`: it is a strict subset of what the
status page already serves publicly, and everything that changes state stays
behind basic auth.

The design is shaped entirely around one failure mode. The status page is
hand-rendered HTML, so a consumer that scraped it and lost its place would
return a plausible float rather than an error — silent wrongness, which is the
one intolerable outcome for a value something else acts on. Three properties
follow from that:

| Property | Why |
|---|---|
| `age_ms` is a **monotonic** difference, not a wall-clock one | Correct across NTP steps and before the clock is ever set |
| A never-sampled node reports `age_ms` as `4294967295` with every `*_ok` false | A freshly booted node's zero-initialised readings would otherwise look like a zero-age, perfectly valid sample |
| An invalid or non-finite reading is `null`, never `0.0` | A consumer that forgets the `*_ok` flag gets a parse error instead of a believable zero |

Both directions of the format live in one new header, `main/env_api.h` —
`env_api_format()` and `env_api_parse()` side by side — so a producer and a
consumer cannot drift apart. It is pure and header-only, following
`tube_logic.h` and `lorawan_codec.h`, which means the host test suite asserts
`parse(format(x)) == x` directly, along with truncated, malformed, reordered
and missing-key payloads. 26 new host tests.

`max_uri_handlers` rises 12 → 13.

Also in this release, groundwork with no firmware behaviour change:

- `safe_strcpy()` no longer calls `strncpy` — GCC 16 flags the
  `strncpy(dst, src, n-1)` idiom as `-Wstringop-truncation` under `-Werror`.
  The replacement is byte-for-byte equivalent including strncpy's tail
  zero-fill, and a new host test pins that property.
- `.gitattributes` now pins `*.cmd` to CRLF; `_test.cmd` was rewritten after
  checking out with LF endings, which cmd.exe misparses when invoked from
  PowerShell.
- The `/log` line in `http_server.h`'s endpoint list wrongly claimed basic
  auth — false since V2.3.33 — and now says so. The list also silently
  omitted four routes (`/favicon.ico`, `/coredump.elf`, `/coredump_erase`,
  `/lorawan_reset`); it is complete now.

## V2.7.2 — Sub-b1 reject profiler, compiled out by default

No behaviour change in a default build. This release lands the
instrumentation used to characterise the Rev B/C carrier's narrow-edge
reject population, with the facility switched off.

The population is now accounted for: a Schmitt buffer on the count node
took it from 8.34 % of edges to 0 in 4803, with the count rate unchanged
(0.35 σ). The profiler is kept rather than deleted because the question can
recur on a different carrier, and because its header comment holds the
derivation the measurements were read against.

**To use it**, build with `TUBE_REJLOG_ENABLE=1`. `tube.c` then keeps a
128-entry ring of rejected edges and `do_tx_cycle()` emits one `REJ:` line
per record:

| Field | Meaning |
|---|---|
| `edt` | µs to the previous edge — position on the count-node recovery ramp |
| `dt` | µs to the last **counted** pulse — `edt != dt` flags a multi-edge burst |
| `tph` | µs since the last recharge-tick ISR entry, 0..~100 µs — uniform acquits the 10 kHz timer, clustered convicts it |
| `hvg` | µs since the last HV FET turn-off |

The existing `DIAG` histogram bins every reject below 190 µs into one
bucket, and that bucket is where this population lives, so the number that
identifies the mechanism is the one the histogram destroys.

At `0` the ring, the drain, the per-record log lines and the timestamp store
in the 10 kHz `recharge_tick` ISR all compile out; the record type and the
accessor prototype stay outside the guard so callers need no conditional
code.

`tube.h` records the RC derivation: the count node's time constant is
(R5 + R2‖(R3+R4))·C4 = 190.4 µs, **not** R5·C4, and the switching point sits
near mid-rail rather than at the datasheet V_IL. Those two corrections
predict a recross at 148.5 µs against 148.08 µs measured, with no fitted
parameters. 190.4 µs and `GMC_DEAD_TIME_US = 190` are unrelated quantities
that happen to collide.

---

## V2.7.1 — BREAKING (`heltec_wifi_lora32_v4_r2` only): V1.10 mainboard as fabricated swaps the count and cap-full pins

The V1.10 mainboard was still in layout when V2.6.34 shipped. The board as
actually fabricated swaps module pads `14_` and `17_` against the layout
that release was written against, so on `heltec_wifi_lora32_v4_r2` the two
Geiger inputs trade pins:

| Signal | ≤ V2.6.33 (V1.9) | V2.6.34 | **V2.7.1 (V1.10 as built)** |
|---|---|---|---|
| `HV_CAP_FULL` | GPIO2 — J3 pin 13 | GPIO6 — J3 pin 17 | **GPIO3 — J3 pin 14** |
| `GMC_COUNT` | GPIO3 — J3 pin 14 | GPIO3 — J3 pin 14 | **GPIO6 — J3 pin 17** |

The swap came out of the PCB review, not out of a firmware preference: it
aligns the module's pad order with JP1's pin order, which widened the west
escape between the piezo-N aggressor and the cap-full input from 1.65 mm
to 3.72 mm and squared both of the layout's remaining 45° crossings to
90°. Those are the clearance rules the V1.10 change request exists to
enforce, so the copper won and the firmware follows.

JP1's pin roles are unchanged (pin 3 `GMZ_COUNT`, pin 4 `HV_CAP_FUL`), so
no tube or cable wiring changes with this.

**Which firmware belongs on which board, for this target:**

- **V1.9 mainboards: stay on ≤ V2.6.33**, as before.
- **V1.10 mainboards: require ≥ V2.7.1.**
- **V2.6.34 matches no physical board on this target at all** — the layout
  it encoded was never manufactured.

The eight socket-carrier boards are untouched: their V2.6.34 cutover to the
Rev B V2 / Rev C V2 carriers stands exactly as released, and `heltec_v2`
remains on its original wiring.

Firmware-side changes are limited to the two `#define`s in `main/hal.h`,
the pin commentary around them, the two cross-references elsewhere in the
same board branch that named the old pin owner, and this note. No logic
changed.

### Version numbering

The jump to V2.7.x is deliberate, and retroactive in spirit: V2.6.34 was
itself a breaking hardware cutover and should have been V2.7.0. Numbering
this one V2.6.35 would have buried a second no-runtime-detect pin change in
a patch-level bump. There is no V2.7.0 release — the number is left unused
as the marker for where the cutover actually began.

---

## V2.6.34 — BREAKING: pin maps cut over to the Rev B/C V2 carriers and the V1.10 mainboard; per-board ELF debug symbols

### Hardware pin cutover (breaking)

Nine of the eleven board targets change their Geiger wiring in place —
there are no new build targets and no runtime hardware detect. The
firmware version is the cutover line:

- **Original hardware (first-run carriers, V1.9 mainboards): stay on
  ≤ V2.6.33.** Flashing ≥ V2.6.34 there drives the HV FET PWM into the
  tube's pulse pickup and reads "counts" off the FET gate trace.
- **Updated hardware (Rev B V2 / Rev C V2 carriers, V1.10 mainboards):
  require ≥ V2.6.34.**

On the eight socket-carrier boards the update swaps the `GMZ_COUNT` and
`HV_FET_OUT` socket pads: the sensitive count input moves to the far-edge
pad (A5/SCK position), physically clear of the HV aggressor pair
(cap-full comparator + FET gate PWM) which now routes together on A0/A1
next to the HV corner. Why: the carrier-layout crosstalk from the HV
switching node into the adjacent count trace convicted in the
phantom-count investigation — fixed in copper, mirrored here as an exact
`PIN_GMC_COUNT_INPUT` ↔ `PIN_HV_FET_OUTPUT` value swap per board
(`hal.h` carries per-board ≤V2.6.33 wiring notes). `heltec_v2` (both
flash variants) is unchanged — the German V1.x mainboard hosting it was
not updated for that module.

`heltec_wifi_lora32_v4_r2` instead follows the V1.10 mainboard rework of
the V1.9 board: the cap-full comparator moves GPIO2 → GPIO6 (freeing
GPIO2 for its Heltec-side `FEM_EN` LoRa role — the old double-booking is
gone, the pad is left unwired), and the piezo becomes usable for the
first time on this module (`HAL_HAS_SPEAKER=1`, P leg rerouted
GPIO26 → GPIO4 away from the in-package PSRAM chip-select collision that
had forced the speaker off, N leg unchanged on GPIO5).

The GPIO2 ownership change also simplifies the `/config` LoRaWAN
section: the "Drive FEM enable (GPIO2)" checkbox is removed — the GC1109
front end is required for LoRa RX, so the firmware now always enables it
when LoRaWAN is on (a config option whose only non-default value is
"broken RX" is not a choice; the old stored setting is ignored, and
per-key NVS storage makes the removal migration-free). The 28 dBm
high-power option remains opt-in — a regulatory/EIRP decision — but
drops its hardware-rework warning, since the V1.10 board also removed
the DIP switch that used to share GPIO46. The boot config dump gains the
LoRaWAN group it had been missing since V2.6.23 (EUIs in clear, AppKey
masked, on the LoRaWAN board only).

One board-specific trap now documented in `hal.h`: on the SparkFun Thing
Plus ESP32-C5, the count input's new pin (IO6) also carries the board's
default-open "ST" power-status solder jumper. A closed ST jumper pins
the count node — symptom: CPM ≈ 0 with perfectly healthy HV telemetry.
ST must stay factory-open.

The OTA upload page (`/update`) now states the required hardware
revision for the nine affected boards next to the board name — with no
runtime detect, that human checkpoint is the only guard against flashing
a swapped-pin build onto original hardware.

### Per-board ELF debug symbols in release assets

Every GitHub release now attaches `elf_<board>.zip` (containing
`geiger_v2_<board>.elf`) alongside the five firmware images per board —
66 assets total for the 11-board matrix, up from 55.

Why: analysing a device coredump (`espcoredump` / `addr2line`) requires
the **exact** ELF that produced the running binary — the released `.bin`
images are no help for symbolication. Until now the only route for a
release build was rebuild-from-tag and byte-compare, which stays
byte-identical only while the same ESP-IDF toolchain version is still
installed locally; field nodes routinely crash on releases that are
months old, so "old tag, newer toolchain" is the normal case, not the
edge case. Shipping the ELF with each release removes that dependency
from this release forward (older tags still need the rebuild route).

CI-only part of this release — no firmware behaviour differs from it.
`_build-boards.yml` verifies the ELF exists and stages it zipped, with a
board-suffixed member name so extracting several boards' archives into
one directory cannot collide. `release.yml`'s independent asset-count
guard moves from 5 to 6 files per board and both release-upload paths
(fresh create and re-run `--clobber`) include the zips. The Pages web
flasher is untouched — it copies only the merged flash images.

---

## V2.6.33 — SHT45 heater: fire-and-forget + 3 s blackout, serve cached reading

Syslog review of the deployed field node showed 270 occurrences of
`sht45: measure_high write: ESP_ERR_INVALID_RESPONSE` across four humid
mornings (1–4 Aug 2026), each exactly one per
`SHT45 heater activated` log line (fires at RH > 80 %) — a perfect 1:1
correlation, and zero occurrences outside heater windows.

Root cause (`main/sht45.c`, `sht45_heat_periodic()`): the code sends
`CMD_HEATER_200MW = 0x39` — per SHT4x datasheet table 8 a **200 mW / 1 s**
pulse — but held the driver mutex for only 120 ms, sized for the 0.1 s
variant (0x32) that the adjacent comment wrongly described. The SHT45
NACKs every command for the full heater duration, so the mutex came free
~880 ms early and sgp41.c's 1 Hz RH/T compensation read landed
mid-pulse, failing with `ESP_ERR_INVALID_RESPONSE` once per activation.

Fix — fire-and-forget with a blackout deadline, rather than blocking for
the pulse (which would have stalled callers ~1 s and disturbed
sgp41_task's `vTaskDelayUntil` cadence; Sensirion's Gas Index Algorithm
is only validated for steady 1 s sampling):

- `sht45_heat_periodic()` sends the heater command and returns
  immediately, recording a **3 s blackout deadline**
  (`HEATER_BLACKOUT_MS`): 1 s deaf pulse + ~2 s die cool-down. The old
  post-pulse discard-read is dropped — the SHT4x has no result-readout
  obligation; the next measure command replaces the unread result.
- `sht45_read()` checks the deadline (wrap-safe) and, inside the window,
  serves the **cached pre-heat reading** (V2.6.19 telemetry cache) with
  ESP_OK instead of touching the bus. The cache is fresh in practice:
  the heater's humidity gate is normally the same cycle's successful
  SHT45 reading, taken ≤ ~1 s earlier. Rare interleavings can leave the
  cache cold (a concurrent read failing between gate and pulse, or a
  fallback chip's humidity satisfying the gate on fused boards when the
  SHT45 read failed) — those return ESP_ERR_INVALID_STATE and callers
  degrade exactly as on a pre-fix read failure, for ≤ 3 s. Otherwise
  callers see no failure, no blocking, and no warm-biased post-heat
  sample.

The 1 s pulse is deliberately kept (rather than switching to 0x32 to
match the old 120 ms wait) — it is the behaviour the fleet has actually
been running, and the stronger recondition suits the outdoor
PTFE-membrane variant (SHT45-AD1F-R2, Adafruit 6174) at sustained high
humidity. Stale "100 ms" claims corrected in `sht45.c`/`sht45.h`
comments. Heater duty cycle stays 0.17 % (1 s per 10 min), far below
the datasheet's 10 % limit. No behaviour change while the heater is
inactive (RH ≤ 80 %).

---

## V2.6.32 — TFT Feather first hardware: fix mirrored glyphs, radiation page, 4× Env text

First contact between the V2.6.11 ST7789 TFT backend and real glass —
the backend for the Adafruit ESP32-S3 TFT Feather (#5483) was written
against the datasheet only; hardware arrived 3 Aug 2026. Bring-up
verdict: panel orientation (`swap_xy`/`mirror`/40-53 px RAM gap), init
order, and PSRAM framebuffer are all correct, but the first session on
real hardware surfaced one rendering bug and two design gaps, all fixed
here.

**Mirrored glyphs (bug)**: every glyph rendered horizontally mirrored in
its own 16×16 cell (string order and line positions intact;
mirror-symmetric characters like M/i/n/x looked fine, everything else
read backwards — "2"→"S", "6"→"ð", "3"→"Є"). Root cause
(`main/display_tft.c` glyph loop): the shared `FONT8` table is
dhepper/font8x8 layout, where **bit 0 (LSB) of each row byte is the
leftmost pixel** — the convention the OLED backend's `transpose_char()`
(display.c) honors with `1u << col`. The TFT glyph loop tested
`0x80 >> col` (MSB-first), reversing every row byte's pixel order.
One-line fix: test `1u << col`. display.h's FONT8 doc comment claimed
the same wrong "bit 7 = leftmost" convention — corrected.

**Radiation support (design gap)**: a tube-only board (no env/PM
sensors) showed no radiation reading anywhere — the V2.6.11 backend
shipped without any radiation layout on the assumption that "every
deployment of this board pairs it with at least one sensor", and its
rotation collapsed to Uploads + System.

- New **Radiation page in the rotation**, shown first, gated on the new
  snapshot fields `rad_valid`/`rad_nsvph`/`rad_cpm` (written by main.c
  once per TX cycle; `rad_valid` mirrors `tube_enabled`). Layout mirrors
  the OLED single-page screen scaled to this panel: uptime + nSv/h
  header at 2×, big centred CPM at 4× (32 px glyphs), "CPM" unit label.
  Uptime is read live at render time (Uploads/System pattern); the page
  appears once cycle #1 lands (~150 s after boot).
- **mode=RADIATION now honored**: resolves to the OLED-style single-page
  layout (no rotation task; main.c renders via `display_running()` once
  per TX cycle — previously a stub that silently fell back to rotation).
  AUTO still resolves to rotation (big-panel rule). The `/config` Auto
  caption now mentions TFT explicitly.

**4× Env page (too-small text)**: temp/hum/pressure (+ dB when a noise
reading is valid that cycle) now render at 32 px — double the previous
size — via a generalized integer-scale glyph renderer
(`draw_glyph_scaled()`; the 2× path is a wrapper). 4× lines fit
7 characters, so the hPa/dB lines drop their value–unit space
(`1013hPa`).

## V2.6.31 — Width-aware blanking subtraction: fix the warm-weather double-subtract

Field analysis of a deployed FeatherS3-D field node (10,099 syslog cycles,
11 Jul – 1 Aug 2026) established that the Rev B/C phantom pulse's **width is
temperature-dependent**: ≥4 µs when the tube is cool, shrinking below the
4 µs PCNT filter tooth above ~15 °C tube temperature (the "1–4 µs thermal
population" of the V2.6.29 investigation *is* the phantom). That broke the
V2.6.29 subtract mode's core assumption — that every blanked phantom also
sits inside the width-filtered PCNT count. On warm afternoons the width
filter had already dropped the phantoms, and subtracting the full
`hv_blanked` tally on top **double-subtracted** them: measured ~1.5 CPM
under-read at 17–18 °C, projected ~5–6 CPM (−8%) at summer tube temperatures.

**The fix** (`pcnt_blank_wide()` in `main/tube_logic.h`, host-tested): derive
the wide-phantom share from the width filter's own removal tally —

    removed = (counts_raw + hv_blanked) − pcnt_counts   (clamped ≥ 0)
    wide    = hv_blanked − removed                      (clamped to [0, hv_blanked])

— and subtract only `wide` from the filtered count (`do_tx_cycle`), with a
matching monotonic wide total feeding the cpm5/cpm15 rolling averages
(`history.c`, once-per-cycle lump cadence). Cool cycles are unchanged
(removed=0 → wide=hv_blanked, the V2.6.29 subtraction); warm cycles no longer
double-subtract (removed≈hv_blanked → wide≈0). Replaying the formula over the
full 10,099-cycle field dataset: pre-blanking cycles identical except a single
boot charge-train cycle, and the post-V2.6.29 era flattens to ~66 CPM across
every temperature band. The
V2.6.29 operator caveat ("don't combine blanking with the width filter on
narrow-phantom boards — double-subtracts") is retired: on such boards the
subtraction now collapses to ~0 (statistically — a cycle mixing pileup with
narrow phantoms can still mis-attribute a bounded count or two; the clamps
hold either way).

Two observability changes:

- **FILTER log line** now reports both tallies —
  `(removed N, hv_blanked B, W wide subtracted)` replaces
  `(removed N, hv_blanked B subtracted)` (log parsers take note). `B − W` is
  the narrow-phantom share, a free per-cycle phantom-width-vs-temperature
  telemetry channel.
- **Blanking-only nodes keep the PCNT comb**: enabling `hv_blank` without
  `pcnt_filter` now also brings up the width comb at boot as a passive
  diagnostic (counts stay ISR-based — the comb is parallel hardware and never
  touches the count path; only the `pcnt_filter` substitution ever does; a
  live Save starts blanking immediately, the comb from the next restart).

Deployment note: on nodes running pcnt+blank (the trial field node), warm-hour CPM steps
**up** by the previously double-subtracted share — the mirror of the V2.6.29
step down, dated here for archive continuity.

---

## V2.6.30 — Display hardware identity on /status and in the syslog boot banner

The attached display panel was previously only visible in the boot log
(`display backend: ...` from `display.c`), which scrolls away on serial and
never reaches the syslog server — leaving no way to answer "which display is
on that node" for a sealed deployed unit. New `display_backend_str()`
(`main/display.c`) captures the probe verdict at the detection site —
`SerLCD 20x4 @0x72`, `SSD1309 128x64 @0x3C` (chip name per board, address
as probed so a closed SA0 jumper shows as `@0x3D`), `ST7789 TFT 240x135` on
the TFT Feather, or `none` — and surfaces it in two places:

- **`/status`**: new **Display hardware** line directly under **Display
  layout**, so a fleet sweep over HTTP answers the inventory question
  without serial access.
- **Syslog boot banner**: a second `boot:` line (`Display: <panel>`) right
  after the V2.5.22 firmware/reset/partition banner in `syslog_init()`, so
  the panel identity lands on the syslog server on every boot when syslog
  is enabled. Ordering is safe by construction: `display_setup()` runs
  before WiFi (and therefore before `syslog_init()`), so the probe verdict
  is always final by banner time.

No behavioral change to display driving, probing, or layout resolution —
this is observability only.

---

## V2.6.29 — HV blanking window: firmware suppression of the Rev B/C phantom count

New opt-in config setting (under the Dead-time guard on `/config`): **HV
blanking window** — a short deaf window on the count input after each HV
charge pulse. It is the firmware-side mitigation for the Rev B/C PCB coupling
defect established by the July 2026 bench investigation: every HV recharge
pulse couples exactly one phantom NEGEDGE into `GMZ_COUNT`, deterministically
~10 µs (9–16 observed; 3–10 during a boot train) after FET turn-off — the
first ring-down trough of the L1 flyback (80 kHz SRF). On the deployed
FeatherS3-D field node the artifact is visible as `hv_coincident` ==
`hv_pulses` on every single cycle, ~6–9% of counted pulses.

**Keyed on the cause, not the symptom.** The recharge state machine stamps
FET turn-off (`S_PULSE_L` in `recharge_tick`, `main/tube.c`) and the count
ISR drops any would-be count landing within the window (default 30 µs, range
5–1000) of that stamp. Two deliberate choices:

- **Turn-off stamp, not the CAP_FULL edge.** Field data shows one phantom per
  *pulse*, and on a multi-pulse top-up only the last pulse trips CAP_FULL —
  gating there would miss the earlier pulses' phantoms and every boot-train
  pulse. The turn-off stamp covers all of them (CAP_FULL rises at the same
  instant anyway, so the measured 10 µs delay applies unchanged).
- **Time-domain, not width-domain.** The C3-substitution and mod-B bench
  tests both proved the coupled pulse's *width* shifts with hardware details
  (bigger C3 or a lower-loss drain path widens it past the 4 µs PCNT filter),
  so width filtering is not a fleet-safe fix. The blanking window keys on the
  recharge state machine's own clock and is immune to all of that.

**Accounting discipline (same as the dead-time guard):** the blank check is
the last gate before an edge becomes a count, so the new per-cycle DIAG field
`hv_blanked` (after `hv_coincident`, `edt_us` stays positionally last) is the
window's true marginal effect — `counts_without_blank = counts + hv_blanked`.
A blanked edge never updates the last-counted-pulse time, min/max stats,
`hv_coincident`, or the speaker/LED tick. With blanking active on an affected
board, expect `hv_blanked` ≈ `hv_pulses` while `hv_coincident` collapses to
~0. Dead-time cost is ppm-level (`hv_pulses` × window per cycle).

**Deliberately opt-in** — same archive discipline as the V2.5.30 dead-time
guard: the phantoms are *in* the multi-year archive, so enabling this steps a
node's CPM down by its artifact share (~6–9%). Hardware-first remains the
plan (mod C / Rev D layout separation of CAP_FULL from GMZ); this is the
fallback and the per-node diagnostic.

**Composes with the PCNT width filter (subtract mode).** The two features
target different artifacts with a strong operational reason to run both on
the deployed FeatherS3-D: 19 days of its syslog show the width filter
removing a *temperature-driven* narrow-pulse population (near-zero overnight,
peaking 4.7–4.8% of counts at 13:00–15:00) while the phantom rides at a flat
~8%. When both are enabled, the ISR's `hv_blanked` tally is subtracted from
the width-filtered count — per cycle in `do_tx_cycle`, and per minute in the
CPM-history sampler via a new monotonic blanked total
(`tube_get_blanked_total()`). Valid because the PCNT hardware path has no HV
timing, so phantoms wide enough to pass the filter (S3 family, ≥4 µs) sit
inside the filtered count and `hv_blanked` is exactly their tally. ⚠️ Only
combine on such boards: where the filter already drops the phantoms (classic
ESP32 Feather V2, 1–4 µs) the combination double-subtracts — both count paths
clamp (cycle count to 0; the history delta's top-bit wrap reads as 0) so a
mis-configuration degrades visibly rather than corrupting the graph. The
`FILTER:` log line now reports the two effects separately (`removed` = width
filter only, plus an `hv_blanked N subtracted` clause), and the boot config
trace flags "(subtract mode: pcnt count minus blanked)" when both are on.
The dead-time guard keeps its V2.5.30 mutual exclusion with PCNT unchanged.

**Also composes with the dead-time guard** (no exclusion between the two
ISR-side features): the guard classifies first, so an edge inside both
windows tallies as `guard_removed`, and `hv_blanked` can read fractionally
below `hv_pulses` when the guard is on (~0.5% overlap at a 3 ms guard and
background rates).

**Plain counting mode is untouched.** With all three features off the count
path is behaviorally identical: the ISR blank branch is dead code at
`blank_us == 0` (host-tested constant-false), the subtract mode is gated on
the filter being active, and the history sampler's unfiltered branch is
unchanged. The only unconditional addition is the FET turn-off timestamp in
the recharge ISR — a stamp write in the same pattern as the V2.6.9
pulse-start stamp, outside the count path.

Plumbing mirrors the guard throughout: `hv_blank`/`hv_blank_us` config fields
(NVS + POST via the schema), live-applied on Save (the ISR re-reads a
volatile each edge — no reboot), boot-applied in `main.c`, dumped in the boot
config trace. The blank decision and the composes-with-pcnt policy are pure
host-tested helpers (`hv_blank_hit` / `blank_effective_us`,
`main/tube_logic.h`) with six new cases in `test/test_main.c` — including one
that pins the subtract-mode policy so a regression to a pcnt-suppressed
blanking window fails the suite.

---

## V2.6.28 — openSenseMap and Madavi log labels, syslog drop-counter documentation

Observability-only release. No behaviour change on any board: same requests,
same retries, same payloads — only the strings written to the log differ.
The openSenseMap and syslog items came out of a 9-day log review of
a deployed FeatherS3-D field node (V2.6.24, 4,305 cycles); the Madavi label fix and
the wider sweep of the drop-counter comment came out of the pre-release review
of that work.

**openSenseMap STAGING failures no longer log under the production label.**
(`send_osm_to()` in `main/transmission.c`.) `send_osm()` and
`send_osm_staging()` share one core, and every `ESP_LOG` inside it hardcoded
the string `"openSenseMap"`. Only the summary line emitted by the dispatch
table used `tx_target_name()`, so a staging failure read:

```
tx: Sending to openSenseMap STAGING (https)
tx: openSenseMap rc=502 (retry 1/4)          <- actually STAGING
tx: openSenseMap: all retries exhausted      <- actually STAGING
tx: openSenseMap STAGING: error (rc=-1)      <- correct
tx: Sending to openSenseMap (https)
tx: openSenseMap: ok (rc=201)                <- production was fine
```

Read literally that says production failed four times and then succeeded,
which is the opposite of what happened. It also makes the two endpoints
impossible to tell apart when tallying failures across a long run — the
retry lines from both land in the same bucket. The core now takes a `label`
argument and the wrappers pass `tx_target_name()`, so the retry lines cannot
drift from the summary line even if a target is renamed. Six call sites:
box-id-empty, `http_client_init` failure, perform error, 4xx-no-retry, the
per-attempt retry line, and retries-exhausted.

**Madavi labels read from the canonical table too.** (`send_madavi()` in
`main/transmission.c`.) The `http_client_init` failure line said `madavi:`
lowercase while the result line two statements later said `Madavi:` — the same
drift the openSenseMap fix above prevents, caught by the same review. All three
label sites in the function now call `tx_target_name(TX_TARGET_MADAVI)`. Only
the lowercase line changes what it prints; the other two already emitted
`"Madavi"` and are string-identical.

**Syslog drop-counter documentation corrected.** The comments said a non-zero
drop count is "almost always lwIP pbuf-pool exhaustion when a burst outruns
the WiFi/lwIP drain". The field evidence says otherwise: the counter tracks a
down link. `sendto()` is `MSG_DONTWAIT` with no queue behind it, so once WiFi
drops there is no route and every emit fails immediately — drops arrive as one
burst sized to the outage, then stay flat. The 9-day run logged 163 drops, all
inside a single 2m25s AP channel-change outage (beacon timeout, then 47 x
`NO_AP_FOUND` while the AP moved ch 10 -> 6 -> 4), and zero otherwise; the
prior boot logged 160 the same way.

Burst pressure is not hypothetical, though — it was the *pre-pacing* failure
mode. V2.5.29 confirmed the boot config dump outrunning the WiFi/lwIP drain on
the tight-heap heltec and fixed it by yielding after every line (see
`config_log_summary()` in `main/config.c`), and it has not recurred since. The
corrected text says that, rather than dismissing pbuf exhaustion outright, and
says how to read a step in the counter — look for a disconnect at that
timestamp — noting the losses are syslog-only, since applog's ring still serves
`/log` and the scheduled FTPS upload.

Corrected in all four places the claim appeared, not just the one that
prompted it: the `s_drop_count` declaration and the `emit_packet()` increment
site (`main/syslog.c`), the `syslog_get_stats()` public contract
(`main/syslog.h`), and the per-cycle reporting site (`main/transmission.c`).
A single-site fix would have left the file contradicting itself 170 lines
apart, with the header still stating the refuted cause.

---

## V2.6.27 — LoRaWAN time-sync budget, SerLCD row-write helper, clang-format

Housekeeping release with a single behaviour change, confined to LoRaWAN
boards. Everything else is refactor and tooling: the SerLCD panel renders
byte-for-byte what V2.6.26 rendered.

**LoRaWAN `DeviceTimeReq` give-up budget, 3 → 5 attempts per daily window.**
(`TIMESYNC_MAX_ATTEMPTS` in `main/lorawan.cpp`; reaches hardware only on
`heltec_wifi_lora32_v4_r2`.) The node asks the network for the time once per
24 h and re-arms the request on each TX cycle until a `DeviceTimeAns`
downlink lands. The give-up rule shipped in V2.6.26 caps how many unanswered
requests that costs, because every request the network *hears* makes it
schedule a downlink whether or not the node can receive it — a node with a
working uplink but a dead downlink would otherwise drive ~576 pointless
gateway transmissions a day, each one deafening the gateway to every other
node for its duration. Three attempts proved tight in the case that matters
most: a cold boot that misses its first windows then sits on 1970 timestamps
until the next daily window comes round. Five makes that materially less
likely for a bounded worst case of 5 scheduled downlinks/day — still inside
TTN's Fair Use allowance of 10.

**`serlcd_write_at()` in `display_serlcd.c`.** Every row this driver draws
was written as a `serlcd_set_cursor()` + `serlcd_write_text()` pair — 31
sites, all identical, 27 of them squeezed onto one line to keep each page's
row layout readable as a block. Folded into a single
`serlcd_write_at(col, row, s)` so the pairing can't drift apart and a write
can't land at whatever position the previous page left the cursor at. The
two underlying statics are deliberately kept rather than merged into the
helper: they clamp against different failure modes — `serlcd_set_cursor()`
guards against addressing a non-existent row, `serlcd_write_text()` against
HD44780's non-linear 4-row DDRAM layout wrapping over-long text onto an
unrelated row. Net −96 bytes of flash on `feathers3_d` (measured A/B), which
is the honest measure of how much of this was duplicated call setup.

**`.clang-format`, applied to changed lines only.** New tracked config, used
via `git clang-format` (local `_format.cmd` wrapper) so it only ever
reformats lines already edited. A full-tree sweep was measured and rejected:
over `main/` it rewrote ~5,100 lines across 62 files, of which only about a
tenth are genuine line splits — the remainder is pure re-indentation and
comment-column churn, i.e. clang-format overriding coherent existing hand
formatting rather than fixing anything. Worst hit are `hal.h` (all ~1,240
lines, because flattening preprocessor indentation destroys the
`#if`/`#define` board-selection tree) and `http_server.c` (~1,190 lines of
shredded `// V2.x.y:` annotation columns), followed by the data tables whose
meaning lives in the column layout: SSD1306 init byte pairs in `display.c`,
the UBX frame-parser state ladder in `gnss.c`, RMT symbol timing pairs in
`neopixel.c`. Changed-lines-only preserves all of it for free, so there are
no `// clang-format off` markers anywhere and no `.git-blame-ignore-revs`.
Deliberately NOT added to `_build.cmd` beside the cppcheck gate: formatter
output shifts between major clang-format versions, so a hard gate would fail
builds on a toolchain upgrade alone.

## V2.6.26 — LoRaWAN observability, session-reset endpoint, network time sync

First-live-gateway release: everything below came out of the first bench
sessions against a real TTN gateway (OTAA join, uplinks, downlinks all
verified end-to-end on `heltec_wifi_lora32_v4_r2`).

**Per-uplink logging.** Successful uplinks were previously silent (counters
on `/status` only), which made `/log` look like LoRaWAN was doing nothing.
Every accepted uplink now logs one line with the payload summary and the
radio parameters of the frame actually on air, e.g.
`uplink OK: port 2 (T=16.8°C H=65.5% P=1018.8 hPa) FCnt=79 DR5 917.4 MHz 10 dBm`.
Two correctness details so the line matches the TTN console digit-for-digit:

- FCnt comes from `getFCntUp()` after the send, not the uplink event —
  RadioLib increments its internal counter for the *next* frame before
  filling the event struct, so `ev.fCnt` reads one higher than the wire.
- Port-2 values are decoded back from the wire bytes rather than printed
  from the raw sensor floats: the V1.9-frozen codec truncates (temp×10,
  hum×2, Pa/10, all toward zero) while `%.1f` rounds, so e.g. a 16.89 °C
  reading went on air as 16.8 but would have logged as 16.9.

Also new: the join/resume line carries region + sub-band, the downlink line
carries FCntDown + RSSI/SNR, and each TX cycle logs a one-line health
summary (`LORA: state=joined up=6 fail=0 duty_skip=0 joins=1 last_err=0`).
The misleading `skipping TX: WiFi down` became `skipping WiFi TX: WiFi
down (LoRaWAN uplink unaffected)` — the LoRaWAN enqueue sits deliberately
ahead of the WiFi/NTP gates, so on radio nodes "TX skipped" never meant
"nothing was sent". Suffix is compile-gated on `HAL_HAS_LORAWAN` so a
non-radio board with a stray `lorawan_enabled` NVS byte can't claim an
uplink path it doesn't have.

**`/lorawan_reset` (POST, auth + CSRF like `/reboot`).** New "LoRaWAN
session" form on `/config`: erases the persisted session from NVS and
reboots into a fresh OTAA join — needed when the network-side session dies
(device deleted/re-added in the TTN console), where the node would
otherwise "session resumed" forever into a network that no longer accepts
its frame counter. The DevNonce history is deliberately KEPT by default:
LoRaWAN 1.0.4 DevNonce is a monotonic counter the join server tracks, so
wiping it makes every later join-request look like a replay (silently
dropped). An explicitly-labeled checkbox wipes it too, for the
re-registered-device case — only after "Reset used DevNonces" in the TTN
console.

**Network time sync (DeviceTimeReq).** Standalone LoRaWAN nodes have no
NTP, so log/display timestamps sat in 1970. The worker now piggybacks a
DeviceTimeReq MAC command on the first uplink after boot and every 24 h
after; the answer (GPS-epoch, converted to unix UTC by RadioLib) is applied
via `settimeofday()` with a ±2 s step threshold, and the configured POSIX
TZ renders it locally — same machinery as NTP, new source. Guards:

- Authority: applied only while SNTP has never synced this session
  (`ntp_boot_epoch() == 0`). NTP stays the sole clock owner the moment it
  ever syncs. Deliberately NOT gated on `ntp_time_valid()` — that is a
  plausibility check (clock past 2026-01-01) that turns true the moment we
  set the clock ourselves, which would kill the daily re-sync.
- Downlink budget: once daily, never per-round — every answer is a network
  downlink and TTN fair use allows 10/day. After 3 unanswered requests
  (uplink-only/asymmetric link: the network would schedule an unheard
  downlink per uplink) the worker defers to the daily window with a single
  warning instead of re-requesting each cycle.
- Accuracy: the applied time runs ~5-6 s behind true UTC — the answer's
  time field is captured at the end of the uplink that carried the request
  and the RX1 delay is not recoverable through RadioLib's API. Accepted:
  this rescues standalone nodes from 1970-era timestamps, it is not NTP,
  and since the lag is roughly constant, later daily syncs land inside the
  ±2 s threshold and take the no-step path. A stale-answer guard ignores a
  byte-identical repeat of the previous answer (RadioLib's answer store is
  non-consuming and only cleared by the next downlink), so a leftover
  answer heard hours ago can never step a previously-correct clock back.

---

## V2.6.25 — DHCP hostname shown on /status Network block and /update OTA page

The DHCP hostname is now displayed on the `/status` Network block (STA and
AP-mode branches, above the IP) and on the `/update` OTA page (below
"Current firmware") — on the OTA page it doubles as an "am I about to
flash the right device?" check on multi-node fleets. The formerly fully
static `/update` page is streamed as head + escaped hostname + tail chunks
so the runtime value never passes through a format string.

`update_get`'s chunk sends use the same per-chunk check +
best-effort-terminator idiom as `status_get`, so the file carries one
chunk-send failure convention instead of three; on a 3-chunk page the
checks are behaviorally inert. The hostname chunk is skipped when the
value is empty — a zero-length chunk is httpd's end-of-stream terminator,
which would have cut the page off before the upload form (reachable: an
empty `wifi_host` saved on `/config` persists until the boot-time
auto-default refill).

---

## V2.6.24 — led_tick prefers the NeoPixel on dual-LED boards; syslog hostname off-by-one; sensor.community default off on fresh boards

Boards that have both a plain user LED and a WS2812 NeoPixel
(`adafruit_esp32s3_feather_4mb_2mbpsram` #5477 and
`adafruit_esp32s3_tft_feather` #5483) now flash the **NeoPixel** (blue,
40 ms) on each Geiger pulse instead of the red "#13" LED.

- WHY: the original port decision routed `led_tick` to `PIN_LED_BUILTIN`
  purely because that reused `speaker.c`'s existing `#ifdef` chain with zero
  code changes — not for any GPIO or electrical reason. At #5477 bench
  bring-up the NeoPixel was settled on as the intended pulse indicator
  wherever one exists.
- `speaker.c` `tick_start()` now checks `HAL_HAS_NEOPIXEL` first and falls
  back to `PIN_LED_BUILTIN` only on NeoPixel-less boards (Heltec V2,
  feathers3_d; the Heltec V4 R2's LED is driven by `led.c`, not this
  fallback — its speaker is disabled). Boards with a NeoPixel and no plain
  LED (QT Py, SparkFun S3/C5, Feather V2) are unchanged — they already
  used the NeoPixel.
- The red "#13" LED on the two dual-LED Feathers is still configured and
  driven to a deterministic OFF at boot, reserved for future status use.

The sensor.community TX target now defaults to **off** on freshly flashed
boards (`send_sensorc`, `config_fields.def`) — a new device shouldn't
upload to the public map until its owner deliberately opts in. Devices
that have saved `/config` at least once are unaffected: the saved
`send_sc` NVS key always wins over the compile-time default. Since WiFi
provisioning itself is a `/config` save, every normally-provisioned device
on a recent firmware already has the key stored. The one edge that flips:
a device whose saved config predates the `send_sc` key entirely (and was
never re-saved since) loses sensor.community upload after updating to
V2.6.24 and needs the checkbox re-ticked once.

An audit of the same buffer-sizing class led to a full rework of the `/config` +
`/status` HTML-escape buffers (`http_server.c`): every `e_*` destination
was sized to a ~3-4x convention while `html_esc()`'s true worst case is
**6x** (`"` → `&quot;`), so metacharacter-dense values were silently
truncated — and on `/config` a truncated value re-displayed in the form is
PERSISTED back by the next Save. All escape destinations are now sized
`ESC_WORST(source max) = max * 6 + 2` (the +2 covers html_esc's strict
loop-guard reservation); the `/config` workspace moved from
~4.5-4.9 KB of permanent BSS to a single heap-transient struct that exists
only while the page renders (returning that BSS to the heap on every
board, which matters most on the Heltec V2), and the PEM cert buffer grew
to its honest worst case too.

Also fixes a syslog hostname off-by-one: `syslog.c`'s private hostname
mirror was a bare `[32]` (31 chars + NUL), silently truncating 32-character
hostnames in the RFC 5424 HOSTNAME field — while the web form, config
struct (`CFG_HOSTNAME_MAX + 1`), NVS, and DHCP all carried the full name.
Now sized `CFG_HOSTNAME_MAX + 1` like the cfg field it mirrors. 32 chars is
exactly ESP-IDF's `esp_netif_set_hostname()` limit, so the whole chain now
agrees end-to-end. (Spotted on the #5477 bench: the router showed
`...esp32-S3`, syslog showed `...esp32-S`.)

---

## V2.6.23 — LoRaWAN uplink (heltec_wifi_lora32_v4_r2) + generalized keep-AP-on

Ships the LoRaWAN feature line built across Tasks 1-8: OTAA/Class A uplink
support for the `heltec_wifi_lora32_v4_r2` board via RadioLib 7.2.1, plus a
config-UI checkbox (keep the AP on permanently) that was previously
SD-standalone-only and is now available on every board.

### LoRaWAN uplink (heltec_wifi_lora32_v4_r2 only)

- New `lorawan.cpp` drives an SX1262 radio over the module's dedicated
  internal SPI bus (RadioLib 7.2.1), joining via OTAA and transmitting
  Class A uplinks on a duty-cycle-guarded schedule.
- Uplink payloads on FPort 1 (GM counts/interval/firmware version/tube type)
  and FPort 2 (temperature/humidity/pressure) are byte-identical to the
  Multigeiger V1.9 Arduino firmware's TTN frames (`lorawan_codec.h`,
  ported from `transmission.cpp`'s `send_ttn_geiger`/`send_ttn_thp`), so
  existing TTN Console decoders and ttn2luft ingestion keep working
  unchanged. A ready-to-paste TTN "Custom Javascript formatter" is now
  published at `docs/ttn_payload_formatter.js`.
- `/config` gained an all-region LoRaWAN section (frequency-plan dropdown
  covering the regions RadioLib supports, DevEUI/JoinEUI/AppKey entry,
  join status). Session state (DevAddr, session keys, frame counters)
  persists across reboots in NVS so a device doesn't have to rejoin on
  every power cycle.
- Two checkboxes — `lora_fem_en` ("Drive FEM enable (GPIO2)") and
  `lora_hp` (FEM high-power/PA select, GPIO46) — are exposed for
  **reworked hardware only**. On stock/unmodified boards, GPIO2 is
  double-booked with the HV cap-full comparator input and GPIO46 with the
  mainboard's DIP1 switch; asserting either pin on unmodified wiring would
  contend with the live signal already driving it, so both default off and
  must stay off unless the board has had the corresponding copper rework
  done. See `hal.h`'s `PIN_LORA_FEM_EN`/`PIN_LORA_FEM_PA` comments for the
  full double-booking rationale, and note that on unmodified boards the
  GC1109 front-end's RX-enable line is left wiggling by the comparator, so
  LoRaWAN RX (downlink) reliability there remains an open bench question.
- Bench status, stated plainly: radio bring-up (SPI init, RadioLib object
  construction) and the join-request TX + backoff/retry path are
  bench-verified on real V4-R2 hardware. Join-accept and full end-to-end
  uplink delivery are **not yet** confirmed — that leg is pending
  availability of a TTN gateway in range of the bench unit, not a known
  code defect.

### Generalized keep-AP-on checkbox (all boards)

- The "keep config AP on permanently" checkbox (`sd_ap_on` internally, for
  history — it started as an SD-standalone-only option) is now honored by
  `main.c` in every operating mode, not just SD-standalone. One latch
  (`s_standalone_ap_on_latched`), captured once at boot and never
  re-read from `g_cfg` afterward, decides whether the AP + httpd stay up
  forever or the radio fully powers down at the config window's close —
  same semantics as before, just no longer conditional on SD-standalone
  being active.

---

## V2.6.22 — SD/status diagnostic accuracy, loud GPIO bring-up, doc-rot cleanup

A hardening and diagnostics batch: /status now reports SD-card errors
accurately (correct error domain, no stale values after a card pull),
boot-time GPIO setup aborts loudly on a board-port mistake instead of
failing silently, and the Geiger-pulse NeoPixel flash is now visually
distinct from the SD-failure alert. Plus a set of stale documentation
claims corrected. No changes to counting, uploads, or storage formats.

### Vext power-gating doc rot eradicated (Heltec V4-R2)

- v2.6.20 fixed the wrong "Vext doesn't gate the OLED" claim in three places
  but left it standing in three others: `i2c_bus.h`'s per-board behaviour
  block, its `i2c_bus_get_secondary()` doc comment ("there is no LDO to drop
  — the bus stays up regardless"), and `i2c_bus_finalize()`'s V4-R2 branch
  ("No gating GPIO on this board"). All three now state the truth: the OLED
  bus is Vext_Ctrl-gated (GPIO36, active-LOW), driven before controller
  creation, and the rail is deliberately never dropped (a missing consumer
  means a failed OLED probe, not a power-save case). The original V2.6.7 bug
  was born from a wrong power claim outliving its refutation — this class is
  now clean.

### hal.h PIN_VEXT comment accuracy

- Reserved-list GPIO36 bullet no longer claims it was "moved out of this
  list" while sitting in it: it stays reserved (it's the module's power-gate
  control, never free GPIO), it's just firmware-driven now.
- PIN_VEXT comment documents the side effect that the same MOSFET feeds the
  external "Ve" header (500 mA peripheral rail) — energized from boot on
  every unit since v2.6.20; relevant to battery deployments.

### ESP_ERROR_CHECK on boot-time GPIO bring-up

- The `gpio_reset_pin`/`gpio_set_direction`/`gpio_set_level` triples used
  at boot were never error-checked anywhere (unlike the `gpio_config()`
  call sites, which all check loudly: tube.c, speaker.c ×
  ESP_ERROR_CHECK; led.c, neopixel.c × log). Per IDF v6.0 source these
  calls fail ONLY on invalid or input-only pin constants — a compile-time
  board-port mistake (classic
  ESP32's GPIO34-39 are input-only, and `gpio_set_direction` silently no-ops
  on them; three classic-ESP32 boards live in this tree). Such a mistake is
  deterministic per board, so it can never pass the bench then fail in the
  field — abort semantics are safe, same argument as the radio-off
  `ESP_ERROR_CHECK` pair.
- Applied to the run-once bring-up sites: all four rail-gate blocks in
  `i2c_bus.c` (Heltec V2 Vext, TFT-Feather/#5477 I2C power gate, FeatherS3-D
  LDO2, V4-R2 Vext), the OLED reset-pin setup in `display.c`, and the
  antenna-select in `main.c`. Hot-path `gpio_set_level` calls (speaker/tube/
  led per-tick) deliberately left bare — abort risk in pulse paths for zero
  diagnostic value.
- Converts a future misport from "every I2C probe times out, bench session
  to root-cause" (the exact V2.6.7 dead-OLED signature) into an instant
  first-boot abort naming the offending line.

### /status "Last error" now names the actual error

- `sd_logger.c::fail_cycle()` mixed two error domains into one `int` rendered
  with a bare `%d`: `sd_card_mount()` failures are `esp_err_t` (so
  `ESP_ERR_TIMEOUT`/`0x107` displayed as a baffling "263"), while file
  create/write failures are `errno`. `fail_cycle()` now tags the domain,
  `sd_logger_status_t` carries `last_err_is_esp`, and /status renders
  `ESP_ERR_TIMEOUT` vs `errno 5 (I/O error)` accordingly (serial log line
  likewise).
- `errno` is now captured BEFORE `close_file_for_remount()` — the cleanup's
  own `fclose`/unmount could overwrite it, so the number shown on /status
  could be the cleanup's errno, not the real failure's. Diagnostic accuracy
  only; retry/alert behaviour unchanged.

### /status SD-card cosmetics after a card pull

- Row count no longer lingers: after a card pull, /status showed the dead
  file's `rows_written` next to no filename. `close_file_for_remount()` now
  zeroes the count together with the filename.
- Torn-filename read closed: the httpd task snapshots the filename while the
  main service task creates/clears it. Both sides now go through a tiny
  `portMUX` critical section (`s_status_mux`), and `create_file()` publishes
  the new name only after the header row is safely fsync'd — /status can
  never show a half-written name or a name with no live file behind it.

### CSV header-length contract made explicit

- A future sensor registering a CSV column header longer than 23 chars would
  have silently truncated the CSV header row (data rows still full-width — a
  misaligned CSV with no error anywhere). New `TELEMETRY_HEADER_MAX_LEN` (23)
  in `telemetry.h` documents the limit; `telemetry_register()` now rejects
  over-long headers loudly (same non-fatal drop contract as registry-full);
  `sd_logger.c` static-asserts the cap against its `CELL_MAX` row budget.
  Today's longest header is 22 chars — no behaviour change for any current
  sensor.

### Doc rot + cosmetics

- `sd_logger.c`: two stale claims fixed — "status read unconditionally on
  every board" (the /status card is `HAL_HAS_SD_CARD`-gated) and "init
  called unconditionally from main.c" (it is gated on the SD boot-latch
  mode).
- `sd_logger.h`: "DateTime UTC" column doc updated for V2.6.21's local-time
  change (header is now "DateTime", local time with numeric UTC offset;
  filename stamp likewise local).
- `fuel_gauge.c`: comment claimed env_sensor's dual-bus probe can call
  `fuel_gauge_init()` twice — main.c calls it exactly once and the `s_ready`
  guard would short-circuit a second call anyway; the `s_tm_registered` guard
  is belt-and-braces, not load-bearing. Justification corrected, guard kept.
- `hal.h`: `HAL_HAS_SD_CARD` value column was 2 chars right of its neighbours
  in the four narrow-alignment board sections (heltec_v2, feathers3_d,
  adafruit_qtpy_esp32_pico, seeed_xiao_esp32s3); the V2.6.19 GPIO25
  reserved-pin comment rewrapped to house width.

### Geiger-pulse NeoPixel flash: blue, was red

- On the four boards whose pulse indicator is the NeoPixel (QT Py, SparkFun
  Thing Plus S3/C5, Adafruit Feather V2), the per-count flash is now dim
  blue (0,0,20) instead of dim red — a tube pulse can no longer be confused
  with the solid-red SD-failure alert at a glance, and during an active
  alert the pixel reads "blue blink per count, solid red in between".
  Boards whose pulse tick is a plain onboard LED (TFT Feather, #5477, all
  non-NeoPixel boards) are unaffected. Alert colour unchanged (red, 64,0,0).

### Per-cycle write confirmation in /log

- `sd_logger: row N written to <file>` at INFO after every successful
  (fsync'd) CSV row. Previously only failures logged, so /log showed the
  sensor readings but never that they landed on the card — "logging fine"
  and "logging silently stopped" looked identical between error lines.

## V2.6.21 — Standalone SD-logging: fix card-pull crash, local-time CSV, unified heap diagnostics

### Fix SD card-pull crash (LoadProhibited, httpd task)

- Bench-crashed twice (2026-07-16) pulling the SD card live on
  `sparkfun_thing_plus_esp32s3`: `LoadProhibited` at `excvaddr=0xc`, backtrace
  `esp_vfs_select → httpd_server → httpd_thread`, always on the `httpd` task,
  always right after an unmount.
  - Root cause (confirmed via coredump SHA-verified decode, not a race):
    ESP-IDF's `esp_vfs_unregister_with_id()` NULLs the freed slot in the
    global `s_vfs[]` VFS table but never shrinks `s_vfs_count`, leaving a
    *persistent* hole until the next successful mount refills it.
    `esp_vfs_select()`'s own NULL-slot guard (`vfs_calls.c:660`) then executes
    `ESP_LOGD(..., vfs->offset)` on a NULL `vfs` — `offset` sits at struct
    byte-offset `+0xc`, matching both coredumps exactly. Deterministic on
    httpd's very next `select()`, no concurrency required, once the card is
    out and every remount keeps failing.
  - Fix: `CONFIG_LOG_MAXIMUM_EQUALS_DEFAULT=y` (was
    `CONFIG_LOG_MAXIMUM_LEVEL_DEBUG=y`) in `sdkconfig.defaults` — compile-time
    ceiling drops to INFO, dead-code-eliminating that `ESP_LOGD` line
    project-wide. Doesn't touch any `wifi:`-tagged driver output (that's all
    I/W-level, unaffected by the ceiling either way).
  - `sd_card.c` also gained `run_serialized_with_httpd()`: mount/unmount now
    run via `httpd_queue_work()` onto the httpd task itself (new
    `http_server_get_handle()` getter), kept as defense-in-depth against the
    separate, genuine ESP-IDF-acknowledged race where a cross-task unregister
    can free a `vfs_entry_t` while another task's in-flight `select()` has
    already fetched a pointer to it.
  - Bench-confirmed fixed: full pull → write-fail → unmount → retry-mount-fail
    (card still out) → retry-mount-succeed (card reinserted) → new CSV
    created → normal steady-state cycles, zero crashes throughout.
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

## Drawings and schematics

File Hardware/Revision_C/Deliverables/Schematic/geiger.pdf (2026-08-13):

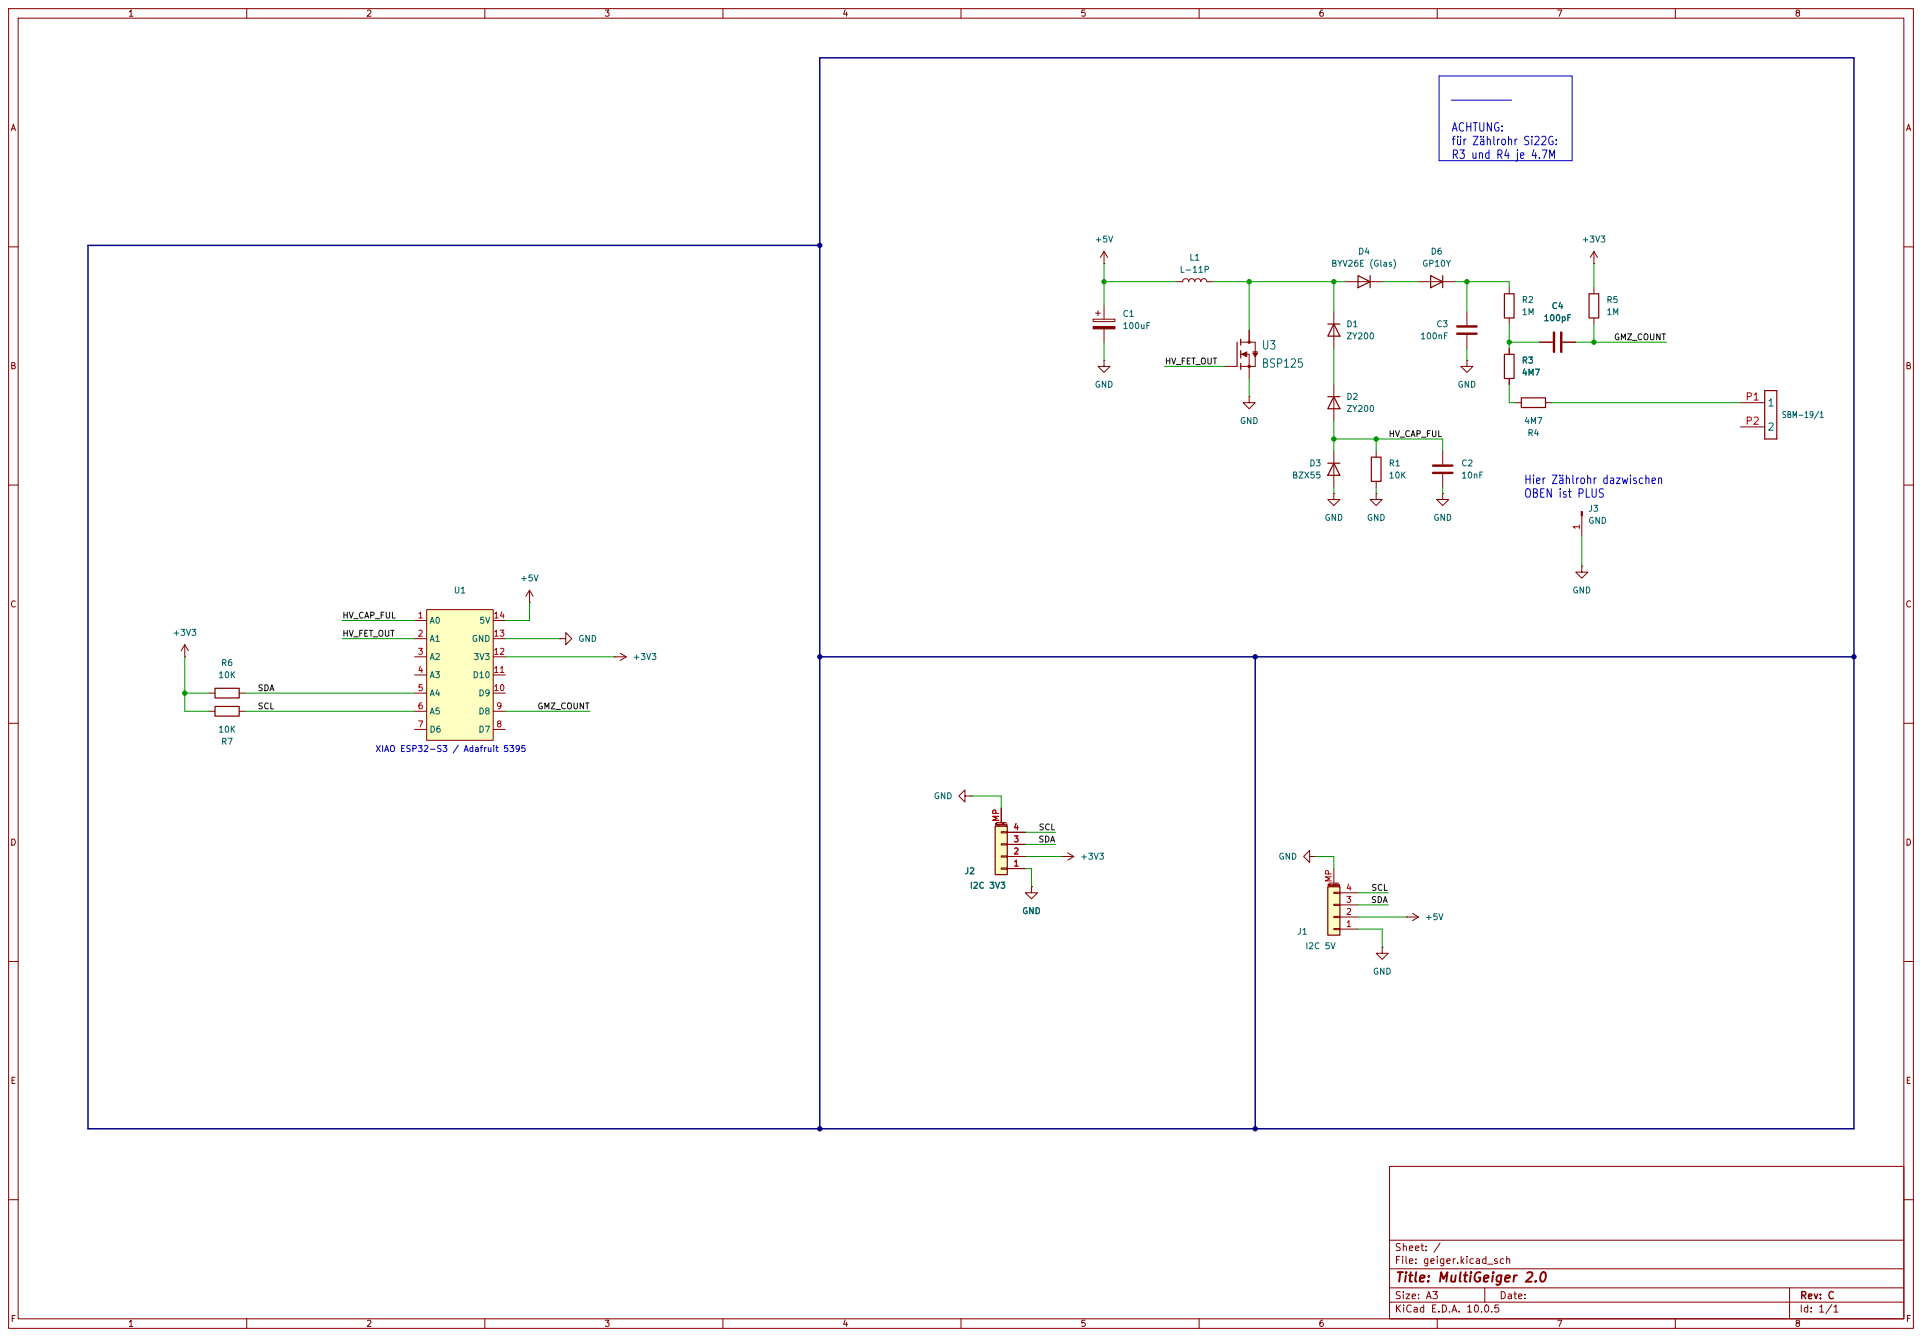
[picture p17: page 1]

Size: A3 | Rev: C | F Date:
KiCad E.D.A. 10.0.5 | Id: 1/1

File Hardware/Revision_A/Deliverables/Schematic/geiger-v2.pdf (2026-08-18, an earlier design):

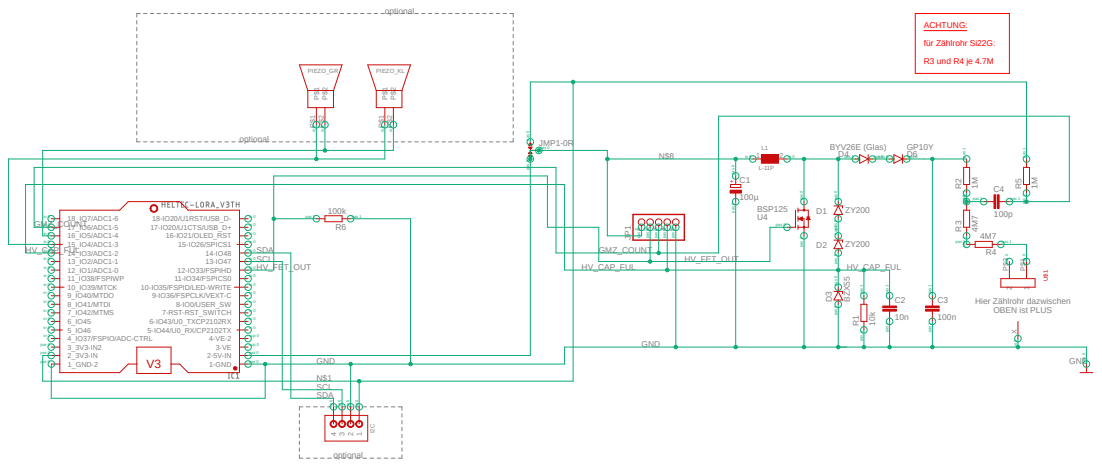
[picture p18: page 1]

pwr 0 | GND

N$1
SCL

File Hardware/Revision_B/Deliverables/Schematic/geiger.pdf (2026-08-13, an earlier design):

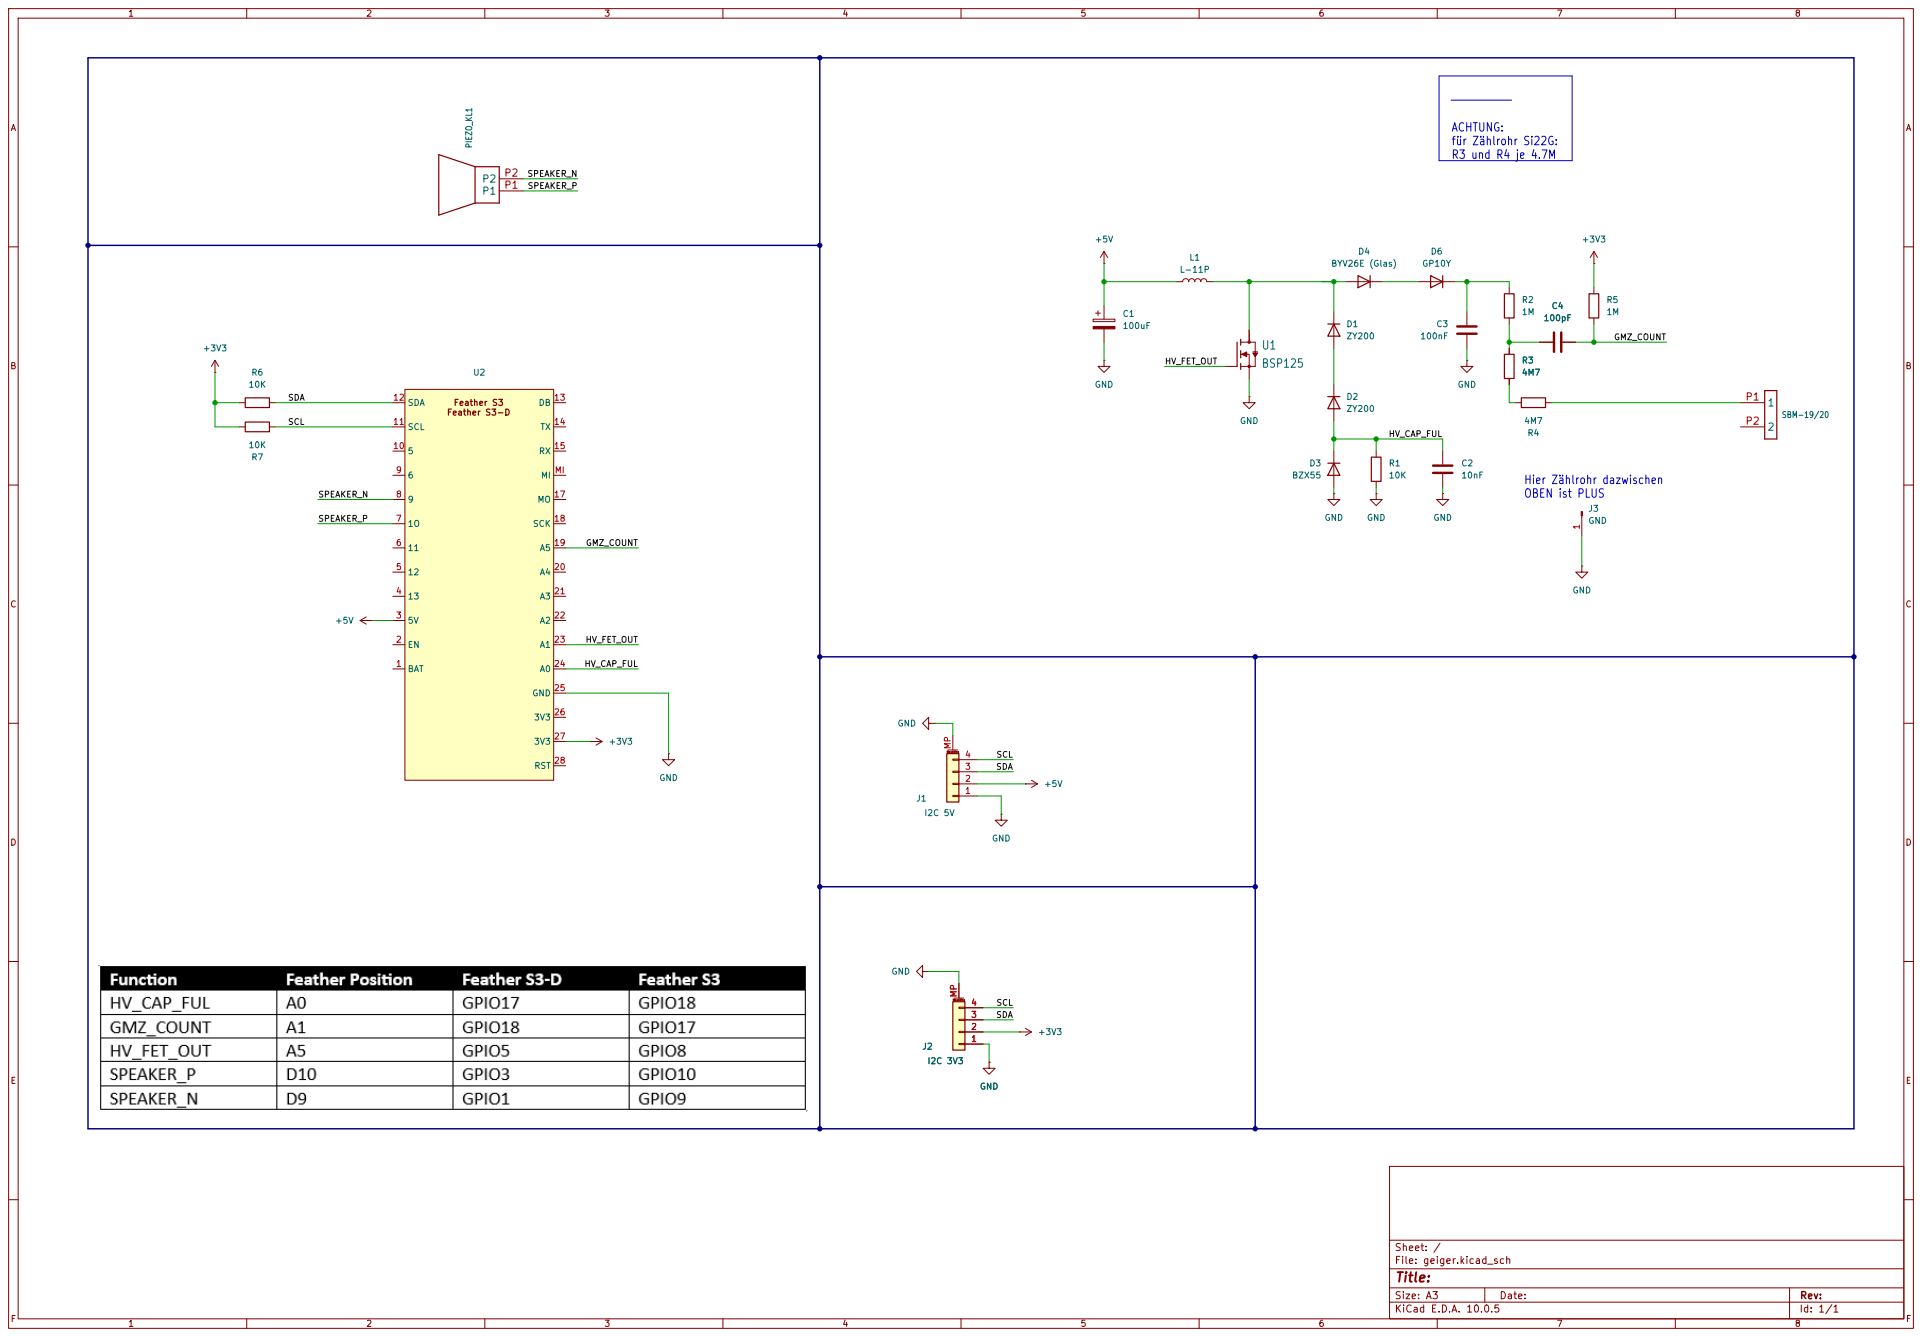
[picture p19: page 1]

Size: A3 | Rev: | F Date:
KiCad E.D.A. 10.0.5 | Id: 1/1

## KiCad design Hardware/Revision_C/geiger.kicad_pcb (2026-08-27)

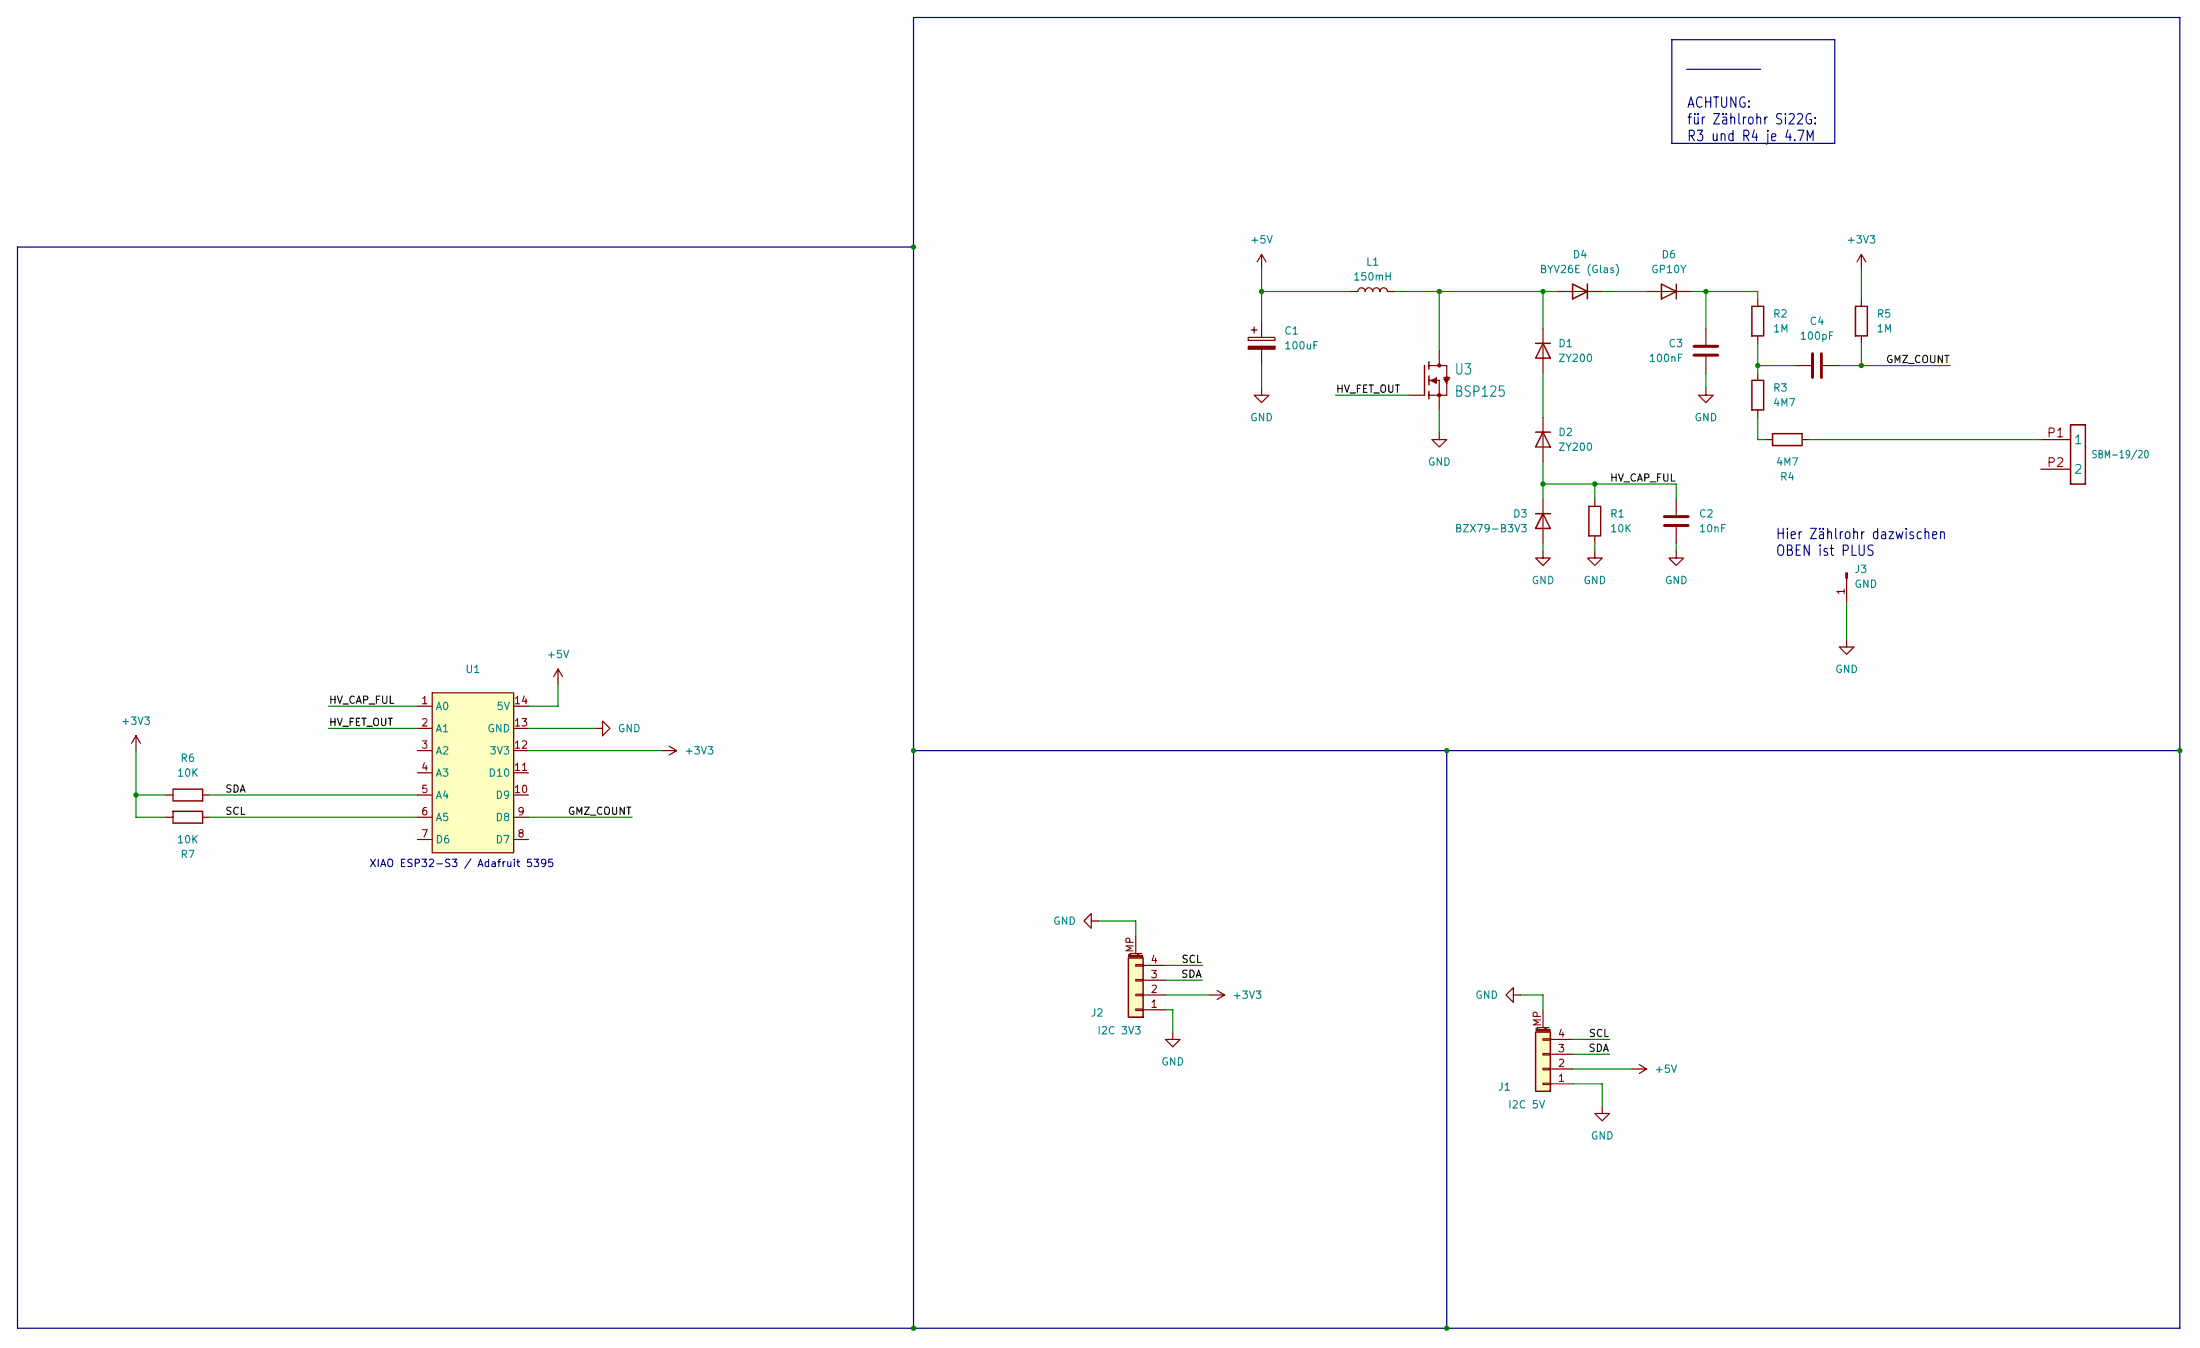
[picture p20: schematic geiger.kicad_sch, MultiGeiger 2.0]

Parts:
C1: 100uF; E2-5_334; Part Number 16SEPC100MW
C2: 10nF; C050-045X075_334; Part Number MKP2D021001B00KSSD
C3: 100nF; C150-072X183_334; Part Number R76PI31005050J
C4: 100pF; C050-045X075_334; Part Number FKP2O101001D00JSSD
D1, D2: ZY200; DO41-10_210; Part Number ZY200
D3: BZX79-B3V3; DO41-10_210; Part Number BZX79-B3V3,133
D4: BYV26E (Glas); DO41-10_210; Part Number BYV26E
D6: GP10Y; DO41-10_210; Part Number GP10Y
J1: I2C 5V; JST_PH_S4B-PH-SM4-TB_1x04-1MP_P2.00mm_Horizontal; Part Number PH-4P
J2: I2C 3V3; JST_SH_SM04B-SRSS-TB_1x04-1MP_P1.00mm_Horizontal; Part Number SM04B-SRSS-TB(LF)(SN)
J3: GND; TestPoint_Loop_D1.80mm_Drill1.0mm_Beaded
L1: 150mH; L-11P; Part Number 11P-154J-50
R1, R6, R7: 10K; 0207_10_334; Part Number UXB02070F1002AR100
R2, R5: 1M; 0207_10_334; Part Number RNV14FAL1M00
R3, R4: 4M7; 0207_10_334; Part Number RNV14FAL4M70
SBM-19/20: FUSE_HOLDER; Part Number 8040.0003
U1: XIAO ESP32S3
U3: BSP125; SOT223; Part Number BSP125H6327

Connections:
+3V3: J2.2, R5.1, R6.1, R7.2, U1.12 (3V3)
+5V: C1.+, J1.2, L1.1, U1.14 (5V)
/GMZ_COUNT: C4.2, R5.2, U1.9 (D8)
/HV_CAP_FUL: C2.1, D2.A, D3.C (K), R1.1, U1.1 (A0)
/HV_FET_OUT: U1.2 (A1), U3.1 (G)
/SCL: J1.4, J2.4, R7.1, U1.6 (A5)
/SDA: J1.3, J2.3, R6.2, U1.5 (A4)
GND: C1.-, C2.2, C3.2, D3.A, J1.1, J1.MP (MountPin), J2.1, J2.MP (MountPin), J3.1 (Pin_1_1), R1.2, U1.13 (GND), U3.3 (S)
unnamed: C3.1, D6.C, R2.1
unnamed: C4.1, R2.2, R3.1
unnamed: D1.C (K), D4.A, L1.2, U3.2 (D), U3.4 (D)
unnamed: D1.A, D2.C (K)
unnamed: D4.C (K), D6.A
unnamed: R3.2, R4.2
unnamed: R4.1, SBM-19/20.P1 (1_P1)

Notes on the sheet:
Hier Zählrohr dazwischen OBEN ist PLUS
XIAO ESP32-S3 / Adafruit 5395
ACHTUNG: für Zählrohr Si22G: R3 und R4 je 4.7M

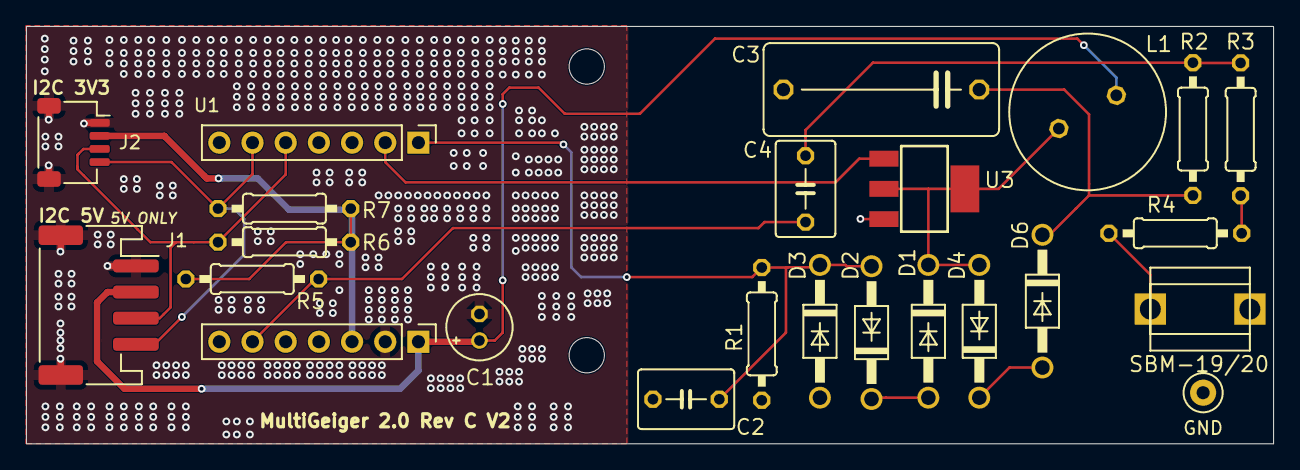
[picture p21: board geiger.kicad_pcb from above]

Board: 2 copper layers, 95.5 x 31.9 mm, 23 parts (0 on the bottom side), 15 nets.

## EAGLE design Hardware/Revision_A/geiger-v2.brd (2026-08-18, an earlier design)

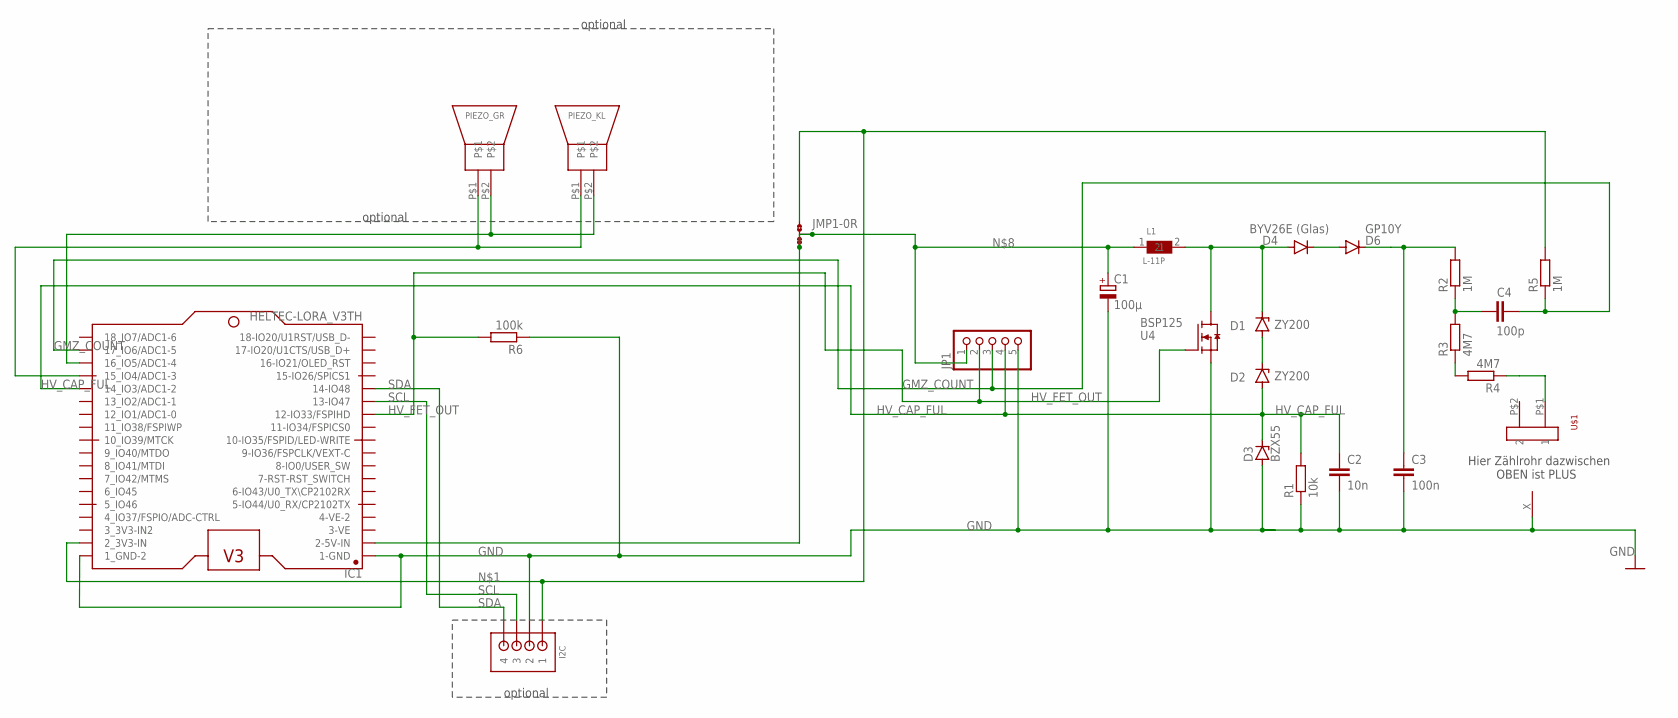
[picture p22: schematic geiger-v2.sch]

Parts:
C1: 100µ; E2-5
C2: 10n; C050-035X075
C3: 100n; C150-072X183
C4: 100p; C050-045X075
D1, D2: ZY200; DO41Z10
D3: BZX55; DO35Z10
D4: BYV26E (Glas); DO41-10
D6: GP10Y; DO41-10
I2C: B4B-ZRSIDE_ENTRY; S4B-ZR
IC1: HELTEC-LORA_V3TH; HELTEC_LORA_32
JMP1: 0R-JUMPB; B0R-JMP
JP1: PINHD-1X5; 1X05
L1: L-11P
PIEZO_GR: PIEPSER_BIG
PIEZO_KL: PIEPSER
R1: 10k; 0207/10
R2, R5: 1M; 0207/10
R3, R4: 4M7; 0207/10
R6: 100k; 0207/10
U4: BSP125; SOT223
U$1: FUSE_HOLDER
U$5: ONE_PAD

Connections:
3_3V3-IN2: IC1.3_ (3_3V3-IN2)
GMZ_COUNT: C4.2, IC1.17_ (17_IO6/ADC1-5), JP1.3, R5.1
GND: C1.-, C2.2, C3.2, D3.A, I2C.2, IC1.1- (1-GND), IC1.1_ (1_GND-2), JP1.5, R1.1, R6.1, U4.3 (S), U$5.X
HV_CAP_FUL: C2.1, D2.A, D3.C, IC1.14_ (14_IO3/ADC1-2), JP1.4, R1.2
HV_FET_OUT: IC1.12- (12-IO33/FSPIHD), JP1.2, R6.2, U4.1 (G)
unnamed: I2C.1, IC1.2_ (2_3V3-IN), JMP1.1, R5.2
unnamed: D1.A, D2.C
unnamed: D1.C, D4.A, L1.2, U4.2 (D), U4.4 (D)
unnamed: C3.1, D6.C, R2.2
unnamed: R4.1, U$1.P$1 (1)
unnamed: R3.1, R4.2
unnamed: C4.1, R2.1, R3.2
unnamed: C1.+, IC1.2- (2-5V-IN), JMP1.2, JMP1.3, JP1.1, L1.1
unnamed: D4.C, D6.A
unnamed: IC1.16_ (16_IO5/ADC1-4), PIEZO_GR.P$2, PIEZO_KL.P$2
unnamed: IC1.15_ (15_IO4/ADC1-3), PIEZO_GR.P$1, PIEZO_KL.P$1
SCL: I2C.3, IC1.13- (13-IO47)
SDA: I2C.4, IC1.14- (14-IO48)

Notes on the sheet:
Hier Zählrohr dazwischen OBEN ist PLUS
optional

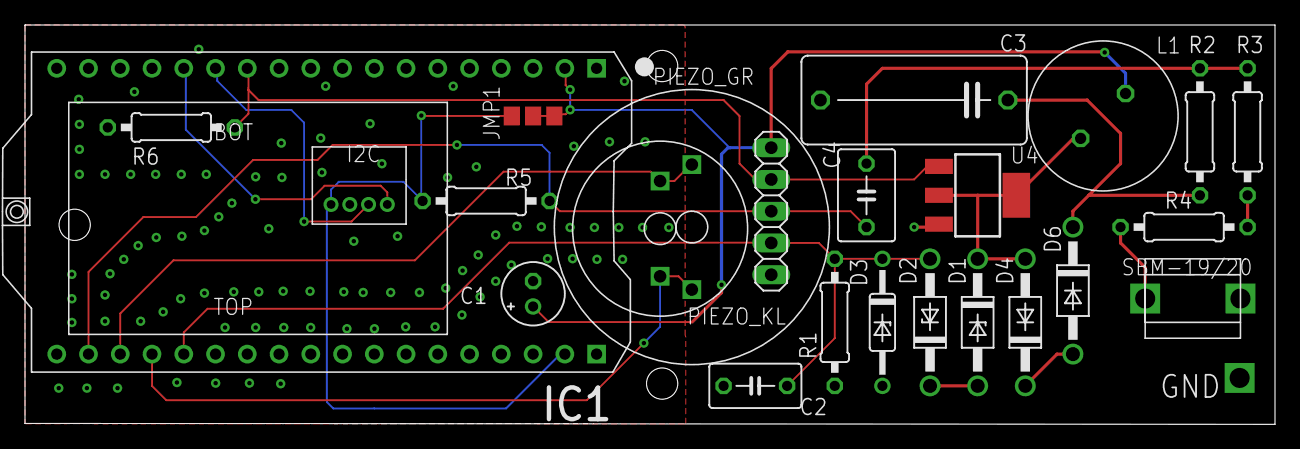
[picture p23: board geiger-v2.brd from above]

Board: 2 copper layers, 100.0 x 31.9 mm, 25 parts (0 on the bottom side), 17 nets.

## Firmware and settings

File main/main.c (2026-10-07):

#include <string.h>
#include <stdio.h>
#include <inttypes.h>   // PRIu32/PRIu64 for counter format macros
#include <time.h>
#include "freertos/FreeRTOS.h"
#include "freertos/task.h"
#include "freertos/event_groups.h"
#include "esp_chip_info.h"
#include "esp_event.h"
#include "esp_flash.h"
#include "esp_log.h"
#include "esp_mac.h"
#include "esp_netif.h"
#include "esp_system.h"
#include "esp_timer.h"
#include "esp_wifi.h"
#include "nvs_flash.h"
#include "driver/gpio.h"

#include "als.h"
#include "veml7700.h"
#include "fuel_gauge.h"   // V2.6.6: MAX17048 battery fuel gauge (FeatherS3-D)
#include "gnss.h"               // V2.5.8: I²C GNSS (PA1010D / MAX-M10S)
#include "applog.h"
#include "coredump.h"
#include "hal.h"
#include "env_sensor.h"
#include "i2c_bus.h"            // V2.3.29: bus lifecycle (replaces env_sensor_get_i2c_bus)
#include "pm_sensor.h"
#include "noise_sensor.h"
#include "sgp41.h"
#include "config.h"
#include "diag.h"               // V2.4.28: I²C sensor-read-error counter
#include "display.h"
#include "http_server.h"
#include "log_ftp.h"
#include "lorawan.h"            // V2.6.23: SX1262 LoRaWAN uplink (Heltec V4-R2 only)
#include "main_status.h"
#include "mqtt.h"
#include "neopixel.h"
#include "led.h"
#include "net_arp.h"            // V2.4.19: gratuitous ARP after WiFi reconnect
#include "ntp.h"
#include "sysinfo.h"   // chip_model_str (shared model-string ladder)
#include "periodic.h"           // V2.4.19: 24h housekeeping (PSA refresh + safety-net ARP)
#include "history.h"            // V2.5.6: in-RAM CPM history + rolling averages
#include "sd_card.h"            // V2.6.19: standalone mode — microSD FAT32 mount
#include "sd_logger.h"          // V2.6.19: standalone mode — per-cycle CSV logger
#include "speaker.h"
#include "syslog.h"
#include "telemetry.h"          // V2.6.19: standalone mode — neutral column registry
#include "tls_cert.h"          // V2.8.0: per-device HTTPS credential (PSRAM boards)
#include "transmission.h"
#include "tube.h"
#include "tube_logic.h"   // V2.6.31: pcnt_blank_wide (width-aware blank subtract)
#include "tube_pcnt.h"   // V2.5.16: PCNT pulse-width comb (V2.7.4: always on)
#include "util.h"
#include "version.h"

static const char *TAG = "v2_main";

// Runtime configuration — loaded from NVS at boot with compile-time defaults
// as fallback (see config.c). Editable via the /config endpoint.
// V2.6.23: no longer `static` — lorawan.cpp reads this by the `extern
// config_t g_cfg;` declaration in config.h (see that comment for why; every
// other module instead gets a pointer/values handed to it explicitly).
config_t g_cfg;

// Hardware-derived identity, always populated at boot from the factory MAC.
// Never stored in NVS; never user-editable. g_chip_id is the canonical
// "esp32-<decimal>" string used as X-Sensor header and default AP SSID.
// g_chip_num is just the decimal portion, used to build the default
// "MultiGeiger-<decimal>" DHCP hostname.
static char      g_chip_id[20];
static uint32_t  g_chip_num;

static EventGroupHandle_t s_events;
#define EV_GOT_IP       BIT0
#define EV_DISCONNECTED BIT1
// V2.4.1 (A9): bit set by main_request_restart() to wake the main loop
// from xEventGroupWaitBits — drops restart latency from up to 1 s
// (the previous polled-flag pattern bounded by the loop's wait cap) to
// the FreeRTOS context-switch time (~µs). Persistent state lives in
// g_restart_requested below since the event bit is consumed by the
// xClearOnExit=pdTRUE wait — see main loop policy.
#define EV_RESTART      BIT2
static volatile bool g_restart_requested = false;

void main_request_restart(void) {
    g_restart_requested = true;
    xEventGroupSetBits(s_events, EV_RESTART);
}

// V2.4.17: sticky flag set by the OTA POST teardown path. When true, the
// main-loop poll skips MQTT and syslog re-init — without this the poll
// re-inits both within ~1 s of mqtt_stop()/syslog_stop(), undoing the
// V2.4.13 OTA teardown during the bulk of the OTA receive loop.
// V2.4.14's FTPS teardown deliberately does NOT set this — that path
// wants MQTT to auto-restart after the upload completes.
static volatile bool g_services_suspended = false;

void main_suspend_services(void) {
    g_services_suspended = true;
}

bool main_services_suspended(void) {
    return g_services_suspended;
}

// V2.4.24: OTA-in-progress flag. Non-sticky (unlike g_services_suspended).
// Set on entry to update_post, cleared on every return path. Read by the
// main loop's TX-cycle scheduler to skip do_tx_cycle while an OTA upload
// is consuming the WiFi link.
static volatile bool g_ota_in_progress = false;

void main_ota_begin(void) {
    g_ota_in_progress = true;
}

void main_ota_end(void) {
    g_ota_in_progress = false;
}

bool main_ota_in_progress(void) {
    return g_ota_in_progress;
}

// --- Soak diagnostics (carried over) ---
// t_attempt_start_us is written by mark_attempt() from BOTH the main task
// (retry/roaming-safety-net paths) and the WiFi event task (STA_START), then
// read back on the event task in on_wifi_event to compute last_assoc_s — a
// genuine cross-task int64_t (two-instruction store on 32-bit Xtensa, torn-
// read hazard). Guarded with its own spinlock rather than demoted to 32-bit
// (as n_attempts/sync_tv_sec were) because the consumer needs sub-second
// precision; follows the g_last_cycle_at_mux precedent below.
static int64_t  t_attempt_start_us = 0;
static portMUX_TYPE t_attempt_start_mux = portMUX_INITIALIZER_UNLOCKED;
// t_sta_connected_us: written and read only within on_wifi_event/on_ip_event,
// both on the single default-event-loop task — never touched by the main
// task, so no cross-task hazard and no lock needed.
static int64_t  t_sta_connected_us = 0;
// uint32_t — written on the WiFi event task, read on the main task; on 32-bit
// Xtensa a uint64_t store is two instructions (torn-read hazard). Wraps after
// 4.3 billion events (~136 years at 1/s) — sufficient for display use.
static uint32_t n_attempts = 0, n_connects = 0, n_got_ip = 0;
// uint32_t — written on the WiFi event task, read on the TX task; on 32-bit
// Xtensa a uint64_t store is two instructions (torn-read hazard). Wraps after
// 4.3 billion disconnects (~136 years at 1/s) — sufficient for display use.
static uint32_t n_disconnects = 0;
static uint32_t last_disconnect_reason = 0;
static float    last_dhcp_s = 0.0f, last_assoc_s = 0.0f;

// V2.4.19: set in the main loop when EV_GOT_IP fires; cleared after the
// post-reconnect gratuitous ARP is actually sent. Decoupled from the
// event so we can defer the ARP send to a tick when tx_is_idle() — see
// the bottom of the main loop for the consumer and the rationale.
static bool s_arp_after_reconnect_pending = false;

// V2.6.19 (final review A2): boot-time latch of the two standalone-SD
// checkboxes. /config's plain "Save" commits g_cfg live (only "Save and
// restart" reboots), but g_cfg.standalone_sd/standalone_ap_on are BOTH
// starred reboot-required in the UI — the mode's arming (sd_logger_init(),
// gnss_set_clock_source(), the boot SD mount) only ever runs once, at boot.
// Reading g_cfg.standalone_sd live in do_tx_cycle()/the radio-off branch let
// a plain Save on a running networked node kill the radio (esp_wifi_stop+
// deinit fires within ~1 s) while the GPS clock source was never armed, so
// sd_logger_cycle() waits at its clock-sync gate forever: radio dead, zero
// rows ever logged, until a physical power-cycle. Latching both flags here
// and using ONLY the latch below (never g_cfg.standalone_sd/standalone_ap_on
// directly) makes a live Save a pure no-op until reboot, matching the
// starred-field contract the /config result page already promises.
//
// V2.6.23: s_standalone_ap_on_latched is now honored in ALL modes, not just
// alongside standalone-SD (was: the AP-window-close branch only consulted
// it when s_standalone_sd_latched was also true, so a networked node with
// STA creds could never keep the AP up). See the AP-window-close block
// below — this latch now short-circuits both the standalone-SD radio-off
// branch AND the switch-to-STA branch, so any node (SD-standalone,
// LoRaWAN-standalone, or a plain networked node the user wants permanently
// reachable at 192.168.4.1) can hold the AP forever.
static bool s_standalone_sd_latched    = false;
static bool s_standalone_ap_on_latched = false;

// --- NTP/TX state ---
static bool     ntp_started = false;
// V2.4.13: mqtt-init tracking moved into mqtt.c (mqtt_is_initialized()).
// The old static `mqtt_started` flag here was opaque to mqtt_stop(), so the
// OTA teardown path couldn't signal "please re-init MQTT on next tick" — by
// pulling the source of truth into mqtt.c, mqtt_stop() can flip it directly
// and main.c's poll re-arms within ~1 s on a failed OTA.
static uint32_t tx_cycles   = 0;

// --- Cached last-cycle snapshot (for the status page) ---
//
// All fields written ONLY by the main task in do_tx_cycle() (single writer);
// read lock-free by the HTTP server task. 32-bit scalar fields are
// word-aligned and torn-tolerant on Xtensa LX6/LX7 — no lock needed.
// A momentary inconsistency between cpm/usvph and bme_t/h/p is acceptable
// — they're for at-a-glance status, not for accounting.
//
// V2.4.1 (B1): the 64-bit `g_last_cycle_at` IS NOT torn-tolerant on a
// 32-bit core. A naive int64_t store is two 32-bit stores; a reader on
// another task could see the high half of one write and the low half of
// the next (manifest: momentary year-2038-ish garbage timestamp on the
// status page for a few µs around each TX cycle). Protected by a
// dedicated spinlock for the read/write pair below. The other scalars
// don't need the lock — keeping them out preserves the existing zero-
// cost reads on the hot status-page path.
static uint32_t g_last_dt_ms      = 0;
static uint32_t g_last_cpm        = 0;
static float    g_last_usvph      = 0.0f;
// V2.5.16: PCNT width-filter state for /status — whether the last cycle's CPM
// was width-filtered, the pre-filter CPM, and the active filter width.
static bool     g_last_filtering    = false;
static uint32_t g_last_cpm_raw      = 0;
static uint32_t g_last_filter_width_ns = 0;
static uint32_t g_last_hv_pulses        = 0;   // cumulative since boot (MQTT)
static uint32_t g_last_hv_pulses_delta  = 0;   // V2.4.27: per-cycle delta (status + legacy HTTPS)
static bool     g_last_hv_error   = false;
static bool     g_last_bme_valid  = false;   // OR of the three below
static bool     g_last_bme_t_valid = false;   // V2.4.12
static bool     g_last_bme_h_valid = false;   // V2.4.12
static bool     g_last_bme_p_valid = false;   // V2.4.12
static float    g_last_bme_t      = 0.0f;
static float    g_last_bme_h      = 0.0f;
static float    g_last_bme_p      = 0.0f;
static int64_t  g_last_cycle_at   = 0;     // wall-clock unix epoch (0 = never)
static uint32_t g_last_cycle_ms   = 0;     // monotonic uptime ms (0 = never)
static portMUX_TYPE g_last_cycle_at_mux = portMUX_INITIALIZER_UNLOCKED;

// Public snapshot getter — V2.4.1 (A4): replaces 13 individual extern
// functions previously hand-declared at the top of http_server.c and
// display.c. Reader gets every field in one call; the int64_t
// `last_cycle_at` is read under the spinlock to pair with the write in
// `do_tx_cycle` (B1 atomic fix). 32-bit fields are word-aligned and
// torn-tolerant on Xtensa, so they don't take a lock — the snapshot is
// not inter-field consistent (e.g. cpm could be from cycle N and env_t
// from cycle N+1) but each scalar is individually intact.
void main_status_snapshot(main_status_t *out) {
    out->cycles         = tx_cycles;
    out->last_dt_ms     = g_last_dt_ms;
    out->last_cpm       = g_last_cpm;
    out->last_usvph     = g_last_usvph;
    out->last_hv_pulses       = g_last_hv_pulses;
    out->last_hv_pulses_delta = g_last_hv_pulses_delta;
    out->last_hv_error  = g_last_hv_error;
    out->have_env       = g_last_bme_valid;
    out->have_env_t     = g_last_bme_t_valid;
    out->have_env_h     = g_last_bme_h_valid;
    out->have_env_p     = g_last_bme_p_valid;
    out->env_t          = g_last_bme_t;
    out->env_h          = g_last_bme_h;
    out->env_p          = g_last_bme_p;
    portENTER_CRITICAL(&g_last_cycle_at_mux);
    out->last_cycle_at  = g_last_cycle_at;
    portEXIT_CRITICAL(&g_last_cycle_at_mux);
    out->last_cycle_ms  = g_last_cycle_ms;
    out->reconnects     = (uint32_t)n_disconnects;   // truncating cast — see counter decl
    out->i2c_errors     = diag_i2c_errors();         // V2.4.28
    out->pcnt_filtering = g_last_filtering;          // V2.5.16
    out->last_cpm_raw   = g_last_cpm_raw;
    out->pcnt_filter_width_ns = g_last_filter_width_ns;
}
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
void app_main(void) {
    // Install vprintf hook first so the very first ESP_LOGx below (and
    // everything after — WiFi, HTTP, sensors, TX) lands in the /log buffer.
    applog_init();

    ESP_LOGI(TAG, "%s (IDF %s)", VERSION_STR, esp_get_idf_version());
    // V2.3.16-pre2: explicit board variant in serial log so the variant is
    // unambiguous from the very first line without having to grep cipher/
    // partition lines further down. BOARD_NAME comes from hal.h
    // (one of "heltec_v2", "heltec_v2_4mb", "feathers3_d").
    ESP_LOGI(TAG, "BOARD: %s", BOARD_NAME);

    // V2.4.18: probe the coredump partition. Logs whether a previous
    // panic left a dump and parses the summary for cheap status-page
    // reads. Runs BEFORE WiFi/HTTP/sensors so the boot log line lands
    // in /log + syslog (once syslog is up later) regardless of how the
    // operator inspects the device.
    coredump_init();

    esp_err_t ret = nvs_flash_init();
    if (ret == ESP_ERR_NVS_NO_FREE_PAGES || ret == ESP_ERR_NVS_NEW_VERSION_FOUND) {
        ESP_ERROR_CHECK(nvs_flash_erase());
        ret = nvs_flash_init();
    }
    ESP_ERROR_CHECK(ret);

    config_load(&g_cfg);

    // V2.6.21: apply TZ before anything logs or timestamps a file — standalone
    // boards never reach ntp_setup() (no STA, so no GOT_IP), so without this
    // they never got past the UTC default despite tz_posix being configured.
    // Harmless on networked boards too: ntp_setup() re-applies the same value
    // once GOT_IP fires.
    ntp_set_timezone(g_cfg.tz_posix);

    // Chip ID is always derived from the factory MAC — never user-edited,
    // never stored in NVS. Format: "esp32-<decimal>" where <decimal> is the
    // last 3 MAC bytes packed as (byte5 = LSB, byte3 = MSB).
    {
        uint8_t m[6];
        esp_read_mac(m, ESP_MAC_WIFI_STA);
        g_chip_num = ((uint32_t)m[5]) | ((uint32_t)m[4] << 8) | ((uint32_t)m[3] << 16);
        snprintf(g_chip_id, sizeof(g_chip_id), "esp32-%lu", (unsigned long)g_chip_num);
        ESP_LOGI(TAG, "chip_id: %s (from MAC %02x:%02x:%02x:%02x:%02x:%02x)",
                 g_chip_id, m[0], m[1], m[2], m[3], m[4], m[5]);
    }

    // Chip / module identification — distinguishes silicon between board variants.
    // For Heltec WiFi Kit 32 V2: chip.model == ESP32, EmbFlash NO, 8 MB flash
    // (D0WDQ6 + separate flash chip). For UM FeatherS3-D: chip.model == ESP32-S3,
    // EmbFlash YES, EmbPSRAM YES, 16 MB flash. Other combinations indicate either
    // a wrong-board flash or an unknown variant — log loudly and continue.
    {
        esp_chip_info_t chip;
        esp_chip_info(&chip);
        uint32_t flash_size = 0;
        esp_flash_get_size(NULL, &flash_size);
        const char *model = chip_model_str(chip.model);
        ESP_LOGI(TAG, "chip: %s rev=v%d.%d cores=%d feat=[%s%s%s%s%s] flash=%luMB",
                 model,
                 chip.revision / 100, chip.revision % 100,
                 chip.cores,
                 (chip.features & CHIP_FEATURE_WIFI_BGN) ? "WiFi "     : "",
                 (chip.features & CHIP_FEATURE_BLE)      ? "BLE "      : "",
                 (chip.features & CHIP_FEATURE_BT)       ? "BT "       : "",
                 (chip.features & CHIP_FEATURE_EMB_FLASH)? "EmbFlash " : "",
                 (chip.features & CHIP_FEATURE_EMB_PSRAM)? "EmbPSRAM " : "",
                 (unsigned long)(flash_size / (1024 * 1024)));
    }

    // Fill auto defaults for ap_name + wifi_hostname if the user hasn't
    // chosen their own. These are stored as-is once the user saves the
    // config, so subsequent boots keep the user's values.
    if (g_cfg.ap_name[0] == 0) {
        snprintf(g_cfg.ap_name, sizeof(g_cfg.ap_name), "%s", g_chip_id);
    }
    if (g_cfg.wifi_hostname[0] == 0) {
        snprintf(g_cfg.wifi_hostname, sizeof(g_cfg.wifi_hostname),
                 "MultiGeiger%lu", (unsigned long)g_chip_num);
    }
    ESP_LOGI(TAG, "ap_name: '%s'  wifi_hostname: '%s'",
             g_cfg.ap_name, g_cfg.wifi_hostname);

    // V2.3.29: dual-bus device probing.
    //
    // i2c_bus.c owns both buses (primary always-on, secondary lazy +
    // sheddable). For each sensor module we try the primary bus first;
    // if no device was found, we ask for the secondary bus (which
    // lazily enables LDO2 on FeatherS3-D, returns NULL on Heltec / QT Py)
    // and probe again. On a hit, mark the secondary bus as kept-alive
    // so i2c_bus_finalize() below doesn't tear it down.
    //
    // Display does its own dual-bus auto-detect inside display_setup()
    // (and calls i2c_bus_secondary_keep_alive() itself if it lands on
    // the secondary). After all init, i2c_bus_finalize() drops LDO2 if
    // nothing — sensor or display — ended up on STEMMA2.
    //
    // Heltec WiFi LoRa 32 V4-R2 is the one exception: its secondary bus is
    // permanently and exclusively the onboard OLED, never a general-purpose
    // STEMMA-style connector — see PROBE_ON_BOTH_BUSES below, which skips
    // the secondary-bus fallback entirely on this board.
    //
    // V2.5.19: select the primary-bus pin route from config BEFORE the first
    // i2c_bus_get_primary() below caches the bus. No-op except on QT Py
    // (HAL_HAS_I2C_PINOUT_SWITCH); reboot-required by construction.
    i2c_bus_set_primary_pinout(g_cfg.i2c_pinout);
    i2c_master_bus_handle_t bus1 = i2c_bus_get_primary();

    // V2.6.6: MAX17048 fuel gauge is a fixed onboard part on STEMMA1/
    // primary — unlike the pluggable env/PM/noise sensors below, it never
    // needs the secondary-bus fallback probe.
    fuel_gauge_init(bus1);
    // V2.6.6: seed the user-confirmed battery-presence flag from config —
    // see fuel_gauge.h for why this can't be auto-detected via VCELL.
    // Live-reapplied on every /config Save in http_server.c::config_post.
    fuel_gauge_set_user_present(g_cfg.batt_present);

    // Helper macro: try a sensor's init on bus 1; if no device bound,
    // try bus 2; if a device was found there, keep the bus alive.
    //
    // Heltec WiFi LoRa 32 V4-R2: the secondary bus is the onboard OLED,
    // never a pluggable sensor connector, so the fallback probe is
    // compiled out entirely for this board — it would otherwise probe the
    // display's bus on every sensor driver, every boot, for no reason.
#if defined(BOARD_HELTEC_WIFI_LORA32_V4_R2)
    #define PROBE_ON_BOTH_BUSES(init_fn, present_fn, bus1)                  \
        do {                                                                \
            init_fn(bus1);                                                  \
        } while (0)
#else
    #define PROBE_ON_BOTH_BUSES(init_fn, present_fn, bus1)                  \
        do {                                                                \
            init_fn(bus1);                                                  \
            if (!present_fn()) {                                            \
                i2c_master_bus_handle_t _b2 = i2c_bus_get_secondary();      \
                if (_b2) {                                                  \
                    init_fn(_b2);                                           \
                    if (present_fn()) i2c_bus_secondary_keep_alive();       \
                }                                                           \
            }                                                               \
        } while (0)
#endif

    PROBE_ON_BOTH_BUSES(env_sensor_init,   env_sensor_present,   bus1);
    PROBE_ON_BOTH_BUSES(pm_sensor_init,    pm_sensor_present,    bus1);
    PROBE_ON_BOTH_BUSES(noise_sensor_init, noise_sensor_present, bus1);
    // V2.6.15: SGP41 VOC+NOx sensor — probed after env_sensor_init so its
    // background sampling task (started inside sgp41_init on a hit) can
    // find SHT45 already bound for RH/T compensation reads.
    PROBE_ON_BOTH_BUSES(sgp41_init,        sgp41_present,        bus1);

    // V2.5.10: GNSS vs ambient-light auto-detect (no config toggle). The
    // PA1010D GNSS breakout sits at I²C 0x10 — the SAME address as the
    // VEML7700 — so they can't coexist on a bus. gnss_init() resolves this by
    // sniffing for live NMEA at 0x10 (and binding u-blox 0x42 unambiguously);
    // a VEML7700 fails the sniff, so we fall through to the light-sensor probe
    // only when no GNSS was found. Whichever module is physically present just
    // works — nothing to configure.
    PROBE_ON_BOTH_BUSES(gnss_init, gnss_present, bus1);
    if (!gnss_present()) {
        PROBE_ON_BOTH_BUSES(veml7700_init, veml7700_present, bus1);
    }

    #undef PROBE_ON_BOTH_BUSES

    // V2.3.29: ALS-PT19 ambient-light sensor (FeatherS3-D only — analog,
    // ADC1_CH3 on GPIO 4). On other boards als_init() is a no-op stub.
    als_init();
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

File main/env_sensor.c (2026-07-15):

#include "env_sensor.h"

#include "esp_log.h"

#include "sht45.h"
#include "bmp581.h"
#include "bmp390.h"
#include "bme688.h"
#include "bme280.h"

static const char *TAG = "env";

// V2.3.29: bus ownership moved to i2c_bus.c. This module is now a pure
// consumer — env_sensor_init(bus) accepts a bus handle and runs the
// cascade probe on it. Vext gating (Heltec) and LDO2 enable (FeatherS3-D
// STEMMA2) are i2c_bus.c's job — by the time we're called, the bus is
// already powered up and ready to ACK.

// --- Init --------------------------------------------------------------------

esp_err_t env_sensor_init(i2c_master_bus_handle_t bus) {
    if (!bus) return ESP_ERR_INVALID_ARG;

    // BMP390, BME688 and BME280 all use I2C addresses 0x76/0x77 — only ONE of
    // the three can physically be on the bus at a time. We probe in priority
    // order (highest accuracy first): BMP581 (6th-gen Bosch, 0x46/0x47 —
    // independent of the 0x77 family, so it can coexist with any of them) →
    // BMP390 (dedicated barometer, fixed 0x77 on the Adafruit breakout) →
    // BME688 (newer Bosch T/P/H, gas off) → BME280 (legacy fallback). Each
    // later probe in the 0x77 family skips its address if a prior driver
    // claimed it, defending against an accidental dual-population on different
    // addresses (e.g. one chip jumpered to 0x76). Chip-ID is also verified
    // inside each driver — but BMP390 and BME280 both report 0x60, so chip-ID
    // alone is not enough; the address-skip ordering is the real defence.
    //
    // V2.3.29: each sub-driver's init is idempotent (returns early if its
    // device is already bound). main.c may re-call env_sensor_init() with a
    // different bus if the first call found nothing — sub-drivers re-probe
    // cleanly on the new bus.

    sht45_init(bus);   // 0x44 — separate I2C address, no conflict possible

    bool bmp581_ok = (bmp581_init(bus) == ESP_OK);  // 0x46/0x47 — independent of 0x77 family
    (void)bmp581_ok;
    bool bmp390_ok = (bmp390_init(bus) == ESP_OK);
    bool bme688_ok = (bme688_init(bus, bmp390_ok) == ESP_OK);
    bool bme_addr_77_busy = bmp390_ok || bme688_ok;
    bme280_init(bus, bme_addr_77_busy);

    ESP_LOGI(TAG, "env sensor: %s", env_sensor_name());
    return ESP_OK;
}

// --- Public API --------------------------------------------------------------

bool env_sensor_present(void) {
    return sht45_present() || bmp581_present() || bmp390_present() ||
           bme688_present() || bme280_present();
}

// V2.4.12: per-field driver-presence helpers. Match the union of chips
// in env_sensor_read's cascade that can produce each measurement.
bool env_t_present(void) {
    return sht45_present() || bmp581_present() || bmp390_present() ||
           bme688_present() || bme280_present();
}

bool env_h_present(void) {
    return sht45_present() || bme688_present() || bme280_present();
}

bool env_p_present(void) {
    return bmp581_present() || bmp390_present() ||
           bme688_present() || bme280_present();
}

esp_err_t env_sensor_read(float *temperature_c, float *humidity_pct,
                          float *pressure_pa,
                          bool *out_have_t, bool *out_have_h, bool *out_have_p,
                          char *raw_log, size_t raw_log_cap) {
    float t = 0, h = 0, p = 0;
    bool  have_t = false, have_h = false, have_p = false;

    // V2.3.26: optional per-sensor raw-reading log. Each present sensor that
    // gets called appends one segment (its own T/H/P, or "read failed"). The
    // caller logs this alongside the fused result, so the source of any single
    // field is visible — essential for diagnosing flaky sensors that fail
    // silently and let the cascade fall through to a fallback chip (the H=0.00%
    // problem on esp32-176432, May 2026). NULL buffer disables the log build.
    size_t rl_off = 0;
    if (raw_log && raw_log_cap > 0) raw_log[0] = '\0';
    #define RL(...) do { \
        if (raw_log && raw_log_cap > rl_off + 1) { \
            int _n = snprintf(raw_log + rl_off, raw_log_cap - rl_off, __VA_ARGS__); \
            if (_n > 0) rl_off += (size_t)_n; \
        } \
    } while (0)

    // Temperature + humidity: SHT45 is primary (best accuracy and lowest
    // self-heating of all our T/H options).
    if (sht45_present()) {
        float st, sh;
        if (sht45_read(&st, &sh) == ESP_OK) {
            t = st; h = sh;
            have_t = have_h = true;
            RL("SHT45: T=%.2f°C  H=%.2f%%, ", st, sh);
        } else {
            RL("SHT45: read failed, ");
        }
    }

    // Pressure (and temperature fallback): BMP581 is the highest-priority
    // pressure source — 6th-gen Bosch barometer with factory-trimmed digital
    // output, ±0.4 Pa relative accuracy, 0.21 PaRMS noise at our OSR setting.
    // Lives at 0x46/0x47 so it can coexist with any 0x77-family chip.
    if (bmp581_present()) {
        float bt, bp;
        if (bmp581_read(&bt, &bp) == ESP_OK) {
            p = bp;
            have_p = true;
            if (!have_t) { t = bt; have_t = true; }
            RL("BMP581: T=%.2f°C P=%.2fhPa, ", bt, bp / 100.0f);
        } else {
            RL("BMP581: read failed, ");
        }
    }

    // BMP390 — second-priority pressure source, used when BMP581 isn't
    // populated. Dedicated barometric chip (no humidity), 0x77 on the
    // Adafruit breakout.
    if (bmp390_present() && !have_p) {
        float bt, bp;
        if (bmp390_read(&bt, &bp) == ESP_OK) {
            p = bp;
            have_p = true;
            if (!have_t) { t = bt; have_t = true; }
            RL("BMP390: T=%.2f°C P=%.2fhPa, ", bt, bp / 100.0f);
        } else {
            RL("BMP390: read failed, ");
        }
    }

    // BME688 — third-priority T/P/H source, only present when neither BMP581
    // (different address) nor BMP390 (same address) claimed the slot. Fills
    // any remaining gap.
    if (bme688_present() && (!have_t || !have_h || !have_p)) {
        float bt, bh, bp;
        if (bme688_read(&bt, &bh, &bp) == ESP_OK) {
            if (!have_t) { t = bt; have_t = true; }
            if (!have_h) { h = bh; have_h = true; }
            if (!have_p) { p = bp; have_p = true; }
            RL("BME688: T=%.2f°C  H=%.2f%% P=%.2fhPa, ", bt, bh, bp / 100.0f);
        } else {
            RL("BME688: read failed, ");
        }
    }

    // BME280 — legacy fallback, only present when BMP390 and BME688 aren't
    // (all three share I2C 0x77).
    if (bme280_present() && (!have_t || !have_h || !have_p)) {
        float bt, bh, bp;
        if (bme280_read(&bt, &bh, &bp) == ESP_OK) {
            if (!have_t) { t = bt; have_t = true; }
            if (!have_h) { h = bh; have_h = true; }
            if (!have_p) { p = bp; have_p = true; }
            RL("BME280: T=%.2f°C  H=%.2f%% P=%.2fhPa, ", bt, bh, bp / 100.0f);
        } else {
            RL("BME280: read failed, ");
        }
    }
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

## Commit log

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2026-04-23 V2.1.14: circuit breaker fix, WiFi power save config, favicon, max_alloc on homepage
    - Fix circuit breaker: only count rc==-1 (all retries exhausted) toward the
    fail streak. Previously any non-success (incl. 4xx like 403) incremented the
    streak, causing the breaker to trip on server rejections that have no retry
    overhead and need no protection. Applies to Madavi, sensor.community, Radmon.
    - Add WiFi power save config: new "Disable WiFi power save" checkbox in /config
    WiFi section. When unticked (default) uses WIFI_PS_MIN_MODEM, matching
    upstream MultiGeiger behaviour. When ticked uses WIFI_PS_NONE. Persisted in
    NVS. Allows per-device testing of power save effect on mesh re-keying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
    [config.c, http_server.c, main.c]
2026-04-23 V2.1.15: SHT45 + BMP390 sensor integration
    Adds native IDF drivers for SHT45 (temp+humidity) and BMP390
    (pressure+temp). New env_sensor facade probes in priority order —
    SHT45 → BMP390 → BME280 — and merges the best available readings
    (T: SHT45>BMP390>BME280, RH: SHT45>BME280, P: BMP390>BME280).
    BME280 remains the fallback and skips 0x77 when BMP390 is detected
    there. I2C bus ownership moves from bme280.c to env_sensor.c.
    [bme280.c, bmp390.c, display.c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]
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2026-04-25 V2.1.17: per-FTP PS-disable checkbox, log polish, NVS dump on boot
    FTP PS override (V2.1.16) is now a tickbox in the /config FTP section,
    default off. Linked to the global "Disable WiFi power save" box: when
    the global is ticked, the per-FTP box is greyed out and force-cleared
    in the UI; server-side preserves the saved NVS value across the
    round-trip so toggling the global doesn't silently wipe it.
    Useful only on the legacy sensor where DTIM-delayed TCP ACKs stall
    FTPS uploads (older WiFi RX hardware). New boards leave it off.
    Logging cleanups:
    - HTTP auth-FAILED warning now includes the peer IP, matching the
    access-log format. Common peer_ipstr() helper.
    - Right-arrow Unicode removed fr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
    [applog.c, config.c, http_server.c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]
2026-04-26 V2.1.18: BME688 driver, log polish, partitions.csv refresh
    - BME688/BME680 native ESP-IDF driver (T/P/H, gas channel disabled, forced
    mode, chip-ID 0x61 verified). Slots into env_sensor probe order between
    BMP390 and BME280; only one of the three Bosch chips can physically be
    on the I2C bus (all share 0x76/0x77).
    - env_sensor: tightened probe-order comment to state explicitly that BMP390
    + BME688 + BME280 cannot coexist; removed impossible dual-Bosch entries
    from env_sensor_name() (BMP390+BME280, BMP390+BME688). SHT45 + one Bosch
    remains the only real fusion case.
    - Log consistency:
    * sensor.community line now reports 'thp' (was 'bme') to match Madavi.
    * 'auth FAILED' -> 'aut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
    [partitions.csv]
2026-04-26 V2.1.19: env sensors — consistent forced-mode + IIR-off architecture
    Aligned all four env-sensor drivers on a single architectural pattern after
    researching manufacturer best practice (Bosch BME280/BMP390/BME688 datasheets,
    Sensirion SHT4x datasheet, ESPHome defaults):
    - BME280: NORMAL mode + IIR coef 4 + t_sb=1s -> FORCED mode + IIR OFF.
    Adds 35 ms forced-mode wait per read (T x8 + P x4 + H x2 worst-case
    ~30.6 ms, datasheet 9.1). Eliminates the ~0.1 C self-heating bias on T/H
    that came from continuous internal sampling. Matches Bosch's "Weather
    monitoring" recipe (datasheet table 7) — though oversampling kept higher
    than Bosch's x1/x1/x1 for lower per-sample noise (we are mai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
    [bme280.c, bme688.c, bmp390.c]
2026-04-29 V2.1.20: per-channel oversampling tuned to manufacturer accuracy presets
    Followup to V2.1.19's forced-mode + IIR-off architecture cleanup. Now that
    oversampling does the per-read averaging exclusively (no IIR), tuning the
    per-channel oversampling to Bosch's "Indoor navigation" / "drone" presets
    (and the BME680 application note BST-BME680-AN014) gives measurable noise
    reduction where it actually matters.
    | Sensor | T (was -> now) | P (was -> now) | H (was -> now) |
    |--------|----------------|----------------|----------------|
    | BME280 | x8 -> x2 | x4 -> x16 | x2 -> x1 |
    | BMP390 | x2 -> x1 | x8 -> x32 | - |
    | BME688 | x8 -> x2 | x4 -> x16 |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
    [bme280.c, bme688.c, bmp390.c]
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2026-05-08 V2.3.0: tube optional — non-Geiger mode for PM-only deployments
    New tube_enabled config flag (default true) lets the firmware run as a
    non-Geiger node. When false:
    - tube_setup() skips ISR install and the HV gptimer; HV_FET is held LOW
    so the boost MOSFET stays off and no recharge cycles run.
    - tube_read() returns zeros (counts / CPM / HV / min_us / max_us); dt_ms
    still ticks the wall-clock window for downstream sensors.
    - Madavi geiger POST skipped; THP POST still runs if env sensor present.
    - sensor.community X-PIN 19 (radiation) skipped; X-PIN 11 (THP) still runs.
    - Radmon skipped entirely (radiation-only target).
    - CYCLE log line collapses to dt + rssi; OLED CPM/dose lines show 0.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
    [config.c, http_server.c, main.c]
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2026-05-08 V2.3.6: BMP581 driver added to env_sensor probe chain
    - Hand-rolled pure-IDF driver (~150 LOC) parallel to bmp390.c. Probes
    I2C 0x46 (Adafruit #6407 default) then 0x47 (SparkFun default) and
    binds to whichever responds. Verifies chip ID 0x50; rejects 0x51
    (BMP585, a different Bosch product) with a wrong-part warning.
    - Operating profile: pressure x16 oversampling, temperature x1, IIR
    BYPASS, FORCED mode. Matches Bosch's Table 9 "high resolution" preset
    and ESPHome's documented default. Wait time after FORCED trigger is
    12 ms (ESPHome's ceil(1.05 * (tconv_p + tconv_t)) at 16x/1x).
    - BMP581 is highest-priority pressure source in env_sensor_read().
    Lives at 0x46/0x47 so it can c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
    [bmp581.c, env_sensor.c]
2026-05-08 V2.3.7: DNMS noise sensor (LAeq/min/max) added to env_sensor chain
    - New main/dnms.[ch] (~200 LOC) -- pure-IDF I2C driver for hbitter's
    Digital Noise Measuring Sensor (Nettigo NAM DNMS Kit, pre-flashed
    Teensy 4.0 + ICS-43434 mic). Auto-detects at 0x55. Sensirion-style
    framing (16-bit BE commands, word + CRC8 reads, poly 0x31 init 0xFF
    -- same CRC convention as SPS30 / SHT45). Five commands: RESET,
    READ_VERSION, CALCULATE_LEQ, READ_DATA_READY, READ_LEQ. Verifies
    the Teensy version string starts with "DNMS" to catch wrong-part
    populates at 0x55 (some Adafruit STEMMA breakouts share that
    address). We never touch the Teensy firmware -- same arrangement
    as SPS30, the Nettigo kit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
    [dnms.c, main.c]
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2026-05-09 V2.3.12: BMP3xx + BMP5xx 10-sample priming after init
    Mirror of dusty-code's mh12 fix (2026-05-08, src/sensors/bmp3xx/bmp3xx.cpp
    and src/sensors/bmp5xx/bmp5xx.cpp). Bosch's BMP3xx and BMP5xx pressure
    sensors need their oversampling chain primed with throwaway samples after
    begin() -- the first reading post-init is consistently wrong (~40 hPa low
    for BMP3xx, similar settle behaviour for BMP5xx) until ~10 measurement
    cycles flush the OSR averaging chain. Bosch's own KB recommends discarding
    the first data point. A wall-clock delay() does NOT fix it; only actual
    measurement cycles flush the chain.
    Fix in main/bmp390.c::bmp390_init and main/bmp581.c::bmp581_init: after
    OSR/IIR/CONFIG writes, ma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
    [bmp390.c, bmp581.c]
2026-05-09 V2.3.13: OTA target-board chip-ID validation
    Before V2.3.13 the /update handler accepted any uploaded binary as
    long as its OTA write succeeded. If you flashed a heltec_v2 .bin onto
    a feathers3_d device (or vice versa), the ESP-IDF bootloader would
    catch the chip-ID mismatch on next boot and roll back automatically
    -- but the recovery was ugly: one wasted OTA cycle, a confusing
    reboot, and possible "did the OTA work?" doubt.
    V2.3.13 catches it BEFORE commit. After esp_ota_end() but before
    esp_ota_set_boot_partition(), http_server.c::update_post now:
    1. Reads the just-written partition's image header at offset 0 via
    esp_partition_read() -- this is where chip_id lives
    (esp_image_header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
    [http_server.c]
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2026-05-10 V2.3.15: TLS 1.3 NewSessionTicket fix + SPS30 SC body fix + PSA defensive infrastructure + 4MB-flash board variant
    Three independent bugs fixed plus belt-and-braces infrastructure for a fourth
    that's parked for V2.3.16:
    Bug A (FIXED) — Unhandled TLS 1.3 NewSessionTicket. Root cause of the
    V2.3.5-V2.3.9 "USER reject: -1" regression. mbedTLS 4.x raises -0x7B00
    (MBEDTLS_ERR_SSL_RECEIVED_NEW_SESSION_TICKET) from ssl_read as a control-flow
    signal — not an error — when a TLS 1.3 server sends the post-handshake ticket.
    Our io_recv1 didn't recognise it and surfaced as fatal. Fixed by treating
    -0x7B00 like WANT_READ (continue the loop). Also defensive handling in
    io_send_all. V2.3.10's TLS 1.2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
    [partitions_4mb.csv]
2026-05-10 V2.3.16: streaming FTPS upload + BMP390 cal fix + 4MB partition + UI/config polish
    Seven items shipping; one experiment tried and reverted.
    1) Streaming FTPS upload (zero-copy via applog_stream API)
    Replaces applog_snapshot's malloc-the-entire-ring pattern with a
    non-allocating iterator that returns segment pointers directly into ring
    memory. Body sent in 4 KB chunks straight from the ring; no body buffer
    malloc. Saves ~60 KB internal DRAM during the upload window on Heltec
    (which had crawled to min_free=276 bytes at full ring under V2.3.15) and
    ~1 MB PSRAM on FeatherS3-D. /log HTTP endpoint continues to use the
    contiguous applog_snapshot (Content-Length-friendly respon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
    [partitions_4mb.csv]
2026-05-10 V2.3.17: stream /log HTTP endpoint + min_free in TX heap log
    Two small but high-value patches on top of V2.3.16.
    1) /log HTTP endpoint converted to streaming
    Pre-V2.3.17 used applog_snapshot() which mallocs the entire 60 KB ring as
    one contiguous buffer. Replaced with the same applog_stream_begin/_end
    API V2.3.16 added for FTPS, plus chunked Transfer-Encoding via
    httpd_resp_send_chunk(). Body alloc drops from 60 KB to 0 KB.
    Why this mattered: V2.3.16 FTP_Investigation overnight log showed
    min_free dipping to 316 bytes on the Heltec — extremely close to OOM.
    Tracing the log revealed every browser hit on /log caused a 60 KB
    transient peak; combined with concurrent h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
    [http_server.c]
2026-05-10 V2.3.18: status page expansion + PSRAM ring 4MB + FTP log polish
    The / status page is now organised into labelled blocks: Device, Network,
    System, Cycle, Radiation, Environment, Noise, Particulate matter, Uploads.
    Surfaces previously log-only info (chip details, WiFi security/PHY/BSSID/AID,
    reset reason, NTP state, cycle counter+dt+next, per-target upload stats with
    breaker state, FTP last/next).
    Implementation: streamed via httpd_resp_send_chunk with a single 1600-byte
    shared stack buffer (V2.3.17 /log pattern). Zero per-request heap. Stack
    bounded ~2.7 KB / 8 KB. All sensor data read from caches populated by the
    worker — no I2C from HTTP context. Lock-free single-writer/multi-reader on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
    [applog.c, http_server.c, main.c]
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2026-05-11 V2.3.20: 4th board (Adafruit QT Py ESP32-PICO) + NeoPixel driver + HAL refactor
    Adds support for the Adafruit QT Py ESP32-PICO (PID 5395). Original ESP32
    LX6 SiP (NOT S3) — ESP32-PICO-V3-02 with in-package 8 MB flash + 2 MB
    PSRAM. 11 castellated GPIO pads + STEMMA QT connector + onboard NeoPixel.
    Pin budget on the QT Py is much tighter than the Feather form factor, so
    this board configuration drops OLED (already gone on PSRAM-class boards)
    AND piezo speaker. Geiger uses 3 pads: A0=IO26 (HV_CAP_FUL), A1=IO25
    (GMC_COUNT), A2=IO27 (HV_FET). Same function-per-A-position as feathers3_d
    so a Feather-style wiring harness drops onto the QT Py with only the GPIO
    numbers changing. Env sensor plugs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
    [applog.c, hal.h, http_server.c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]
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2026-05-11 V2.3.23: TLS 1.3 default ON for FTPS + 24h scheduled PSA refresh
    Two small changes closing out the V2.3.5 → V2.3.22 FTPS+TLS 1.3 arc and
    adding slow-fragmentation prevention.
    1. ftp_tls12_only default flipped from true to false.
    TLS 1.3 is now the FTPS default after V2.3.22's bidirectional-close
    fix landed and was production-validated against the project's LAN
    FTPS server (esp32-176432 -> esp32-12276328:48807, ~22 successful
    uploads observed across ~1 hour with no 426 events).
    The /config "Limit FTPS to TLS 1.2" checkbox stays as a safety net.
    Existing devices upgrading from V2.3.22 keep their saved value via
    NVS; only fresh / NVS-erased devices get the new default.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
    [config.c]
2026-05-12 V2.3.24: fix wrap-corruption in applog snapshot + config UX + status polish
    The V2.3.16 streaming snapshot had a wrap-specific pointer aliasing bug:
    seg_a started at the same memory address where the writer's next
    ring_append() landed, exposing seg_a's content to in-flight overwrite
    once the mutex was released. Manifested as torn lines at the head of
    every Heltec FTPS upload from file #2 onwards (PSRAM boards' giant
    ring barely wraps in production lifetime, so they were unaffected).
    Fix: applog_stream_begin copies the danger zone into a pre-allocated
    scratch buffer and exposes a third segment so callers stream
    copy + ring-tail-remainder + newer-pre-wrap-half. Per-board scratch
    sizing (hal.h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
    [applog.c, hal.h, http_server.c]
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2026-05-13 V2.3.26: env-sensor diagnostics — surface silent SHT45 failures
    Two changes, no behaviour change:
    1. sht45_read() now logs the two previously-silent error paths
    (CMD_MEASURE_HIGH write + post-measure i2c_master_receive) so a
    flaky SHT45 that ACKs at init then drops off the bus mid-life
    produces a diagnosable W line per cycle, mirroring the init
    path's try_init_pass() verbosity. Triggered by knock-off Heltec
    esp32-176432: H=0.00% every cycle with T tracking BMP390 →
    silent SHT45 read failure with cascade fall-through.
    2. env_sensor_read() gained an optional (char *raw_log, size_t cap)
    tail. main.c's cycle log line now reads:
    SHT45: T=18.86°C H=0.00%, BMP390: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
    [env_sensor.c, main.c]
2026-05-13 V2.3.27: FeatherS3-D pin map — HV_FET + speaker moved off A2..A4
    PCB harness rev frees the contiguous A2..A4 trio (only guaranteed ADC-capable
    trio on the Feather form factor) for future analog expansion:
    PIN_HV_FET_OUTPUT : A2 (IO14) -> A5 (IO5)
    PIN_SPEAKER_P : A3 (IO12) -> D10 (IO3) <- ESP32-S3 boot strap
    PIN_SPEAKER_N : A4 (IO6 ) -> D9 (IO1)
    IO3 is the ESP32-S3 JTAG-source strap (HIGH at boot = USB-Serial-JTAG to
    native USB; LOW = legacy JTAG via MTDI/MTDO/MTCK/MTMS). Safe with a piezo:
    the cap has no DC pull-down path, the internal pull-up holds IO3 HIGH at
    reset, the strap latches before speaker_setup() runs. hal.h comment flags
    the constraint for future developers.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
    [hal.h]
2026-05-15 V2.3.29: multi-page display + dual-bus auto-detect + brightness control + ALS + i2c_bus refactor
    Major V2 architectural cleanup plus four user-facing additions, all OTA-safe
    from V2.3.28 (skipped — V2.3.28 work consolidated into this release).
    Headline features:
    1. Multi-page display rotation (5 pages, 7 s each) on FeatherS3-D and QT
    Py — replaces the radiation-page on these boards. Same single binary
    auto-detects which display is fitted (SerLCD at 0x72 OR SSD1309/6 at
    0x3C) AND which I2C bus it lives on. Page set adapts to the sensors
    present (PM pages skip without SPS30, Uploads page hides disabled
    targets).
    2. Dual-bus auto-detect for both displays AND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
    [als.c, config.c, display.c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]
2026-05-15 V2.3.30: SHT45/SPS30 serial logging + Vishay VEML7700 ambient-light driver
    Small additive release on top of V2.3.29 — diagnostic-friendly serial-number
    logging for two sensors that have factory-burned unique IDs, plus a new I2C
    ambient-light sensor driver. No architectural changes, no removed APIs,
    OTA-safe from V2.3.29.
    Changes:
    1. SHT45 serial logged at init (sht45.c) — read via cmd 0x89, logged as
    8-char hex. Surfaced after a faulty Adafruit #6174 SHT45 (post-measure
    NACKs in steady state, init OK) needed identification across board
    swaps. Failure to read serial is non-fatal; chip otherwise works.
    2. SPS30 serial logged at init (sps30.c) — read via cmd 0xD033,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
    [http_server.c, main.c]
2026-05-15 V2.3.31: fix sub-tick vTaskDelay timing in I2C drivers (SHT45 H=0% root cause)
    At ESP-IDF default CONFIG_FREERTOS_HZ=100 (10 ms tick) vTaskDelay(pdMS_TO_TICKS(N))
    for N <= 10 evaluates to vTaskDelay(1), which actually sleeps 0..10 ms depending
    on call phase relative to the next tick boundary. Several driver post-command
    waits assumed millisecond precision and were silently shorter than the chip's
    conversion time, causing intermittent failures that looked like flaky hardware.
    Most visible: SHT45 returning H=0.00% with valid T (cycles 1358 + 1409 on
    esp32-5965048), or post-measure NACK ESP_ERR_INVALID_RESPONSE. SHT45 measures
    T first then H -- if the read happens at 4-9 ms the T register is f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
    [bme280.c, bmp581.c]
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2026-05-17 V2.3.33: fix /config truncation, scroll-drift, drop /log auth, harden security
    (A) /config truncation: 8KB form buffer overflowed silently on longer configs
    (different cut point per board because field-value lengths vary). Bump
    CFG_FORM_BUF_SIZE 8192 -> 16384 + ESP_LOGE guard on snprintf overrun.
    (B) Number-field accidental scroll: type=number inputs decremented their value
    when the focused input ate mouse-wheel events instead of scrolling the page
    (manifest: altitude 63.0 -> 62.8). Convert alt_m / ftp_int / tx_int_ms to
    type=text + inputmode=decimal|numeric. No spinner arrows, no wheel-step.
    (C) /log no longer auth-gated. Ring buffer is diagnostic output of the same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
    [http_server.c]
2026-05-17 V2.4.1: code-review batch — schema-driven config + atomic i64 + status snapshot + 11 more
    14 items from the V2.3.33 full code review, bundled. No functional change
    to user-visible behaviour; same NVS keys, same defaults, same /config form.
    Architecture:
    - (A1) X-macro config schema. New main/config_fields.def declares each
    field once; struct + defaults + NVS load + NVS save + POST pre-clear +
    POST dispatch all generated from it. Adding a field is now 1 line.
    - (A4) main_status_snapshot() in new main_status.h replaces 13 hand-
    extern'd getters across http_server.c, display.c, display_serlcd.c.
    - (A9) Event-driven deferred restart via EV_RESTART bit +
    main_request_restart(). Drops "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
    [config.c, display.c, display_serlcd.c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]
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2026-05-17 ci: cppcheck round-2 triage + actions/* @v5 bumps (Node 24 native)
    cppcheck round-2 (after the round-1 baseline cleanup landed):
    - display_serlcd.c: two `char line[32]` declarations at function-top
    moved inside the `if (snap->pm_valid)` branch — only used there.
    - display_serlcd.c: three `uint8_t buf[N]` declared `const` (passed
    to I2C write but never mutated post-init).
    - http_server.c: `size_t sizes[3]` declared `const` (matches the
    existing `const char *segs[3]` peer).
    - workflow: added `--suppress=unknownMacro` for MACSTR (IDF macro,
    cppcheck has no IDF headers to resolve it).
    Node.js 20 deprecation cleanup:
    - actions/checkout@v4 -> @v5 (Node 24 native)
    - actions/upload-artifa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
    [display_serlcd.c, http_server.c]
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2026-05-17 V2.4.3: MQTT Phase 2 (HA Discovery) + 2 latent warnings + PSA kconfig fix
    Adds Home Assistant MQTT Discovery so HA auto-creates one sensor
    entity per present reading on first connect. No manual YAML. Plus
    two pre-existing -Wunused-variable warnings that CI's full build
    log surfaced (V2.4.2 didnt touch those files), and the lost-since-
    v6.0 PSA key-slot count setting.
    HA Discovery (Phase 2 of 3):
    - New main/mqtt_discovery.[ch] iterates a 24-entity catalog, gates
    each on its driver *_present() function, publishes one retained
    QoS-1 config payload per present entity to
    homeassistant/sensor/geiger_<chip>/<obj>/config on every
    MQTT_EVENT_CONNECTED. Republished on every reconnect (broker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
    [display.c, i2c_bus.c]
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2026-05-17 V2.4.4: MQTT Phase 3 — /config form rows + /status row
    Completes the V2.4.2 to V2.4.4 phased MQTT rollout. Adds the web
    UI surface: 6 inputs on /config to edit the MQTT settings (enable,
    broker, port, user, password, prefix, HA-discovery), and a /status
    block showing live broker connect-state + publish count. No new
    MQTT functionality — purely makes the existing client configurable
    + observable through the web UI instead of requiring NVS tool
    access.
    http_server.c:
    - New format_mqtt() block in the same style as format_uploads /
    format_noise / format_pm_info. Skipped entirely when MQTT is
    disabled, so the block only appears for users who opted in.
    - New "MQTT (Home Assistant / Mosqui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
    [http_server.c]
2026-05-17 ui(config): expand MQTT LWT description on /config page
    "Availability flips offline via LWT when the device drops" was too
    terse — readers without MQTT background had no way to know what
    LWT meant or why it mattered. Replaced with an explanation of:
    - what triggers it (abrupt drop: power, WiFi, crash)
    - what the broker does (publishes "offline" on the devices behalf)
    - what HA does in response (entity flips to unavailable within ~90s)
    - why we care (HA otherwise shows stale readings as fresh)
    No code-path change. Will ship with the next tagged release.
    [http_server.c]
2026-05-18 V2.4.5: Heltec V2 heap headroom — mbedTLS dynamic buffer + smaller log ring
    Two independent tweaks targeting the constrained-DRAM Heltec V2 build.
    Lifetime min-free-heap during TLS-handshake transients sat at ~5.6 KB
    against ~100 KB idle — close to the edge for future feature growth.
    Together these lift that floor by ~30 KB without changing any
    externally-visible behaviour.
    - CONFIG_MBEDTLS_DYNAMIC_BUFFER=y (Heltec overlays only): mbedTLS now
    allocates SSL IN/OUT record buffers on demand and frees the ~16 KB
    handshake scratch post-handshake. FeatherS3-D / QT Py have abundant
    PSRAM heap and skip this to avoid the per-record alloc/free overhead.
    - HAL_LOG_RING_BYTES 60 KB -> 45 KB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
    [hal.h]
2026-05-18 V2.4.6: MQTT TLS to broker — three configurable trust modes
    Adds mqtts:// transport for the publish-only MQTT client (V2.4.2-V2.4.4
    was plain-1883 only). User picks the trust model via new /config dropdown:
    - Mode A (default) — Mozilla CA bundle (esp_crt_bundle_attach, reuses
    the same bundle baked in for HTTPS uploads). For public-CA brokers
    (Let's Encrypt etc).
    - Mode B — Custom CA cert pasted into /config textarea, stored verbatim
    in NVS as mqtt_tls_ca, passed via verification.certificate. For
    self-signed Mosquitto (typical HA add-on case).
    - Mode D — Skip server verification. TLS encryption on the wire, no
    cert authentication. Trusted-LAN only.
    Mode C (fingerprint pinn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
    [hal.h, http_server.c]
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
